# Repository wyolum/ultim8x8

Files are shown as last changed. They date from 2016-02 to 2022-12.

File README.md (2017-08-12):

# ultim8x8

ultim8x8 is an APA102 RGB LED based panel consisting of 8x8 matrix. Panels can be chained to produce larger matrices. Besides +5V and GND, each board requires a CLocK and DATa signal. Each board has CLocK and DATa IN and OUT terminals. When cascading boards, the OUT from one board goes to the IN of the next board.

Each LED can require up to 60mA current at 5V for White light at full brightness. This means driving ALL the 64 LEDs at full brightness White color will require 3.8A Amps. You can get away with lower Amps if you drive LEDs at lower brightness or don't light them all up at the same time.

Boards can be cascaded using several methods. Simplest, which requires no soldering, is to screw in the supplied metal posts to the terminals marked +5V, GND, DI__A, CI__A, DO__H and CO__H. The Boards can then be interconnected using the ultim_BUS busbar, or copper tape stuck over a piece of acrylic.

When running at low Amps or driving a single board, the 4 pin 0.1" pitch header can be used.

## kicad

* [ultim8x8_v0](/kicad/ultim_8x8_v0) - first version, Main hardware design files. Schematic, Layout etc. (deprecated)
* [ultim8x8_v1](/kicad/ultim_8x8_v1) - second version, Main hardware design files. Schematic, Layout etc. (deprecated)
* [ultim8x8_v2](/kicad/ultim_8x8_v2) - third version, Main hardware design files. Schematic, Layout etc. (current)

* [ultim_bus_v1](/kicad/ultim_bus_v1) - first version, Hardware design files for a bus bar to inter-connect ultim8x8's (deprecated)
* [ultim_bus_v2](/kicad/ultim_bus_v2) - second version, Hardware design files for a bus bar to inter-connect ultim8x8's (deprecated)
* [ultim_bus_v3](/kicad/ultim_bus_v3) - third version, Hardware design files for a bus bar to inter-connect ultim8x8's (deprecated)
* [ultim_bus_v4](/kicad/ultim_bus_v4) - fourth version, Hardware design files for a bus bar to inter-connect ultim8x8's (deprecated)
* [ultim_bus_v5](/kicad/ultim_bus_v5) - fifth version, Hardware design files for a bus bar to inter-connect ultim8x8's (current)

* [ultim_bus_conn](/kicad/ultim_bus_conn) - connector strips to join multiple ultim__bus_bars

* [featherboard](/kicad/featherboard) - first version, Interface board to connect Adafruit Feather Huzzah board to ultim8x8
* [feather_v2](/kicad/feather_v2) - second version, Interface board to connect Adafruit Feather Huzzah board to ultim8x8
* [feather_v3](/kicad/feather_v3) - third version, Interface board to connect Adafruit Feather Huzzah board to ultim8x8

* [ultim8x8_data](/kicad/ultim8x8_data) - Data sheets, logos etc

## fabricate

* [buckle](/fabricate/buckle) - 3D CAD files for a Belt Buckle.
* [featherboard_case](/fabricate/featherboard_case) - 3D CAD files for a "wireless" ultim8x8 brick

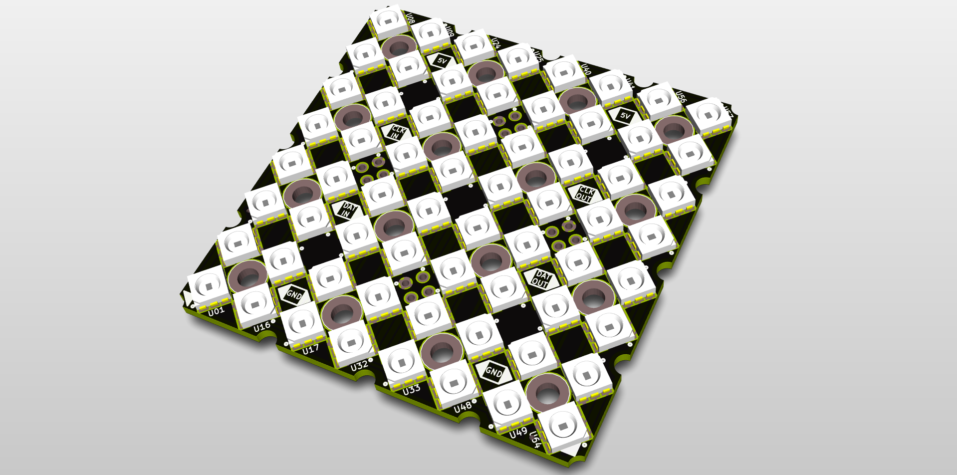
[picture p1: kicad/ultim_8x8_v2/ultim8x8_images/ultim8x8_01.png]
ultim8 top


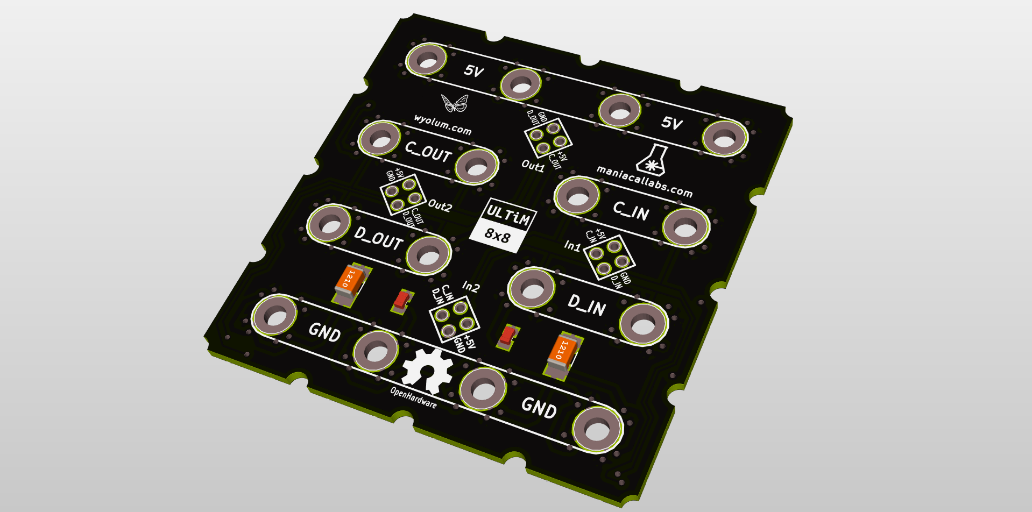
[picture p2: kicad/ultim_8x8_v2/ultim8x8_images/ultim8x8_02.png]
ultim8 bottom


License
-------
[CERN Open Hardware Licence v1.2 ]

[CERN Open Hardware Licence v1.2 ]:http://www.ohwr.org/attachments/2388/cern_ohl_v_1_2.txt

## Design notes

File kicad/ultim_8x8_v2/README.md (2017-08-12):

# ultim_8x8

ultim8x8 is an APA102 RGB LED based panel consisting of 8x8 matrix. Panels can be chained to produce larger matrices. Besides +5V and GND, each board requires a CLocK and DATa signal. Each board has CLocK and DATa IN and OUT terminals. When cascading boards, the OUT from one board goes to the IN of the next board.

Each LED can require up to 60mA current at 5V for White light at full brightness. This means driving ALL the 64 LEDs at full brightness White color will require 3.8A Amps. You can get away with lower Amps if you drive LEDs at lower brightness or don't light them all up at the same time.

Boards can be cascaded using several methods. Simplest, which requires no soldering, is to screw in the supplied metal posts to the terminals marked +5V, GND, D_IN, C_IN, D_OUT and C_OUT. The Boards can then be interconnected using the ultim_BUS busbar, or copper tape stuck over a piece of acrylic.

When running at low Amps or driving a single board, the 4 pin 0.1" pitch headers can be used. There are two pairs of headers marked In1/Out1 and In2/Out2.

ultim_8x8 top

ultim_8x8 top

License
-------
[CERN Open Hardware Licence v1.2 ]

[CERN Open Hardware Licence v1.2 ]:http://www.ohwr.org/attachments/2388/cern_ohl_v_1_2.txt

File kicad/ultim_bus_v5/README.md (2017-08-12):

# ultim_bus

A PCB "bus bar" to allow three ultim8x8 modules to be connected easily. Mouse bites allow it to be snapped off easily. With some imagination, can be used to expand to larger matrices.

The first panel can be populated with a Huzzah. There are six SMD switches connected to 14, 12, 13, 15, 0, 16, 2 on the Huzzah, with pull up resistors (SMD 0805). Switch functions can be arbitrarily assigned in code.

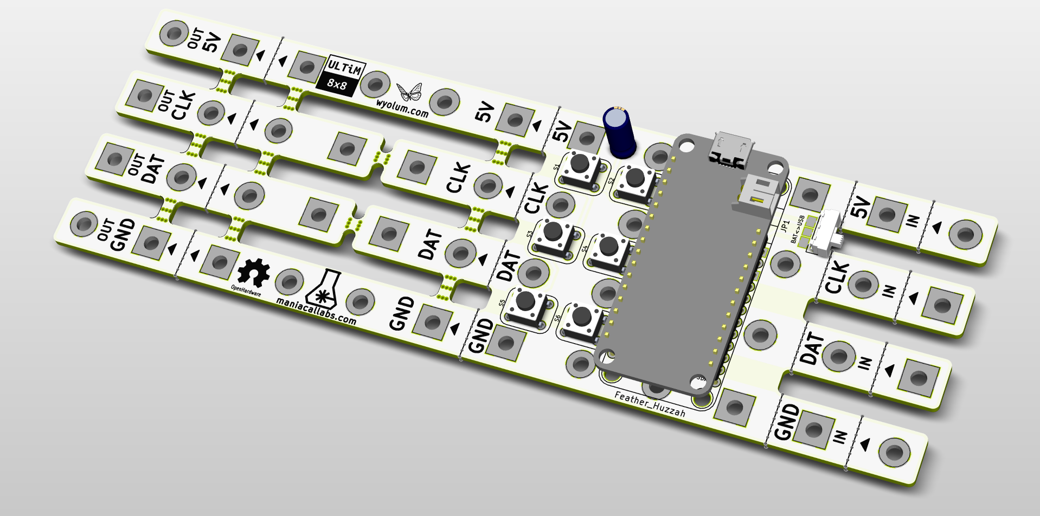
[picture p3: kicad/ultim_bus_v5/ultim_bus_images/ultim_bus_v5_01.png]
ultim_bus top


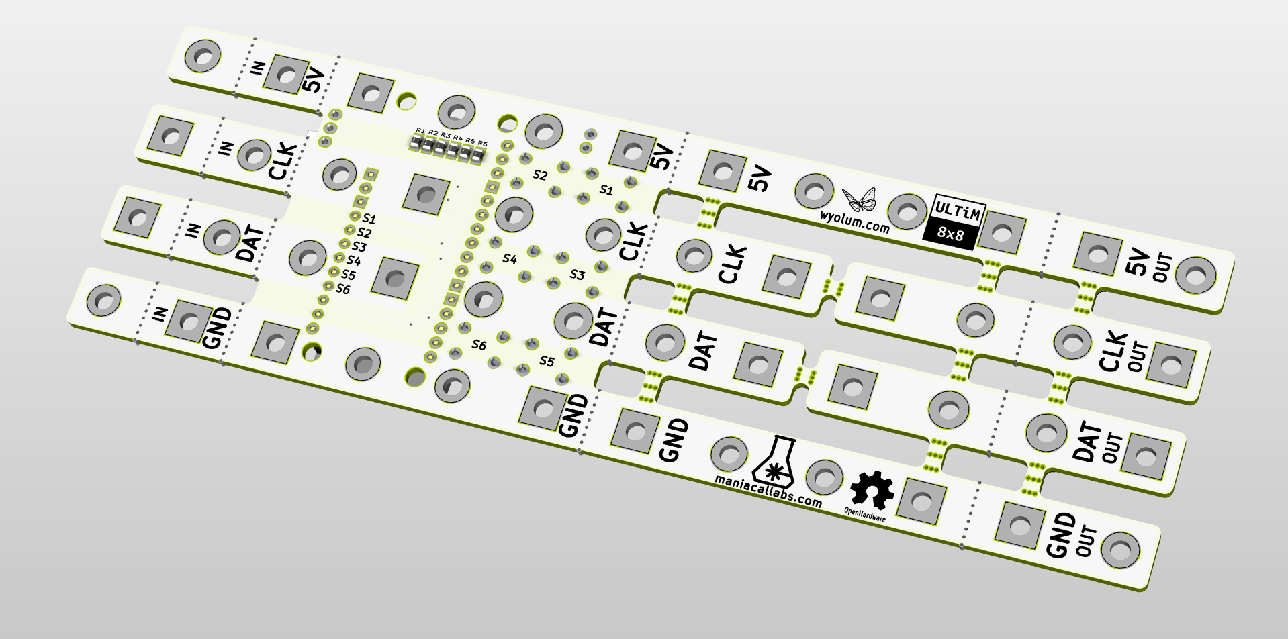
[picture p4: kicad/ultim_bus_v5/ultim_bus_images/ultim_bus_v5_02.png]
ultim_bus top


License
-------
[CERN Open Hardware Licence v1.2 ]

[CERN Open Hardware Licence v1.2 ]:http://www.ohwr.org/attachments/2388/cern_ohl_v_1_2.txt

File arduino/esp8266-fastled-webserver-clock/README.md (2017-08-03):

Ultim8x8 RGB LED Panel + FastLED + ESP8266 Web Server
=========

Control an [ULTiM8x8 RGB LED Panel] with an ESP8266 via a web browser.

[Demo Video](https://www.youtube.com/watch?v=xigy7J_K7Aw):

Demo Video (http://www.youtube.com/watch?v=xigy7J_K7Aw)

Hardware
--------

[Adafruit Feather HUZZAH with ESP8266 WiFi]

Adafruit Feather HUZZAH with ESP8266 WiFi (https://www.adafruit.com/products/2821)

[ULTiM8x8 RGB LED Panel]

ULTiM8x8 RGB LED Panel (https://www.crowdsupply.com/maniacal-labs-wyolum/ultim8x8)

Features
--------
* Turn the LEDs on and off
* Adjust the brightness
* Change the display pattern
* Adjust the color

Web App
--------

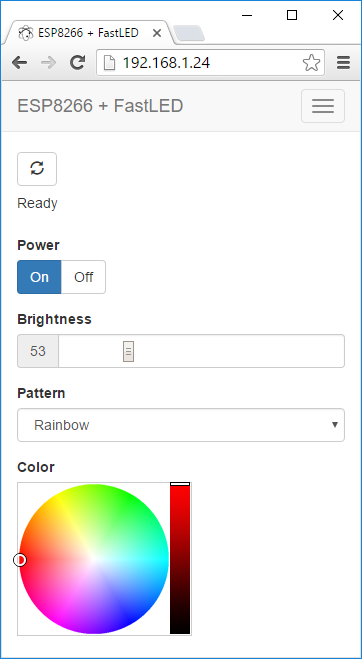
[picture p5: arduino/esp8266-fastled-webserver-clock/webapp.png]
Web App


Patterns are requested by the app from the ESP8266, so as new patterns are added, they're automatically listed in the app.

The web app is stored in SPIFFS (on-board flash memory).

The web app is a single page app with separate files for js and css, using [jQuery](https://jquery.com) and [Bootstrap](http://getbootstrap.com).  It has buttons for On/Off, a slider for brightness, a pattern selector, and a color picker (using [jQuery MiniColors](http://labs.abeautifulsite.net/jquery-minicolors)).  Event handlers for the controls are wired up, so you don't have to click a 'Send' button after making changes.  The brightness slider and the color picker use a delayed event handler, to prevent from flooding the ESP8266 web server with too many requests too quickly.

Installing
-----------

The web app needs to be uploaded to the ESP8266's SPIFFS.  You can do this within the Arduino IDE after installing the [Arduino ESP8266FS tool](https://github.com/esp8266/Arduino/blob/master/doc/filesystem.md#uploading-files-to-file-system).

With ESP8266FS installed run the sketch and then upload the web app using `ESP8266 Sketch Data Upload` command in the Arduino Tools menu.

Compression
-----------

The web app files can be gzip compressed before uploading to SPIFFS by running the following command:

`gzip -r data/`

The ESP8266WebServer will automatically serve any .gz file.  The file index.htm.gz will get served as index.htm, with the content-encoding header set to gzip, so the browser knows to decompress it.  The ESP8266WebServer doesn't seem to like the Glyphicon fonts gzipped, though, so I decompress them with this command:

`gunzip -r data/fonts/`

REST Web services
-----------------

The firmware implements basic [RESTful web services](https://en.wikipedia.org/wiki/Representational_state_transfer) using the ESP8266WebServer library.  Current values are requested with HTTP GETs, and values are set with POSTs using query string parameters.  It can run in connected or standalone access point modes.

[ULTiM8x8 RGB LED Panel]:https://www.crowdsupply.com/maniacal-labs-wyolum/ultim8x8
[Adafruit Feather HUZZAH with ESP8266 WiFi]:https://www.adafruit.com/products/2821

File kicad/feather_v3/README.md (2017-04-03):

# feather_v3

An add-on board to the Ultim8x8 LED Matrix for mounting an Adafruit Feather M0.

Use 4 pin male headers on ultim8x8 at either of two possible locations -- Input1/Output1 or Input2/Output2

Use a 2.54mm pitch slide switch/header+jumper mounted either at JP1 or JP2, to select between USB supply or BAT (external LiPo).

Instead of using a Switch, use shorting pads near the switch pads to permanently select one of the two supply options - USB or BAT.

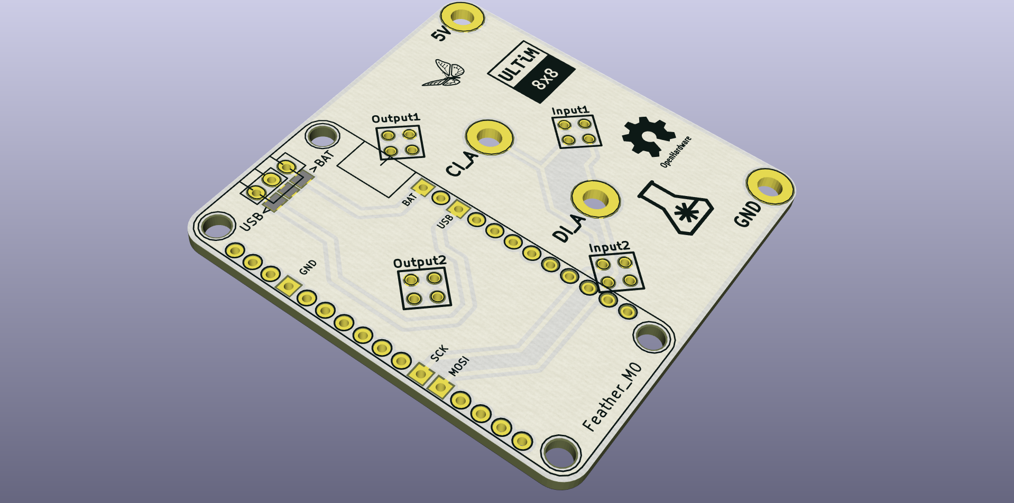
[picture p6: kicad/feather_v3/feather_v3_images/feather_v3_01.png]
Feather board top


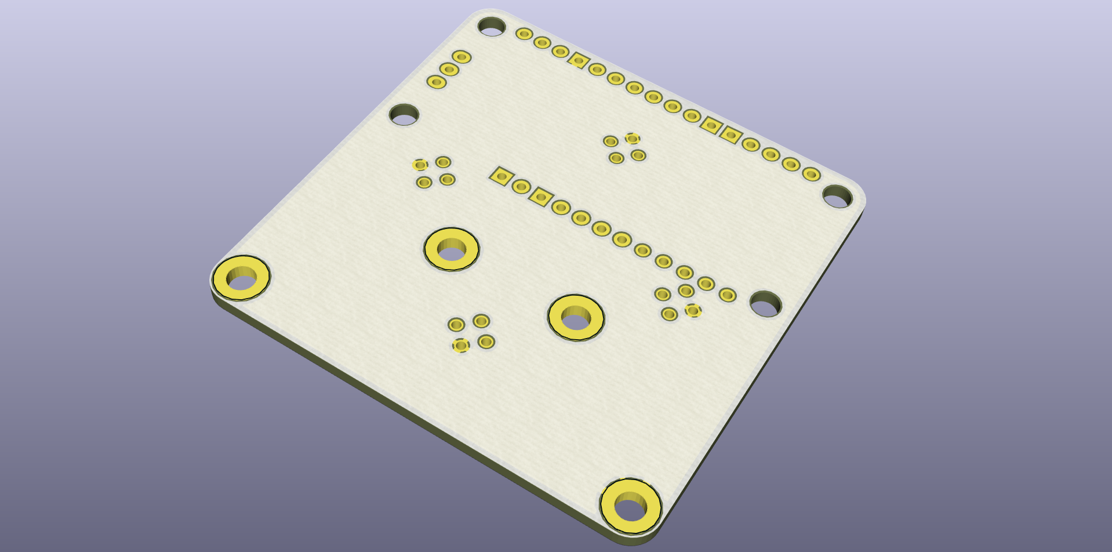
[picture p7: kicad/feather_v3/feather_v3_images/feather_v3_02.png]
Feather board bot


License
-------
[CERN Open Hardware Licence v1.2 ]

[CERN Open Hardware Licence v1.2 ]:http://www.ohwr.org/attachments/2388/cern_ohl_v_1_2.txt

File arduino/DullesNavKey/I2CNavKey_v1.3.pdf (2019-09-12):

www.duppa.net

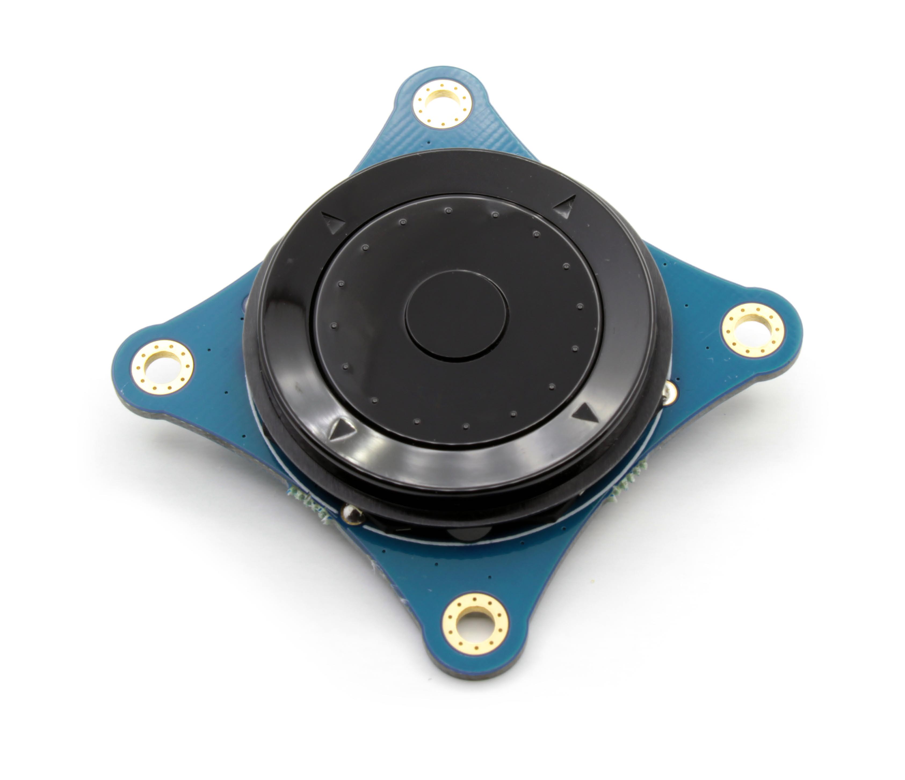
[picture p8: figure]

# I2CNavKey

## HW V1.1

August 1, 2019

Document written in LATEX

www.duppa.net | I2CNavKey

# Revision History

Revision | Date | Author(s) | Description
1.3 | 01.08.19 | Simone | Small changes on this document layout
1.2 | 09.07.19 | Simone | Fixed the numbering of the gamma type
1.1 | 26.05.19 | Simone | Added the pull-up resistors jumpers and new photos
1.0 | 08.04.19 | Simone | First version

# Contents

1 Device Overview | 3
2 Registers | 13
3 Reference | 28
4 Issues | 29
5 Schematic | 30

# 1. Device Overview

The I2CNavKey is a small board that includes a 7 functions joypad.
The joypad has 4 directional keys plus a central button and a rotary ring. It is controllable with the I²C bus, and it’s possible to configure 16 different I²C addresses.

The I2CNavKey has also 3 configurable GPIOs with the same footprint of RGB LED. This 3 GPIOs can be configured independently in 4 different way: input, output, PWM and analog input.

Since the I2CNavKey is a I²C slave, it has a series of 8 bit registers where it’s possible to configure different parameters, it’s also possible to detect when the buttons are pressed or when the ring is rotated.
It also has an open-drain output pin used as interrupt output. This pin is used to notify to the master when some event happens in the I2CNavKey, the source of interrupt can be customized.

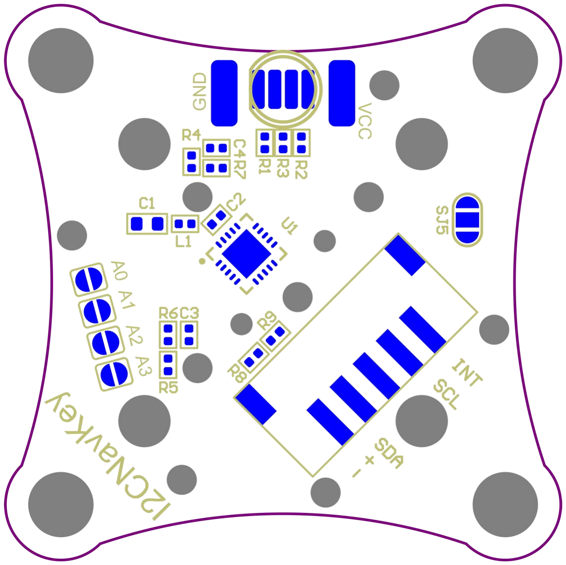
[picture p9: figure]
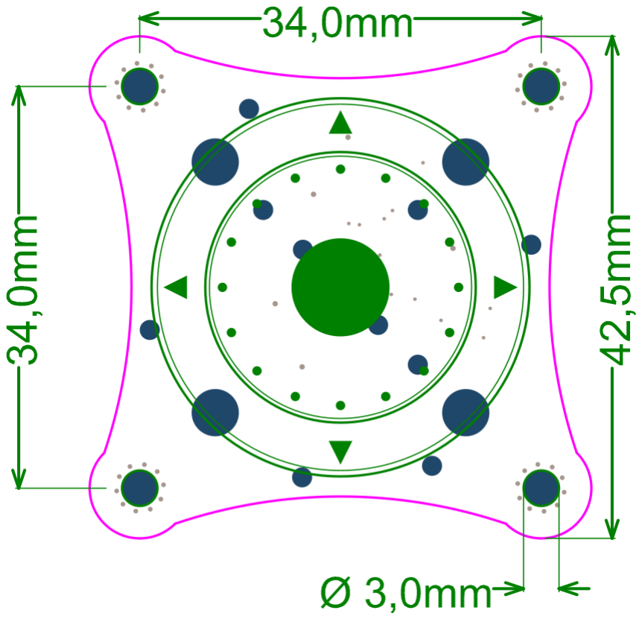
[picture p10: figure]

Figure 1.1: Dimension | Figure 1.2: Bottom view of the board

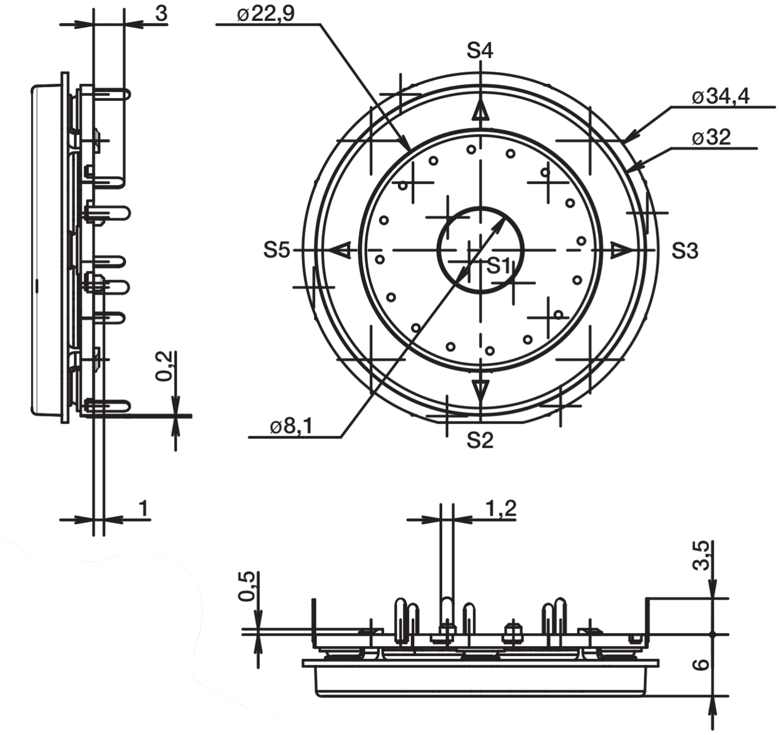
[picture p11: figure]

Figure 1.3: Dimension of the joypad: TSWB-3N-CB222 LFS from C&K

## 1.1 Electrical characteristics

Parameter | Symbol | Min | Max
Supply voltage | VDD | 3V | 5V
2C input-low level I | VIL | 0 | 0.3 * VDD
2C input-high level I | VIH | 0.8 * VDD | VDD
2C clock input frequency I | fSCL | | 400kHz
Supply current (LEDs off) | IDD | | 1.8mA
Interrupt pull-up resistor | RINT | 15kΩ | 120kΩ

## 1.2 Connection

Figure 1.4 shows the pin-out of the I2CNavKey.

Pin | I/O Type | Function
GND | Power | Ground reference for logic
Vcc | Power | Positive supply for logic
SDA | I/O | 2C data I
SCL | I | 2C clock I
INT | OD | Open-drain interrupt output

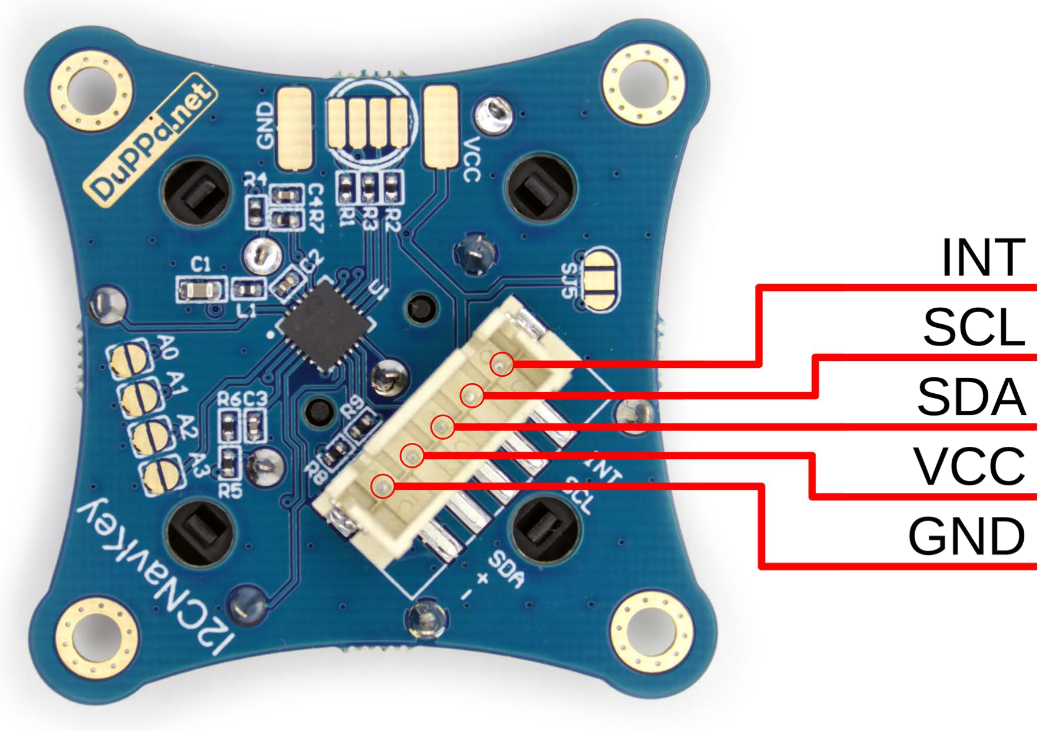
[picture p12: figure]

Figure 1.4: Pinout of the board

There are a 5 pins JST XH connector where it is possible to connect the I2CNavKey to the master. In order to avoid I

2C address conflict with other devices on the bus, the address of each device must be different. In the section 1.3, it is described how to set the address.

## 1.3 I

## 2C interface

The I2CNavKey is a I²C slave, it’s possible to the set 16 different addresses. All of the 7-bit address can be customized by soldering the jumpers A0 - A3 on the bottom of the board. When the jumper is open, it means a logic 0. if jumper is shorted it means a logic 1.

I

2C address

7 | 6 | 5 | 4 | 3 | 2 | 1 | 0
0 | 0 | 1 | A3 | A2 | A1 | A0 | R/W

For example in the figure 1.6 the jumper A0 and A2 are shorted and the 7-bit I²C address is 21 in decimal or 0x15 in hexadecimal or 0b00010101 in binary.

The I2CNavKey has I²C pull-up resistors, by default they are not enabled. In order to enable the resistor the jumper SJ5 must be soldered.
This must be done in case that the master doesn’t have these resistors and must be enabled only one I2CNavKey in a chain. A typical value of this resistors are 4.7kΩ.
In the figure 1.6 is showed how to short the jumper SJ5.

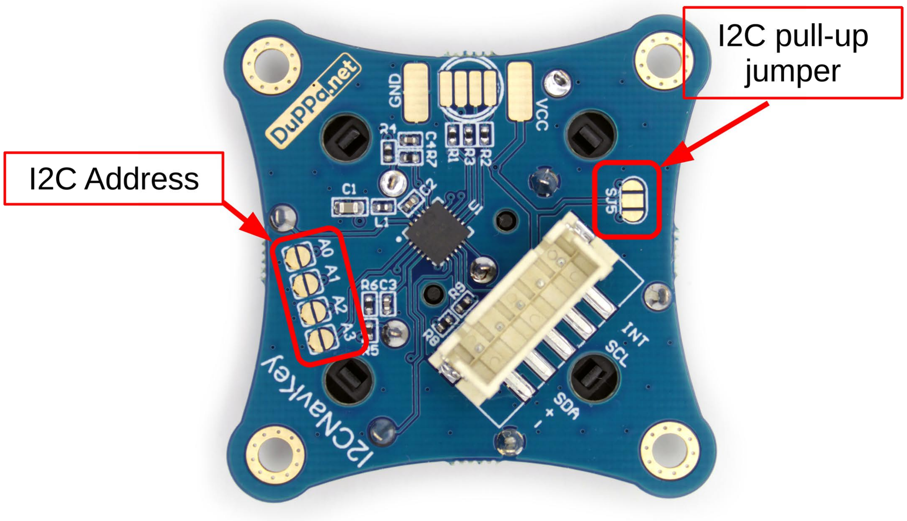
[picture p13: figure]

Figure 1.5: Jumper location of the pull-up resistor and of the address

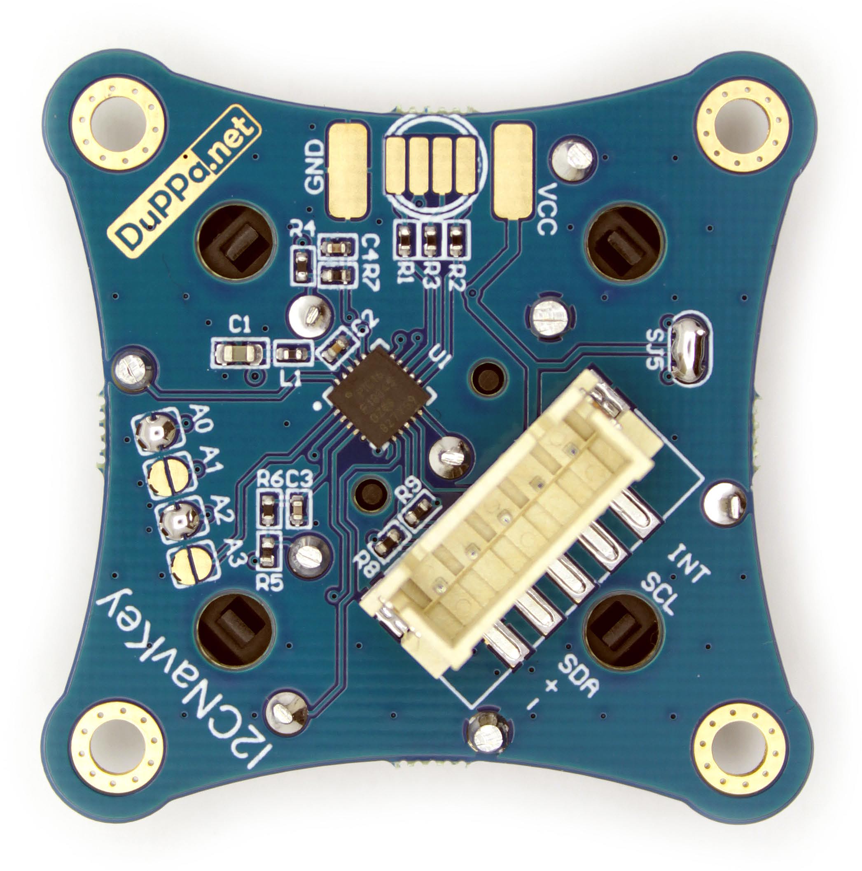
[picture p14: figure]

Figure 1.6: Example of jumper soldered: A0 and A2 shorted and also the SJ5 is shorted enabling the pull-up resistors

## 1.4 Joypad

On the I2CNavKey, there is a joypad with 7 functions:

- 4 directional buttons: up, down, left and right
- 1 central button
- Central wheel that can be rotated left and right, and it has 12 pulses per rotation.

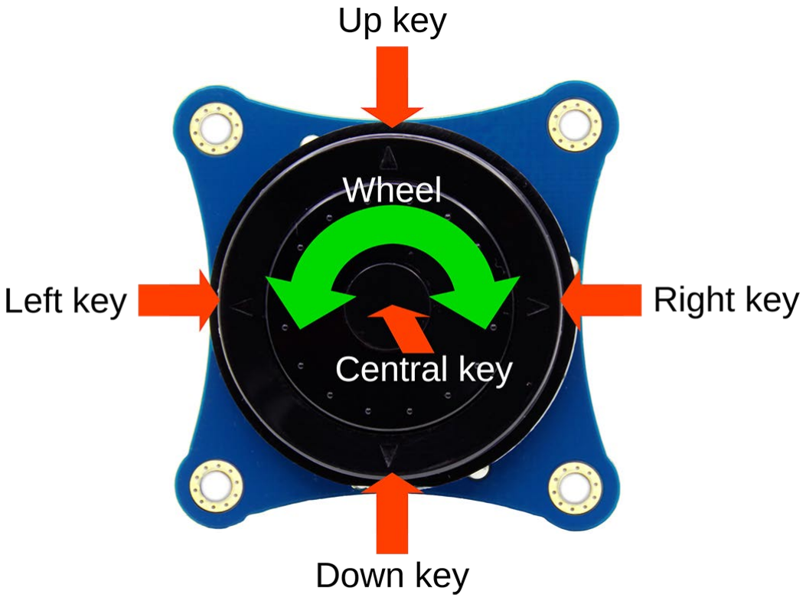
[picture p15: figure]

Figure 1.7: 7 function of the joypad

### 1.4.1 Buttons

When a button is pressed, the specific bit is set in the register ISTATUS. Every button has 2 specific bits because it’s possible to detect when the button is pressed and when is released.
The central button has also the possibility to read a fast double push by setting a window time in the register DPPERIOD. When a double push is made inside of the DPPERIOD window, the bit SCTRDP is set and it is possible to read in the ISTATUS register.
If the DPPERIOD is 0, the double push function is disabled.

### 1.4.2 Encoder

For reading the rotary encoder movement, there are 4 of 32bit registers: CVAL, CMAX, CMIN and ISTEP. All of these 4 registers can be configured to work as 32bit int or as IEEE 754 floating number, this format can be set in the GCONF register.
The counter limits are the following:
- 32bit INT: from −2147483648 to +2147483647
- IEEE 754 float: from −126.0 to +127.0

In case of 32bit int, it is not necessary to read all the 4 bytes, you can read only the first 8 bit or the first 16 bit. For example, if you want to count between 0 and 10, you can read only the first byte of the CVAL register. In this way, you can save I2C transactions.
Every time the encoder moves one step, the value of the CVAL register is increased or decreased of the value of ISTEP. The direction of the rotation decides if ISTEP is added or subtracted from CVAL.
CMAX and CMIN are used for setting a minimum and maximum thresholds of CVAL. In the GCONF register, there is WRAPE bit. This bit is used to enable or disable a wrap functionality of CVAL when it exceeds from the thresholds.
For example, if i configure the I2CNavKey as following:
- CVAL= 0
- CMAX = 5
- CMIN = -5
- ISTEP= 1

I will have CVAL is incremented of 1 at each rotation step of the encoder. The maximum value that CVAL can reach will be 5 while the minimum is -5. In the figure 1.8 shows the value of CVAL.

As showed in the figure 1.9, when WRAPE is set to 1 when CVAL reaches the value of 5, at the next increment CVAL it will be wrapped to -5.
Every time when the encoder is rotated one step and when CVAL reaches the thresholds, an interrupt is generated and it is possible to read in the register ISTATUS.

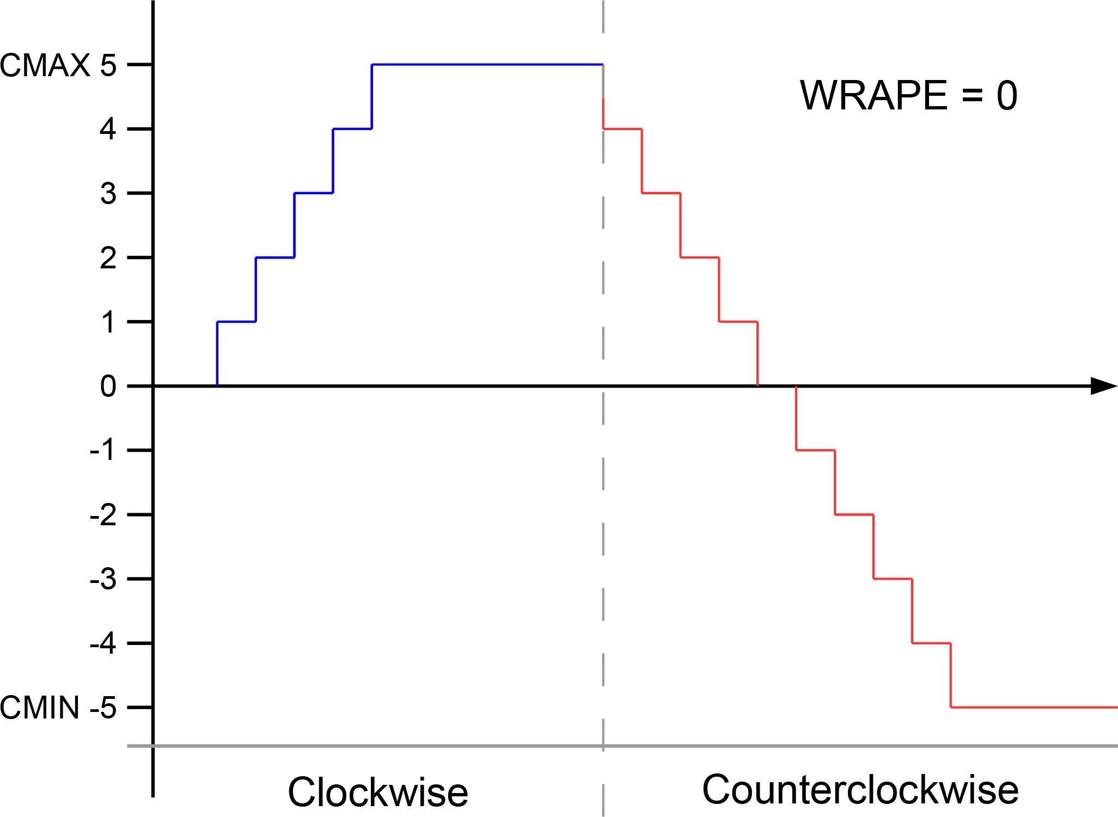
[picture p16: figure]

Figure 1.8: Blue and red lines are the CVAL values when the encoder is rotated and the WRAPE is disabled

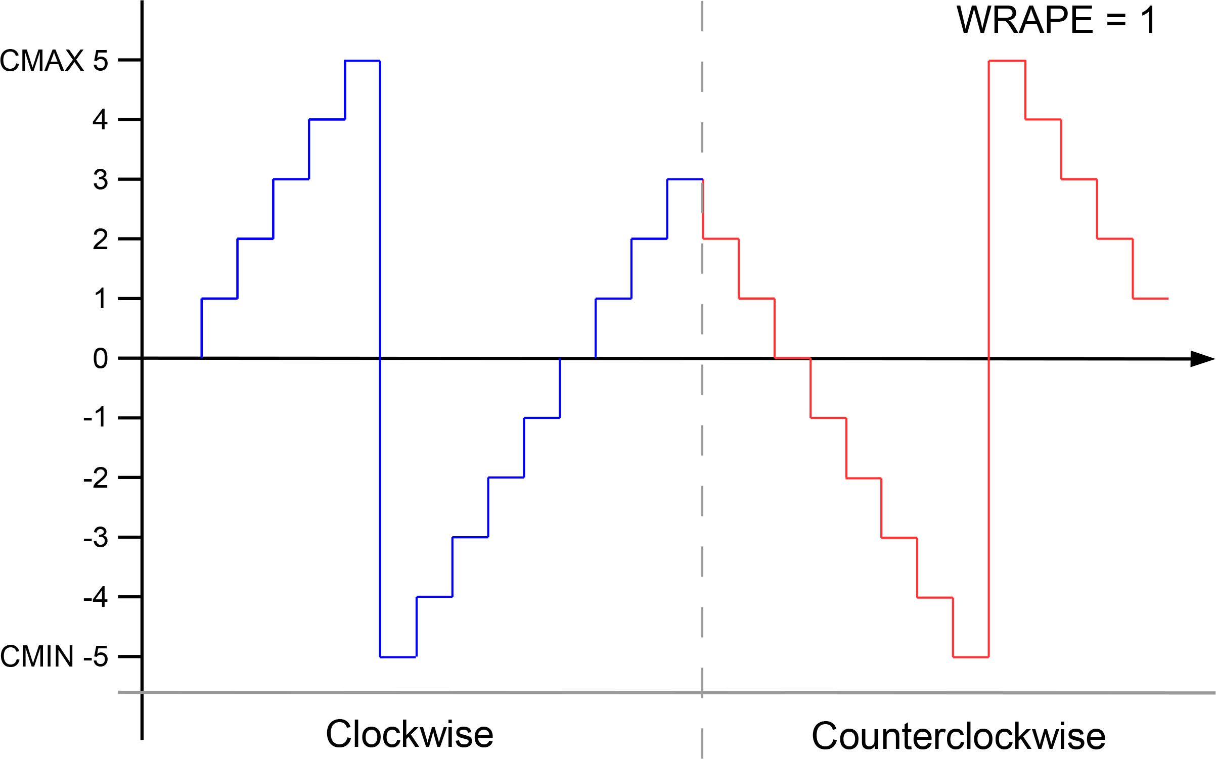
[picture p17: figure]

Figure 1.9: Blue and red line are the CVAL values when the encoder is rotate and the WRAPE is enabled

## 1.5 GP pins

There are 3 configurable GP pins, they are called GP1, GP2 and GP3. They have the same footprint of an 5mm RGB led. In figure 1.10, it is shown the position. Each pin can be configured to be:

- PWM: The pins is configured to be a PWM output.
- Analog input: The pins is configured to be an input of the internal ADC.
- GPIO output: The pins is configured to be a digital output.
- GPIO Input: The pin is configured to be a digital input.

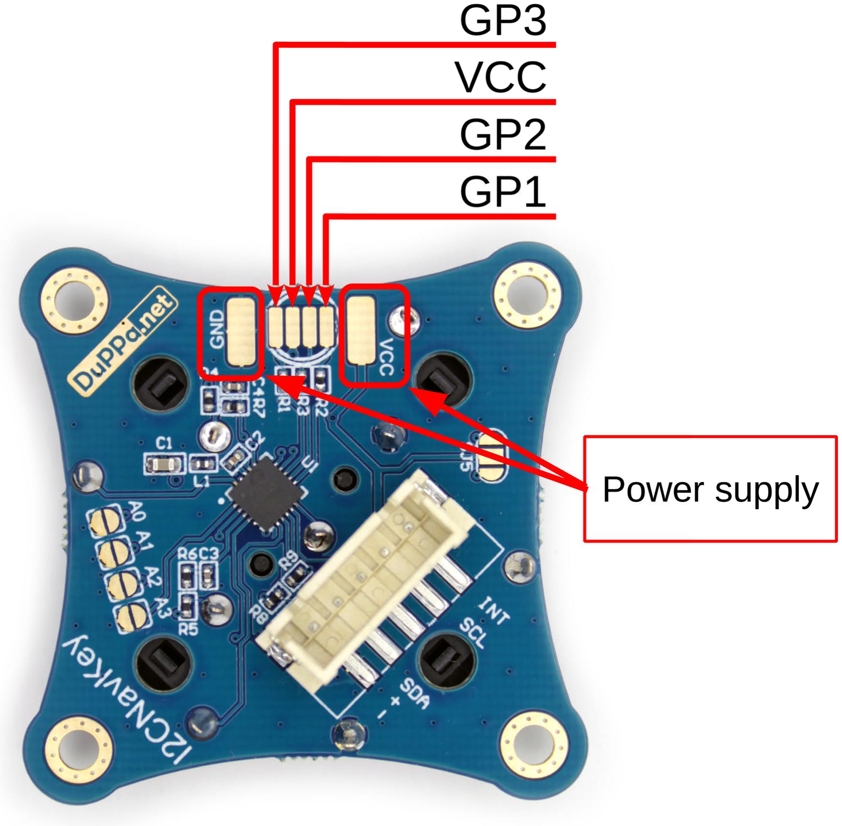
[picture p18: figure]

Figure 1.10: GP pins pinout

### 1.5.1 PWM mode

A GP pins can be configured in PWM mode by configuring the GPxMODE 1
to 0x00. The default configuration of the GP pins at the start up is PWM. Once the GP pin is configure in PWM mode, it is possible to set the PWM value by writing the corresponding GPxREG.
The PWM is resolution 10bit with a frequency of 31.25kHz, but the user can not access to the full resolution. It is possible to set a PWM value between 0% to 100% by writing 0 to 100 to the GPxREG.
The PWM is inverted, this means that when the PWM is 0% the GP pin voltage is VCC while when it is 100% the GP pin is GND.
In this way it is possible to connect a common anode RGB LED and have the LED off when the PWM is 0 and full on when the PWM is 100.
To each PWM outputs it is possible to configure a specific gamma correction by writing the register GAMMAGPx. There are 7 type of gamma correction:

✥ Gamma 1 (linear)

✥ Gamma 1.8

✥ Gamma 2.0

✥ Gamma 2.2

✥ Gamma 2.4

✥ Gamma 2.6

✥ Gamma 2.8

In the figure 1.11 is showed the relationship between the PWM at the full resolution and the PWM settable from the user.

1
In a register name the x correspond to 1, 2 or 3

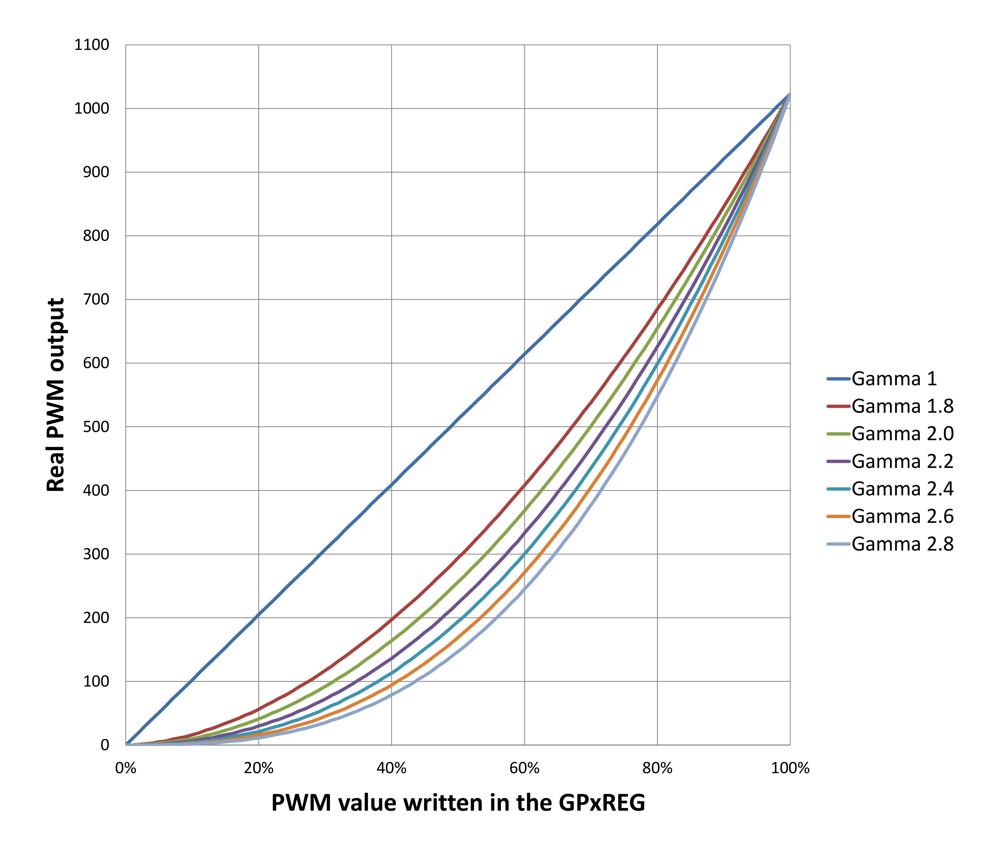
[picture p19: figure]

Figure 1.11: Possible gamma option

Fade function

The I2CNavKey has an auto fading features.
There is the register FADEGP, the value you write inside these registers is the step speed of the fading ramp, and it’s in ms. The fading will follow the selected gamma correction. If the value is 0, the fade feature is disabled. It means that when the new value of PWM is written, it is immediately updated to the output.
The fading process starts when a PWM value is written. Fading process is complete according to the PWM value you have set. When the internal fade PWM value is the same of the PWM value (it means that when fading is complete), an interrupt will be generated. Let’s make an example:

At the startup, i write as:

- GP1REG = 0
- GP2REG = 0
- GP3REG = 0
- FADEGP = 1

In above case, the LEDs of the encoder are off and the fade has 1ms step size.
Now i write as: GP1REG=100.
This moment, the ramp of the GP1REG starts and reaches the value 0x100 in 100ms. (the other LEDs remain OFF) When the ramp reaches 100, i get an interrupt from the INT pin.
After this, i write as: GP1REG=0x00. At this point, the fade ramp starts again and it will turn off the LED in 100ms, and an interrupt will be generated at the end.
The figure 1.12 is showing an example of the fade output when a PWM value is written in different moments, as well as when the interrupt of the fade is generated.

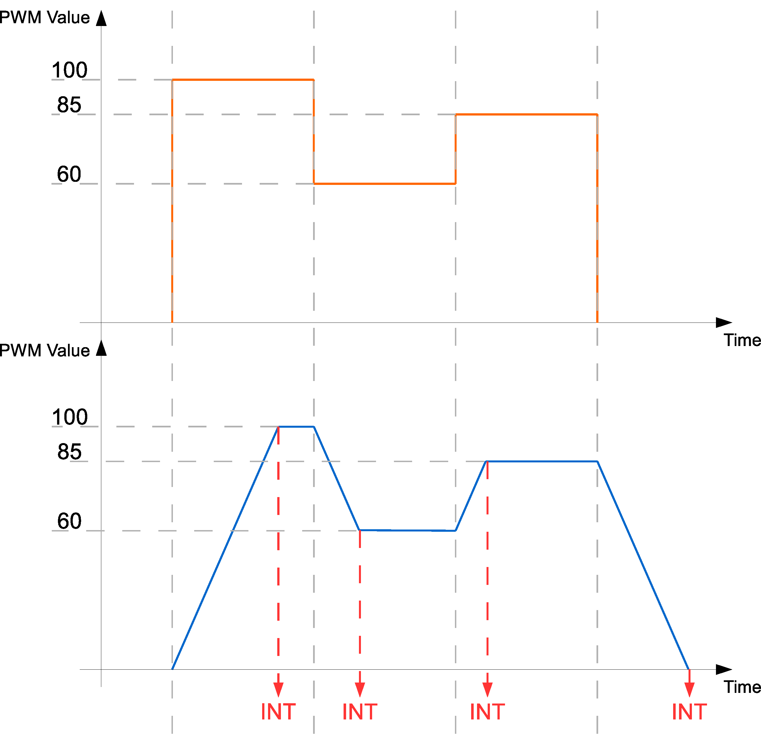
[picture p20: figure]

Figure 1.12: Time diagram of the fade output when writing on the PWM register

### 1.5.2 OUT mode

A GP pin can be configured as output mode by configuring the GPxMODE to 0x01. When the pin is configured as output writing 1 to GPxREG it make the GP pin high, while writing 0 make the pin low.

### 1.5.3 ADC mode

A GP pin can be configured as ADC mode by configuring the GPxMODE to 0x02. It is possible to read the ADC value by reading the register GPxREG. The content of the register updates every 10ms. When the GP pin is tied to 0 the ADC value is 0, while when the GP pin is tied to VCC the ADC value is 255. In this case it is also possible to enable the internal pull-up by writing 1 in the GPxPUL field.

### 1.5.4 IN mode

A GP pin can be configured as input mode by configuring the GPxMODE to 0x03. In this case, it is also possible to enable the internal pull-up by writing 1 in the GPxPUL field. It is also possible to configure the GP pin to generate an interrupt when the signal change. In the field GPxINT it possible to enable the interrupt when there is a positive edge, negative edge or both. The interrupt can be read in the register I2STATUS.It can be also reported to the INT pin by enabling the SINT2L bit.

## 1.6 EEPROM

The I2CNavKey has 256 bytes of EEPROM.
This memory is divided in two banks of 128 bytes. With the bit MBANK in the GCONF register, it is possible to choose either the bank 1 or the bank 2.
The memory area is between 0x80 and 0xFF address. To use the EEPROM, user only needs to perform reading or a writing in these address areas.
The writing time takes 4 - 5ms to be executed. Wait this time before sending other commands.

## 1.7 Interrupt

The I2CNavKey has multiple interrupt source previously described. When an interrupt is generated, the INT pin is tied low. By reading the register ISTATUS, the interrupts are cleared and the INT pin returns high.

The INT pin is open-drain output. Hence it requires an external pull-up resistor, or internal pull-up resistor can be enabled by setting the bit IPUD to 1.
In a chain of I2CNavKey all the INT pins can be connected together, like the pin of the I²C. When an interrupt occurs, user has to scan the boards in the chain to find who generates the interrupt.
With the register INTCONF, it is possible to enable or disable interrupt. When an interrupt is disabled, the corresponding bit is set, but the INT pin is not affected.

# 2. Registers

In this section, the internal registers of I2CNavKey is described.
The I2CNavKey has the auto increment feature. This means that after writing or reading a register, the internal address pointer is automatically incremented by one.
Address range | Name | Description | Dimension | Default value
0x00 | GCONF | General Configuration | 1 Byte | 0
0x01 | GP1CONF | GP 1 Configuration | 1 Byte | 0
0x02 | GP2CONF | GP 2 Configuration | 1 Byte | 0
0x03 | GP3CONF | GP 3 Configuration | 1 Byte | 0
0x04 0x05 | INTCONF | INT pin Configuration | 2 Byte | 0
0x06 - 0x07 | ISTATUS | Interrupt Status | 2 Byte | 0
0x08 | I2STATUS | Secondary interrupt status | 1 Byte | 0
0x09 | FSTATUS | Fade process status | 1 Byte | 0
0x0A - 0x0D | CVAL | Counter Value | 4 Byte | 0
0x0E - 0x11 | CMAX | Counter Max value | 4 Byte | 0
0x12 - 0x15 | CMIN | Counter Min value | 4 Byte | 0
0x16 - 0x19 | ISTEP | Increment step value | 4 Byte | 1
0x1A | GP1REG | I/O GP1 register | 1 Byte | 0
0x1B | GP2REG | I/O GP2 register | 1 Byte | 0
0x1C | GP3REG | I/O GP3 register | 1 Byte | 0
0x1D | DPPERIOD | Double push period | 1 Byte | 0
0x1E | FADEGP | Fade timer step of GPs ports | 1 Byte | 0
0x1F | GAMMAGP1 | Gamma correction on PWM of GP1 | 1 Byte | 0
0x20 | GAMMAGP2 | Gamma correction on PWM of GP2 | 1 Byte | 0
0x21 | GAMMAGP3 | Gamma correction on PWM of GP3 | 1 Byte | 0
0x70 | IDCODE | I2CNavKey unique code | 1 Byte | 0x5B
0x71 | VERSION | I2CNavKey version | 1 Byte | 0x11
0x80 - 0xFF | EEPROM | EEPROM memory | 128 Byte | 0

## 2.1 Configuration

### 2.1.1 General Configuration

GCONF Address: 0x00
7 | 6 | 5 | 4 | 3 | 2 | 1 | 0
R/W-0 | R/W-0 | R/W-0 | R/W-0 | R/W-0 | R/W-0 | R/W-0 | R/W-0
RESET | | MBANK | CKSRC | IPUD | DIRE | WRAPE | DTYPE

❖ DTYPE Data type of the register: CVAL, CMAX, CMIN and ISTEP.

1: The registers are considered float numbers IEEE 754

0: The registers are considered int 32bit

❖ WRAPE Enable counter wrap.

1: Wrap enable. When the counter value reaches the CMAX+1, restart to the CMIN and vice versa

0: Wrap disable. When the counter value reaches the CMAX or CMIN, the counter stops to increasing or decreasing

❖ DIRE Direction of the encoder when increment.

1: Rotate left side to increase the counter value

0: Rotate right side to increase the counter value

❖ IPUD Interrupt Pull-UP disable.

1: Disable

0: Enable

❖ CKSRC Enable or disable I²C clock stretch

1: Enabled

0: Disabled

❖ MBANK Select the EEPROM memory bank. Each bank are 128 byte wide

1: Second memory bank

0: First memory bank

❖ RST Reset of the I2CNavKey

1: Reset of the I2CNavKey. The RESET command takes 400us to be executed.

0: No reset

### 2.1.2 GP1 Configuration

GP1CONF Address: 0x01
7 | 6 | 5 | 4 | 3 | 2 | 1 | 0
R/W-0 | R/W-0 | R/W-0 | R/W-0 | R/W-0 | R/W-0 | R/W-0 | R/W-0
- | - | - | GP1INT | | GP1PUL | GP1MODE

❖ GP1MODE Configuration of the pin GP1

00: PWM output
01: GPIO output Push-Pull

10: Analog input
11: GPIO Input

❖ GP1PUL Enable or disable the internal pull-up.

0: Pull-UP disable

1: Pull-UP enabled

❖ GP1INT Configuration of the interrupt, available only when the pin is configured as input

00: Interrupt disabled

01: Interrupt on positive edge

10: Interrupt on negative edge

11: Interrupt on both edges

### 2.1.3 GP2 Configuration

GP2CONF Address: 0x02
7 | 6 | 5 | 4 | 3 | 2 | 1 | 0
R/W-0 | R/W-0 | R/W-0 | R/W-0 | R/W-0 | R/W-0 | R/W-0 | R/W-0
- | - | - | GP2INT | | GP2PUL | GP2MODE

❖ GP2MODE Configuration of the pin GP2

00: PWM output
01: GPIO output Push-Pull

10: Analog input
11: GPIO Input

❖ GP2PUL Enable or disable the internal pull-up.

0: Pull-UP disable

1: Pull-UP enabled

❖ GP2INT Configuration of the interrupt, available only when the pin is configured as input

00: Interrupt disabled

01: Interrupt on positive edge

10: Interrupt on negative edge

11: Interrupt on both edges

### 2.1.4 GP3 Configuration

GP3CONF Address: 0x03
7 | 6 | 5 | 4 | 3 | 2 | 1 | 0
R/W-0 | R/W-0 | R/W-0 | R/W-0 | R/W-0 | R/W-0 | R/W-0 | R/W-0
- | - | - | GP3INT | | GP3PUL | GP3MODE

❖ GP3MODE Configuration of the pin GP3

00: PWM output
01: GPIO output Push-Pull

10: Analog input
11: GPIO Input

❖ GP3PUL Enable or disable the internal pull-up.

0: Pull-UP disable

1: Pull-UP enabled

❖ GP3INT Configuration of the interrupt, available only when the pin is configured as input

00: Interrupt disabled

01: Interrupt on positive edge

10: Interrupt on negative edge

11: Interrupt on both edges

## 2.2 Interrupt output Configuration

This register is used to enable or disable the interrupt source selectively. When an interrupt event occurs, the INT pin goes low and the event is stored in the status register.

INTCONF Address: 0x04
15 | 14 | 13 | 12 | 11 | 10 | 9 | 8
R/W-0 | R/W-0 | R/W-0 | R/W-0 | R/W-0 | R/W-0 | R/W-0 | R/W-0
INT2 | IRMIN | IRMAX | IRDEC | IRINC | ICTRDP | ICTRP | ICTRR
Address: 0x05
7 | 6 | 5 | 4 | 3 | 2 | 1 | 0
R/W-0 | R/W-0 | R/W-0 | R/W-0 | R/W-0 | R/W-0 | R/W-0 | R/W-0
ILTP | ILTR | IRTP | IRTR | IDNP | IDNR | IUPP | IUPR

❖ IUPR Button UP release bit

1: Interrupt enabled when the UP button is released.

0: Interrupt disabled

❖ IUPP Button UP press bit

1: Interrupt enabled when the UP button is pressed.

0: Interrupt disabled

❖ IDNR Button DOWN release bit

1: Interrupt enabled when the DOWN button is released.

0: Interrupt disabled

❖ IDNP Button DOWN press bit

1: Interrupt enabled when the DOWN button is pressed.

0: Interrupt disabled

❖ IRTR Button RIGHT release bit

1: Interrupt enabled when the RIGHT button is released.

0: Interrupt disabled

❖ IRTP Button RIGHT press bit

1: Interrupt enabled when the RIGHT button is pressed.

0: Interrupt disabled

❖ ILTR Button LEFT release bit

1: Interrupt enabled when the LEFT button is released.

0: Interrupt disabled

❖ ILTP Button LEFT press bit

1: Interrupt enabled when the LEFT button is pressed.

0: Interrupt disabled

❖ ICTRR CENTRAL button release bit

1: Interrupt enabled when the CENTRAL button is released.

0: Interrupt disabled

❖ ICTRP Push button press bit

1: Interrupt enabled when the CENTRAL button is pressed.

0: Interrupt disabled

❖ ICTRDP CENTRAL button double press

1: Interrupt enabled when the CENTRAL button is double pressed.

0: Interrupt disabled

❖ IRINC Rotary encoder direction of increase

1: Interrupt enabled when the encoder is rotated in the direction of increase

0: Interrupt disabled

❖ IRDEC Rotary encoder direction of decrease

1: Interrupt enabled when the encoder is rotated in the direction of decrease

0: Interrupt disabled

❖ IRMAX CVAL reaches CMAX bit

1: Interrupt enabled when CVAL reaches CMAX

0: Interrupt disabled

❖ IRMIN CVAL reaches CMIN bit

1: Interrupt enabled when CVAL reaches CMIN

0: Interrupt disabled

❖ INT2 Enable the secondary interrupts

1: Secondary interrupt enabled

0: Secondary interrupt disabled

## 2.3 Status

### 2.3.1 I2CNavKey Status

This register is only readable, when is read is automatically cleared.

ISTATUS Address: 0x06
15 | 14 | 13 | 12 | 11 | 10 | 9 | 8
R/W-0 | R/W-0 | R/W-0 | R/W-0 | R/W-0 | R/W-0 | R/W-0 | R/W-0
SINT2 | SRMIN | SRMAX | SRDEC | SRINC | SCTRDP | SCTRP | SCTRR
Address: 0x07
7 | 6 | 5 | 4 | 3 | 2 | 1 | 0
R/W-0 | R/W-0 | R/W-0 | R/W-0 | R/W-0 | R/W-0 | R/W-0 | R/W-0
SLTP | SLTR | SRTP | SRTR | SDNP | SDNR | SUPP | SUPR

❑ SUPR Button UP release bit

1: UP button is released

0: UP button is not released

❑ SUPP Button UP press bit

1: UP button is pressed

0: UP button is not pressed

❑ SDNR Button DOWN release bit

1: DOWN button is released

0: DOWN button is not released

❑ SDNP Button DOWN press bit

1: DOWN button is pressed

0: DOWN button is not pressed

❑ SRTR Button RIGHT release bit

1: RIGHT button is released

0: RIGHT button is not released

❑ SRTP Button RIGHT press bit

1: RIGHT button is pressed

0: RIGHT button is not pressed

❑ SLTR Button LEFT release bit

1: LEFT button is released

0: LEFT button is not released

❑ SLTP Button LEFT press bit

1: LEFT button is pressed

0: LEFT button is not released

❑ SCTRR CENTRAL button release bit

1: CENTRAL button is released

0: CENTRAL button is not released

❑ SCTRP CENTRAL button press bit

1: CENTRAL button is pressed

0: CENTRAL button is not pressed

❑ SCTRDP CENTRAL button double press

1: CENTRAL button is double pressed

0: CENTRAL button is not double pressed

❑ RINC Rotary encoder is rotated in the increase direction

1: Encoder is rotated

0: Encoder is not rotated

❑ RDEC Rotary encoder is rotated in the decrease direction

1: Encoder is rotated

0: Encoder is not rotated

❑ RMAX Status of the counter value

1: CVAL reaches the CMAX value

0: CVAL is below the CMAX value

❑ RMIN Status of the counter value

1: CVAL reaches the CMIN value

0: CVAL is above the CMIN value

❑ SINT2 Secondary interrupt status

1: Secondary interrupt event occurs

0: No secondary event occurs

### 2.3.2 Secondary interrupt status

In this register is possible to check the event of the fade process as well as the GP pins when is configured as input. This register if only readable, when is read is automatically cleared.

I2STATUS Address: 0x08
7 | 6 | 5 | 4 | 3 | 2 | 1 | 0
R-0 | R-0 | R-0 | R-0 | R-0 | R-0 | R-0 | R-0
- | FADE | EGP3 | | EGP2 | | EGP1

❑ GP1 Interrupt on the GP1 port.

00: No event occurs

01: Positive edge event

10: Negative edge event

❑ GP2 Interrupt on the GP2 port.

00: No event occurs

01: Positive edge event

10: Negative edge event

❑ GP3 Interrupt on the GP3 port.

00: No event occurs

01: Positive edge event

10: Negative edge event

❑ FADE Fade process interrupt.

1: Fade process event

0: No event in the fade process

### 2.3.3 Fade process status

With this register is possible to check the status of the PWM channel during the fade process. This register is only readable and the bits are set or cleared automatically during the fade process.

FSTATUS Address: 0x09
7 | 6 | 5 | 4 | 3 | 2 | 1 | 0
R-0 | R-0 | R-0 | R-0 | R-0 | R-0 | R-0 | R-0
- | - | - | - | - | FGP3 | FGP2 | FGP1

❑ FGP1 Fade status process of the GP1

1: Fade process is running

0: Fade process terminated

❑ FGP2 Fade status process of the GP2

1: Fade process is running

0: Fade process terminated

❑ FGP3 Fade status process of the GP3

1: Fade process is running

0: Fade process terminated

## 2.4 Encoder registers

These 4 registers are in 32bit format. It is possible to read/write a single byte independently, no need to read/write all the 4 bytes at time.
They can be also used in float mode IEEE 754, but the DTYPE bit must be set.

### 2.4.1 Counter Value

CVAL Address: 0x0A
31 | 30 | 29 | 28 | 27 | 26 | 25 | 24
R/W-0 | R/W-0 | R/W-0 | R/W-0 | R/W-0 | R/W-0 | R/W-0 | R/W-0
CVAL BYTE 4 <31 - 24>
Address: 0x0B
23 | 22 | 21 | 20 | 19 | 18 | 17 | 16
R/W-0 | R/W-0 | R/W-0 | R/W-0 | R/W-0 | R/W-0 | R/W-0 | R/W-0
CVAL BYTE 3 <23 - 16>
Address: 0x0C
15 | 14 | 13 | 12 | 11 | 10 | 9 | 8
R/W-0 | R/W-0 | R/W-0 | R/W-0 | R/W-0 | R/W-0 | R/W-0 | R/W-0
CVAL BYTE 2 <15 - 8>
Address: 0x0D
7 | 6 | 5 | 4 | 3 | 2 | 1 | 0
R/W-0 | R/W-0 | R/W-0 | R/W-0 | R/W-0 | R/W-0 | R/W-0 | R/W-0
CVAL BYTE 1 <7 - 0>

### 2.4.2 Counter Max

CMAX Address: 0x0E
31 | 30 | 29 | 28 | 27 | 26 | 25 | 24
R/W-0 | R/W-0 | R/W-0 | R/W-0 | R/W-0 | R/W-0 | R/W-0 | R/W-0
CMAX BYTE 4 <31 - 24>
Address: 0x0F
23 | 22 | 21 | 20 | 19 | 18 | 17 | 16
R/W-0 | R/W-0 | R/W-0 | R/W-0 | R/W-0 | R/W-0 | R/W-0 | R/W-0
CMAX BYTE 3 <23 - 16>
Address: 0x10
15 | 14 | 13 | 12 | 11 | 10 | 9 | 8
R/W-0 | R/W-0 | R/W-0 | R/W-0 | R/W-0 | R/W-0 | R/W-0 | R/W-0
CMAX BYTE 2 <15 - 8>
Address: 0x11
7 | 6 | 5 | 4 | 3 | 2 | 1 | 0
R/W-0 | R/W-0 | R/W-0 | R/W-0 | R/W-0 | R/W-0 | R/W-0 | R/W-0
CMAX BYTE 1 <7 - 0>

### 2.4.3 Counter Min

CMIN Address: 0x12
31 | 30 | 29 | 28 | 27 | 26 | 25 | 24
R/W-0 | R/W-0 | R/W-0 | R/W-0 | R/W-0 | R/W-0 | R/W-0 | R/W-0
CMIN BYTE 4 <15 - 8>
Address: 0x13
23 | 22 | 21 | 20 | 19 | 18 | 17 | 16
R/W-0 | R/W-0 | R/W-0 | R/W-0 | R/W-0 | R/W-0 | R/W-0 | R/W-0
CMIN BYTE 3 <7 - 0>
Address: 0x14
15 | 14 | 13 | 12 | 11 | 10 | 9 | 8
R/W-0 | R/W-0 | R/W-0 | R/W-0 | R/W-0 | R/W-0 | R/W-0 | R/W-0
CMIN BYTE 2 <15 - 8>
Address: 0x15
7 | 6 | 5 | 4 | 3 | 2 | 1 | 0
R/W-0 | R/W-0 | R/W-0 | R/W-0 | R/W-0 | R/W-0 | R/W-0 | R/W-0
CMIN BYTE 1 <7 - 0>

### 2.4.4 Increment step

ISTEP Address: 0x16
31 | 30 | 29 | 28 | 27 | 26 | 25 | 24
R/W-0 | R/W-0 | R/W-0 | R/W-0 | R/W-0 | R/W-0 | R/W-0 | R/W-0
ISTEP BYTE 4 <15 - 8>
Address: 0x17
23 | 22 | 21 | 20 | 19 | 18 | 17 | 16
R/W-0 | R/W-0 | R/W-0 | R/W-0 | R/W-0 | R/W-0 | R/W-0 | R/W-0
ISTEP BYTE 3 <7 - 0>
Address: 0x18
15 | 14 | 13 | 12 | 11 | 10 | 9 | 8
R/W-0 | R/W-0 | R/W-0 | R/W-0 | R/W-0 | R/W-0 | R/W-0 | R/W-0
ISTEP BYTE 2 <15 - 8>
Address: 0x19
7 | 6 | 5 | 4 | 3 | 2 | 1 | 0
R/W-0 | R/W-0 | R/W-0 | R/W-0 | R/W-0 | R/W-0 | R/W-0 | R/W-0
ISTEP BYTE 1 <7 - 0>

## 2.5 GPs registers

The usage of these register depends of the configuration of the GP pins:

- PWM Is possible to write the PWM value: 0 to 100.
- GPIO output: Is possible to write 1 or 0 for setting the output logic level.
- Analog input: Is possible to read the ADC value: 8 bit format.
- GPIO Input: Is possible to read the logic level of the output.

### 2.5.1 GP1 register

GP1REG Address: 0x1A
7 | 6 | 5 | 4 | 3 | 2 | 1 | 0
R/W-0 | R/W-0 | R/W-0 | R/W-0 | R/W-0 | R/W-0 | R/W-0 | R/W-0
GP1 Value <7 - 0>

### 2.5.2 GP2 register

GP2REG Address: 0x1B
7 | 6 | 5 | 4 | 3 | 2 | 1 | 0
R/W-0 | R/W-0 | R/W-0 | R/W-0 | R/W-0 | R/W-0 | R/W-0 | R/W-0
GP2 Value <7 - 0>

### 2.5.3 GP3 register

GP3REG Address: 0x1C
7 | 6 | 5 | 4 | 3 | 2 | 1 | 0
R/W-0 | R/W-0 | R/W-0 | R/W-0 | R/W-0 | R/W-0 | R/W-0 | R/W-0
GP3 Value <7 - 0>

## 2.6 Timing registers

This register are used for changing some timing parameter

### 2.6.1 Double push time

This register is used for setting the interval for the detection of the double push of the central button. The value is in ms × 10. When this register is 0 this function is disabled.

DPPERIOD Address: 0x1D
7 | 6 | 5 | 4 | 3 | 2 | 1 | 0
R/W-0 | R/W-0 | R/W-0 | R/W-0 | R/W-0 | R/W-0 | R/W-0 | R/W-0
PDPUSH <7 - 0>

### 2.6.2 Fade GP ports

This register is used for setting the fade speed of the GP ports. The value is in ms and indicate the time of one step. This register is working only if the GP port are configured in PWM

FADEGP Address: 0x1E
7 | 6 | 5 | 4 | 3 | 2 | 1 | 0
R/W-0 | R/W-0 | R/W-0 | R/W-0 | R/W-0 | R/W-0 | R/W-0 | R/W-0
FADEGP <7 - 0>

## 2.7 Gamma correction

This register is used for applying a gamma correction in case the GP port is used as PWM. It can be very useful when a LED is connected.

GAMMAGP1 Address: 0x1F
7 | 6 | 5 | 4 | 3 | 2 | 1 | 0
- | - | - | - | - | R/W-0 | R/W-0 | R/W-0
| | | | | GAMMAGP1 <2 - 0>

GAMMAGP2 Address: 0x20
7 | 6 | 5 | 4 | 3 | 2 | 1 | 0
- | - | - | - | - | R/W-0 | R/W-0 | R/W-0
| | | | | GAMMAGP2 <2 - 0>

GAMMAGP3 Address: 0x21
7 | 6 | 5 | 4 | 3 | 2 | 1 | 0
- | - | - | - | - | R/W-0 | R/W-0 | R/W-0
| | | | | GAMMAGP3 <2 - 0>

❑ GAMMAGPx Gamma curve selector for the GPx pins

000: Gamma 1

001: Gamma 1.8

010: Gamma 2.0

011: Gamma 2.2

100: Gamma 2.4

101: Gamma 2.6

110: Gamma 2.8

## 2.8 I2CNavKey unique code

This register contains an unique code that it’s used to identify the I2CNavKeyThis register is only readable and not ˙ writable.

IDCODE Address: 0x70
7 | 6 | 5 | 4 | 3 | 2 | 1 | 0
R-0 | R-1 | R-0 | R-1 | R-1 | R-0 | R-1 | R-1
IDCODE = 0x5B

## 2.9 I2CNavKey version

This register contains the version of the I2CNavKeyThis value will change in case of a new hardware or firmware ˙ release. This register is only readable and not writable.

VERSION Address: 0x71
7 | 6 | 5 | 4 | 3 | 2 | 1 | 0
R-0 | R-0 | R-0 | R-1 | R-0 | R-0 | R-0 | R-1
Version = 0x11

# 3. Reference

This project is open source, the HW and the FW as well as some examples can be found on GitHub: https://github.com/Fattoresaimon/I2CNavKey

# 4. Issues

# 5. Schematic

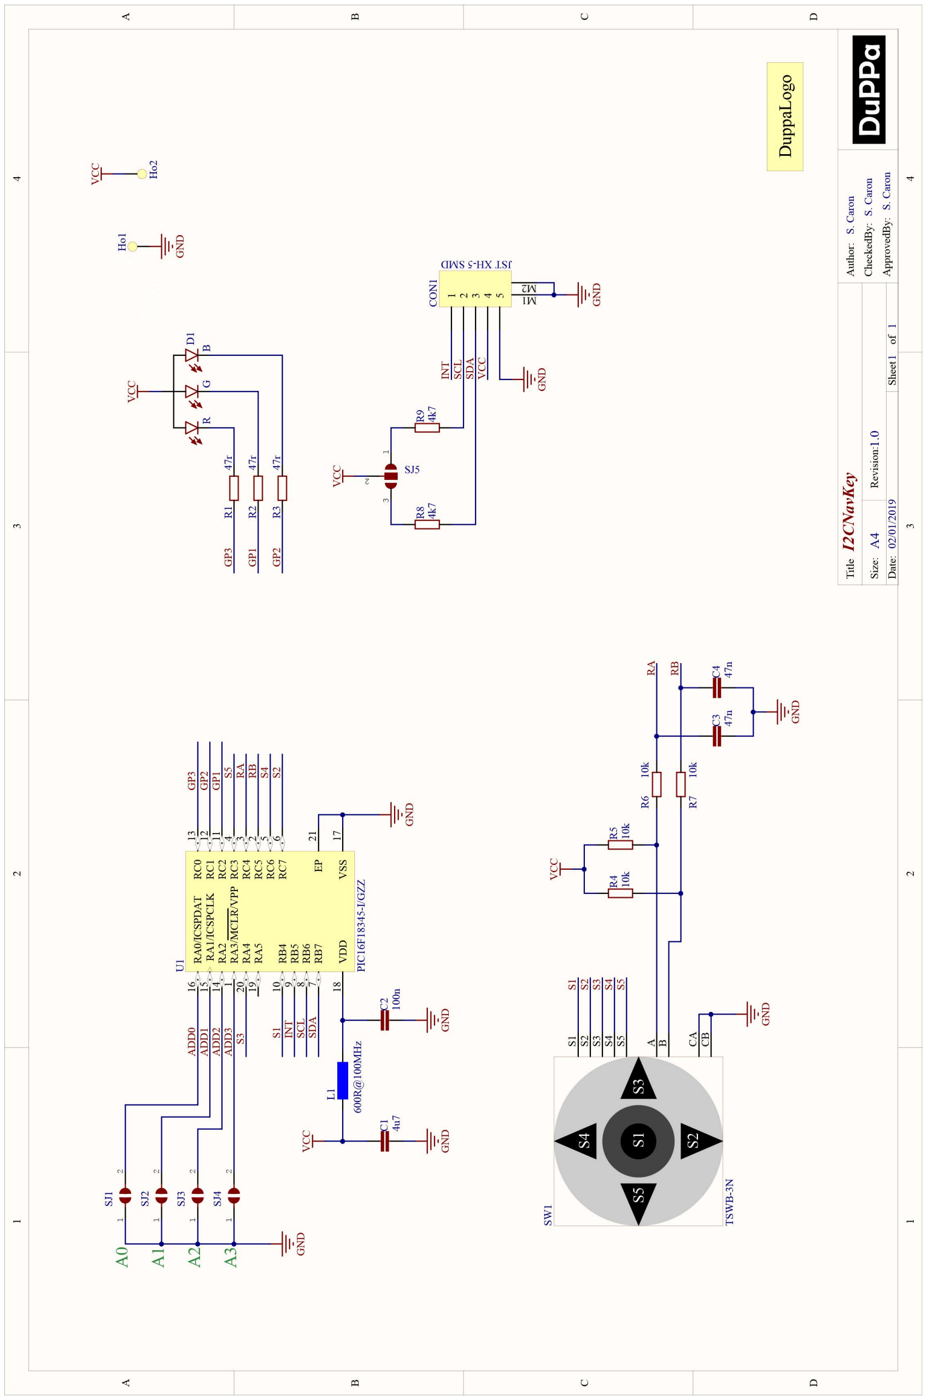
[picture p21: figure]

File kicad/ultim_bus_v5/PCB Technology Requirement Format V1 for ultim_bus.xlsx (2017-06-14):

深圳矽递科技有限公司 Seeed Technology Limited
PCB Technology Requirement Format
PCB Name & Version | ULTiM_bus
PCB Material PCB板材： | (Rigid)FR－4
PCB Size PCB大小： | inch | ( 7.00 ) × (2.20 )
PCB Layer PCB层数： | 2
Thickness PCB厚度：
 | 1.6mm
Copper Weight 铜厚： | 1oz
PCB Colour 阻焊颜色： |  | White白色
Silkscreen 字符颜色： |  | Black 黑色 | other:( )
Pads Finished 焊盘喷镀： | (Hasl-lead free) 无铅喷锡
Via solder mask 阻焊覆盖： |  | solder mask opening 过孔开窗
Minimum trace/space (mm) 最小线宽 | 0.254mm/0.254mm | Minimum hole size (mm) 最小孔径 | 0.635mm
Special requirements 特殊工艺： | No | (Put requirements here)
Comment:

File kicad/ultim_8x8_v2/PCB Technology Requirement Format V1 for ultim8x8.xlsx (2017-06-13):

深圳矽递科技有限公司 Seeed Technology Limited
PCB Technology Requirement Format
PCB Name & Version | ULTiM8x8
PCB Material PCB板材： | (Rigid)FR－4
PCB Size PCB大小： | inch | ( 2.40 ) × (2.40 )
PCB Layer PCB层数： | 2
Thickness PCB厚度：
 | 1.6mm
Copper Weight 铜厚： | 1oz
PCB Colour 阻焊颜色： | Black 黑色
Silkscreen 字符颜色： | White 白色 |  | other:( )
Pads Finished 焊盘喷镀： | (Hasl-lead free) 无铅喷锡
Via solder mask 阻焊覆盖： |  | solder mask opening 过孔开窗
Minimum trace/space (mm) 最小线宽 | 0.254mm/0.254mm | Minimum hole size (mm) 最小孔径 | 0.635mm
Special requirements 特殊工艺： | No | (Put requirements here)
Comment:

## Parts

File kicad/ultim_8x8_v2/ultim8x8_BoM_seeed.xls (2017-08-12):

Electronic Engineering BOM List
Product Name：ULTiM8x8
Version：V2.0
Issue Date：14/Jun/2017
Item No. (序号) | Reference Des (上件位置) | Qty (用量) | Catalog (分类） | Part_Description (规格描述) | Part_Value （元件值） | Part_Package （元件封装） | Manufacturers Name (使用厂牌名称) | Manufacturers Part No. (使用厂牌型号) | Distributors Name （供应商名称） | Distributors Part No. (供貨商型号) | Unit Price （单价） | Price Break To Use （价格分段的购买量） | Notes/Remark （备注）
Example（填写范例）
1 | U01 ~ U64 | 64 | OTHER | 5050 SMD RGB LED with built-in controller | APA102 | 5050 | Shiji Lighting | APA102C | Aliexpress | APA102C
2 | C1 , C3 | 2 | Capacitor | CAP CER 0.1UF 25V 10% X7R 0805 | 100nF, 25V | Surface Mount, MLCC (c0805) | Kemet | C0805C104K3RACTU | Digikey | 399-1168-1-ND |  |  | http://www.digikey.com/product-detail/en/C0805C104K3RACTU/399-1168-1-ND/411443
3 | C2, C4 | 2 | Capacitor | CAP TANT 47UF 10V 10% 1210 | 47uF, 10V | Surface Mount 1210 (3528 Metric) | AVX Corporation | TAJB476K010RNJ | Digikey | 478-1693-1-ND |  |  | http://www.digikey.com/product-detail/en/avx-corporation/TAJB476K010RNJ/478-1693-1-ND/564725
DO NOT POPULATE (KIT OF PARTS)
4 | P1, P2, P5, P6 | 2 | Connector | CONN HEADER 2x2 POS 0.100” Straight Through Hole | Input1, Input2, Output1,Output2 | Male Pin, Header, Unshrouded, Breakaway, 2x2 pin | Amphenol FCI | 67997-404HLF | Digikey | 609-3242-ND |  |  | http://www.digikey.com/product-detail/en/amphenol-fci/67997-404HLF/609-3242-ND/1878458
5 | -- | 2 | Connector | CONN HEADER FMALE 4PS .1" DL TIN | -- | CONN HEADER FMALE 4PS .1" DL TIN | Sullins Connector Solutions | PPTC022LFBN-RC | Digikey | S7070-ND |  |  | http://www.digikey.com/product-detail/en/sullins-connector-solutions/PPTC022LFBN-RC/S7070-ND/810209
6 | P3, P4, P7 ~ P12 | 8 | OTHER | Metal Stand Off, M3 x 10mm, FULLY threaded | 5V, GND, CI_A, DI_A, CO_H, DO_H | Metal Stand Off, M3 x 10mm, FULLY threaded | -- | -- | -- | --
7 | -- | 16 | OTHER | Screw, M3 x 6mm long, Allen Head | -- | Screw, M3 x 6mm long, Allen Head | -- | -- | -- | --
1. Recommended Distributor: Digi-Key, Mouser, Avnet Express, Farnell.
2. Catalog: Capacitor,Resister,Diode,Connector,Transistor,IC,PROTECTOR CATEGORY,OTHER
3. Required Fields: Item No, Reference Des, Qty, Catalog, Part_Value, Part Package
Optional Fields: Part_Description, Manufacturers Name, Manufacturers Part No, Distributors Name, Distributors Part No, Unit Cost, Price break to use, Notes/Remark

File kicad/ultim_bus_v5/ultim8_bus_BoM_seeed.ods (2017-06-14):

Electronic Engineering BOM List
Product Name：ULTiM8_bus
Version：V4.0
Issue Date：14/Jun/2017
Item No. (序号) | Reference Des (上件位置) | Qty (用量) | Catalog (分类） | Part_Description (规格描述) | Part_Value （元件值） | Part_Package （元件封装） | Manufacturers Name (使用厂牌名称) | Manufacturers Part No. (使用厂牌型号) | Distributors Name （供应商名称） | Distributors Part No. (供貨商型号) | Unit Price （单价） | Price Break To Use （价格分段的购买量） | Notes/Remark （备注）
Example（填写范例）
DO NOT POPULATE (KIT OF PARTS)
1 | H1 | 1 | Connector | Header socket (female) for Adafruit Feather M0, 16 position | Feather_M0 | CONN HEADER FEMALE 16PS .1" DL TIN | Sullins Connector Solutions | PPTC161LFBN-RC | Digikey | S7014-ND |  |  | https://www.digikey.com/product-detail/en/sullins-connector-solutions/PPTC161LFBN-RC/S7014-ND/810154
2 | H1 | 1 | Connector | Header socket (female) for Adafruit Feather M0, 12 position | Feather_M0 | CONN HEADER FEM 12POS.1" SGL TIN | Sullins Connector Solutions | PPTC121LFBN-RC | Digikey | S6100-ND |  |  | https://www.digikey.com/product-detail/en/sullins-connector-solutions/PPTC121LFBN-RC/S6100-ND/807231
3 | JP1 | 1 | OTHER | Switch, SPDT, Slide, 0.1” pitch (Switch can be SMD or through hole, vertical or horizontal, depending on requirement) | PWR_SEL | 0.1” pitch | APEM Inc. | MHSS1105 | Digikey | 679-1849-ND |  |  | https://www.digikey.com/product-detail/en/apem-inc/MHSS1105/679-1849-ND/1949465
4 | S1 ~ S6 | 6 | OTHER | SWITCH TACTILE SPST-NO 0.05A 24V Top Actuated Through Hole | SW-PB | 6.20mm x 6.20mm | TE Connectivity ALCOSWITCH Switches | 1825910-6 | Digikey | 450-1650-ND |  |  | https://www.digikey.com/product-detail/en/te-connectivity-alcoswitch-switches/1825910-6/450-1650-ND/1632536
5 | R1 ~ R6 | 6 | Resister | RES SMD 10K OHM 1% 1/8W 0805 (Not required if internal pull up’s are available) | 10k | R 0805 | Stackpole Electronics Inc. | RMCF0805FT10K0 | Digikey | RMCF0805FT10K0CT-ND |  |  | https://www.digikey.com/product-detail/en/stackpole-electronics-inc/RMCF0805FT10K0/RMCF0805FT10K0CT-ND/1942435
6 | C1 | 1 | Capacitor | CAP ALUM 470UF 20% 25V RADIAL | 470uF 25V | Radial, Through Hole, 2.5mm pitch | EPCOS (TDK) | B41851F5477M | Digikey | 495-5979-ND |  |  | https://www.digikey.com/product-detail/en/epcos-tdk/B41851F5477M/495-5979-ND/3543572
1. Recommended Distributor: Digi-Key, Mouser, Avnet Express, Farnell.
2. Catalog: Capacitor,Resister,Diode,Connector,Transistor,IC,PROTECTOR CATEGORY,OTHER
3. Required Fields: Item No, Reference Des, Qty, Catalog, Part_Value, Part Package
Optional Fields: Part_Description, Manufacturers Name, Manufacturers Part No, Distributors Name, Distributors Part No, Unit Cost, Price break to use, Notes/Remark

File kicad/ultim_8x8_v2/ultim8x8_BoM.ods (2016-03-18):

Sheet: BoM_TinyTiM
Id | Reference | Quantity | Value | Package
1 | C1,C3 | 2 | 100nF | c_0805
2 | C2,C4 | 2 | 47uF 20V | c_2917
3 | P1, P2, P5, P6 | 1 | Input1, Input2, Output1,Output2 | header_3pos_th_male
4 | P3, P4, P7 ~ P12 | 1 | 5V, GND, CI_A, DI_A, CO_H, DO_H | Screw, Stand off, M3 thread, 10mm tall
5 | U01 ~ U64 | 64 | APA102 | APA102

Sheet: BoM_PCB
Id | Value | Reference | Quantity | Package
1 | 100nF | C3,C1 | 2 | c_0805
2 | 47uF 20V | C2,C4 | 2 | c_2917
3 | Input1, Input2, Output1,Output2 | P1, P2, P5, P6 | 4 | header_3pos_th_male
4 | 5V, GND, CI_A, DI_A, CO_H, DO_H | P3, P4, P7 ~ P12 | 8 | Screw, Stand off, M3 thread, 10mm tall
5 | APA102 | U01 ~ U64 | 64 | APA102

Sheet: BoM_SCH
Reference | Value | Footprint
C1, C3 | 100nF | ultim8x8_libs:c_0805
C2, C4 | 47uF 20V | ultim8x8_libs:c_2917
P1, P2, P5, P6 | Input1, Input2, Output1, Output2 | ultim8x8_libs:header_3pos_th_male
P3, P4, P7 ~ P12 | 5V, GND, CI_A, DI_A, CO_H, DO_H | ultim8x8_libs:Screw
U01 ~ U64 | APA102 | ultim8x8_libs:APA102

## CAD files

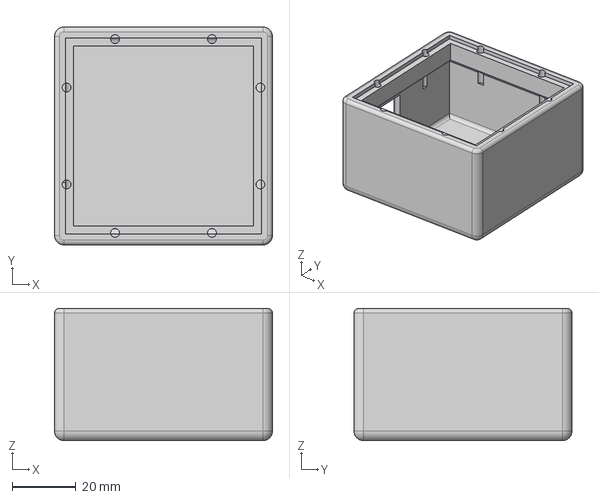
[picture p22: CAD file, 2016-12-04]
fabricate/featherboard_case/MainCase.stp
68.6 x 68.6 x 41.6 mm

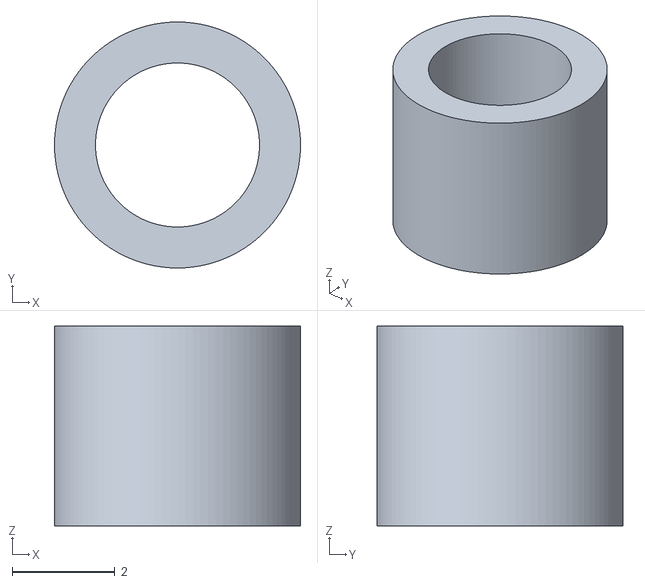
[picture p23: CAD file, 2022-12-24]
arduino/DesKlok/spacer.stl
4.80 x 4.80 x 3.90

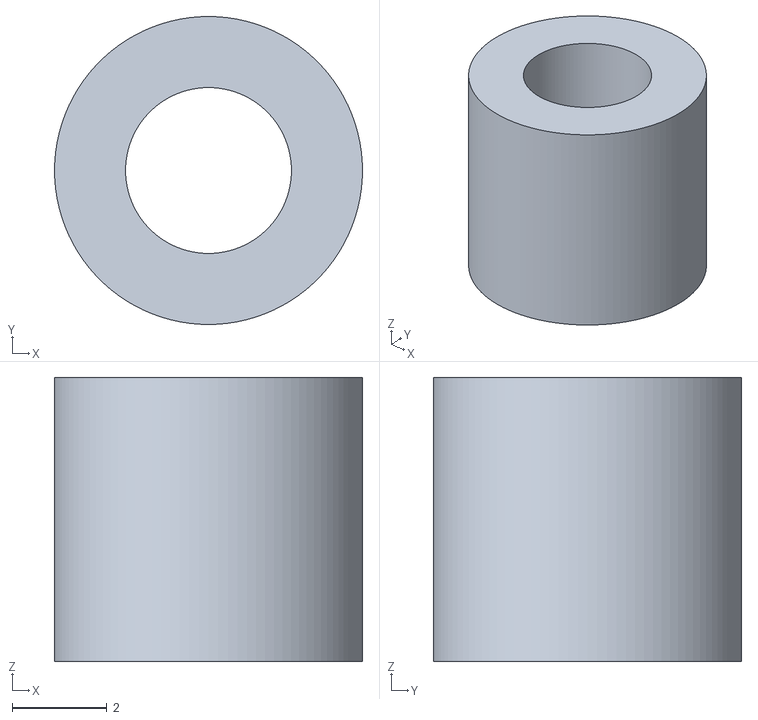
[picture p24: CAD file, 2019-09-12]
arduino/DullesNavKey/enclosure/standoffs.stl
6.50 x 6.50 x 6.00

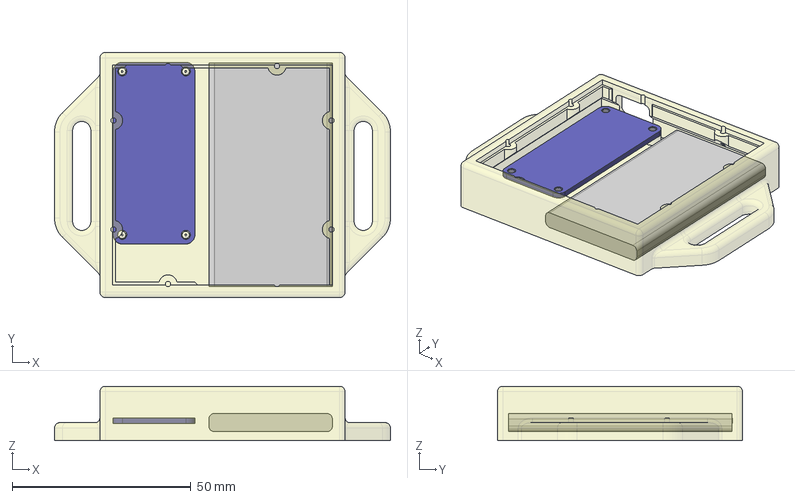
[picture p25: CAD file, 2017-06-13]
fabricate/buckle/ultim8x8_feather_buckle.fcstd
94.0 x 68.6 x 15.2 mm
LiPo_Fillet
feather_Fillet001
belt_Chamfer002

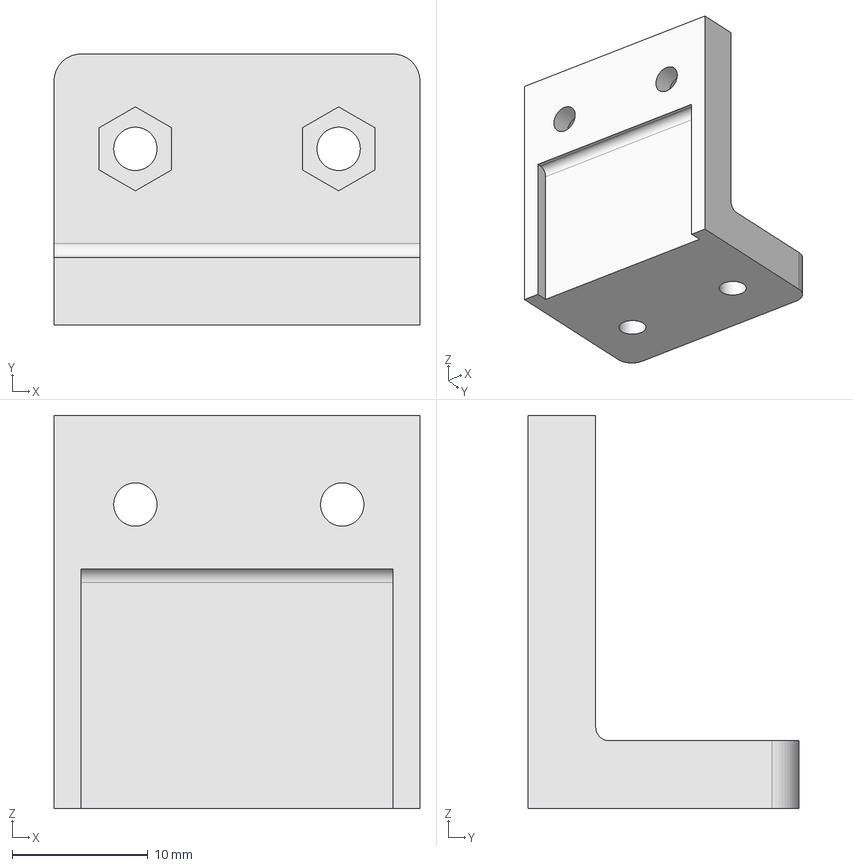
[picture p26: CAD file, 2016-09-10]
fabricate/SinglePanelStand/onepanelstand.fcstd
27.0 x 20.0 x 29.0 mm

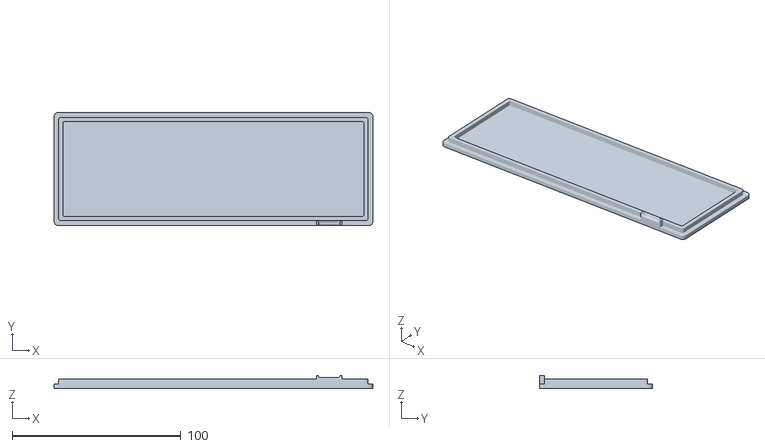
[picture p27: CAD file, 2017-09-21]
fabricate/STFU/STFU_bot.stl
189.0 x 67.1 x 7.49

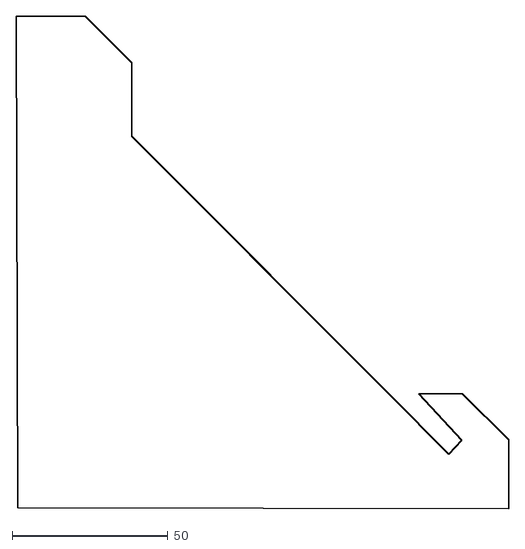
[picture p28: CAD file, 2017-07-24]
fabricate/SunRiseClock/side.dxf
158.0 x 158.0

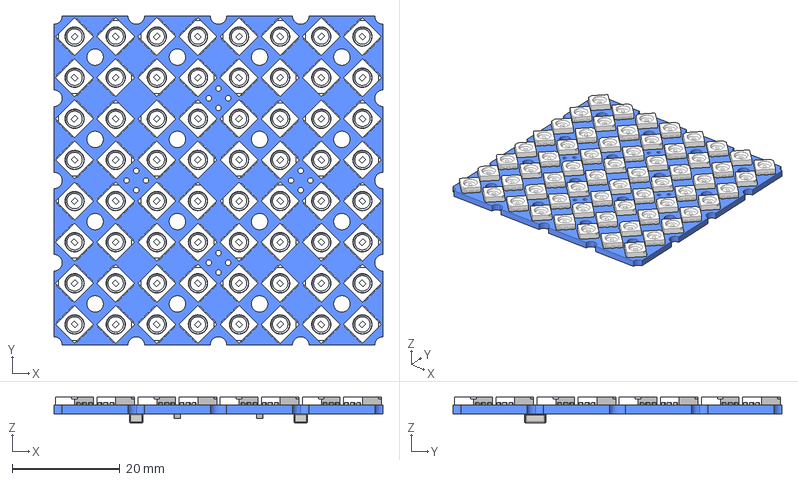
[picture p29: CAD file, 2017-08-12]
fabricate/ultim8x8.FCStd
61.0 x 61.0 x 4.80 mm
Pcb
User_Library-CapCeramic_Kemet_0805_2012_
User_Library-CapCeramic_Kemet_0805_2012_001
cap_1210_3225M_
cap_1210_3225M_001

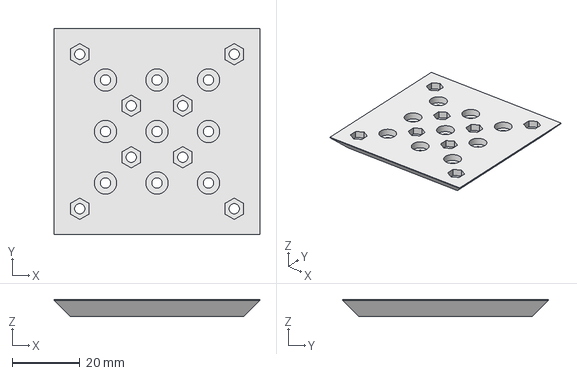
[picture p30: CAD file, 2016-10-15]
fabricate/ultim8x_cube01/ultim8x8_cube_face_02.fcstd
61.0 x 61.0 x 5.08 mm

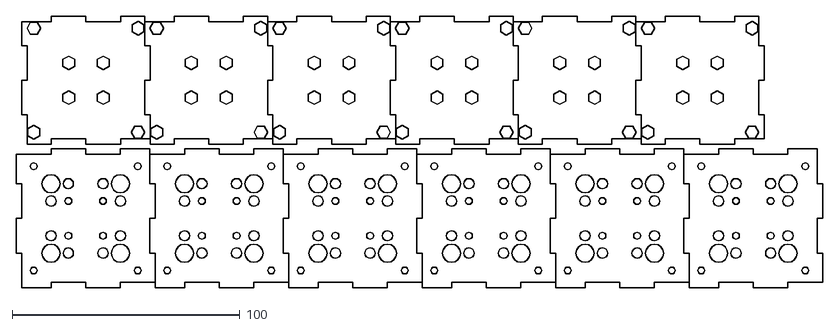
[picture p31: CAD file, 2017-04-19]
fabricate/ultim8x_cube02/cube02_laser_2mm35-2.dxf
354.0 x 119.3

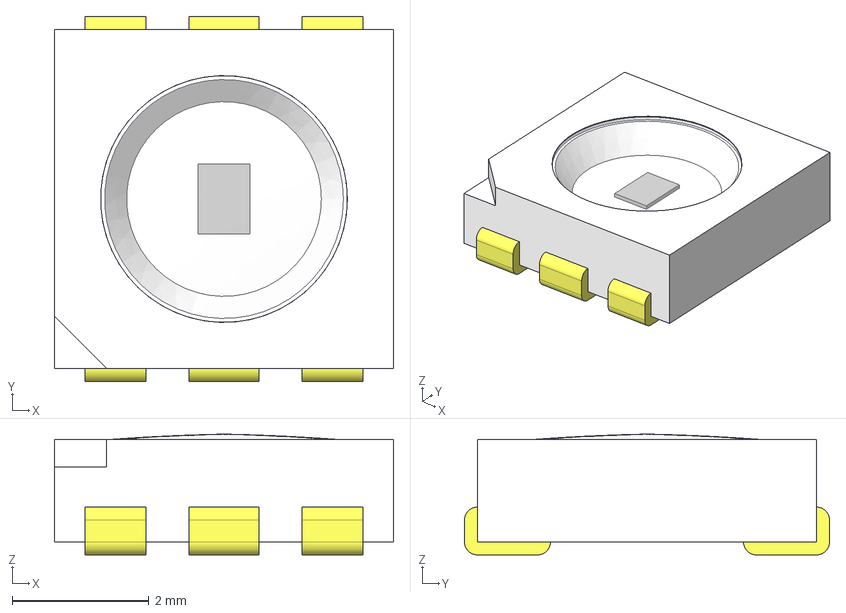
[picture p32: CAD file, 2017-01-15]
kicad/ultim_8x8_v2/ultim8x8_3D_modules/LED_SMS_APA102.fcstd
4.95 x 5.33 x 1.77 mm

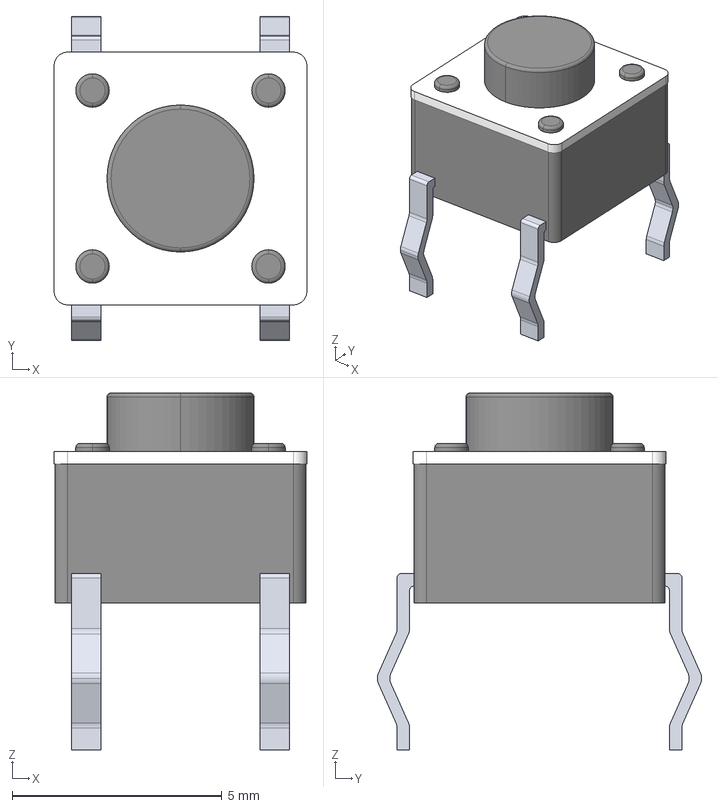
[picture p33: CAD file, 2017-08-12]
kicad/ultim_bus_v5/ultim_bus_3dmodules/TactileSwitch_6x6x5mm.step
6.03 x 7.74 x 8.52 mm

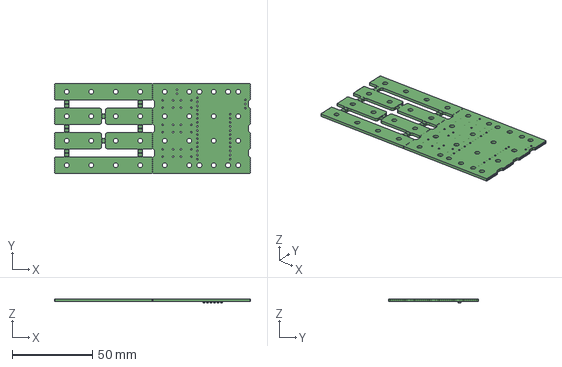
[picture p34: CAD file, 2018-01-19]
kicad/ultim_bus_v5/ultim_bus_snapped.stp
121.9 x 55.9 x 2.43 mm

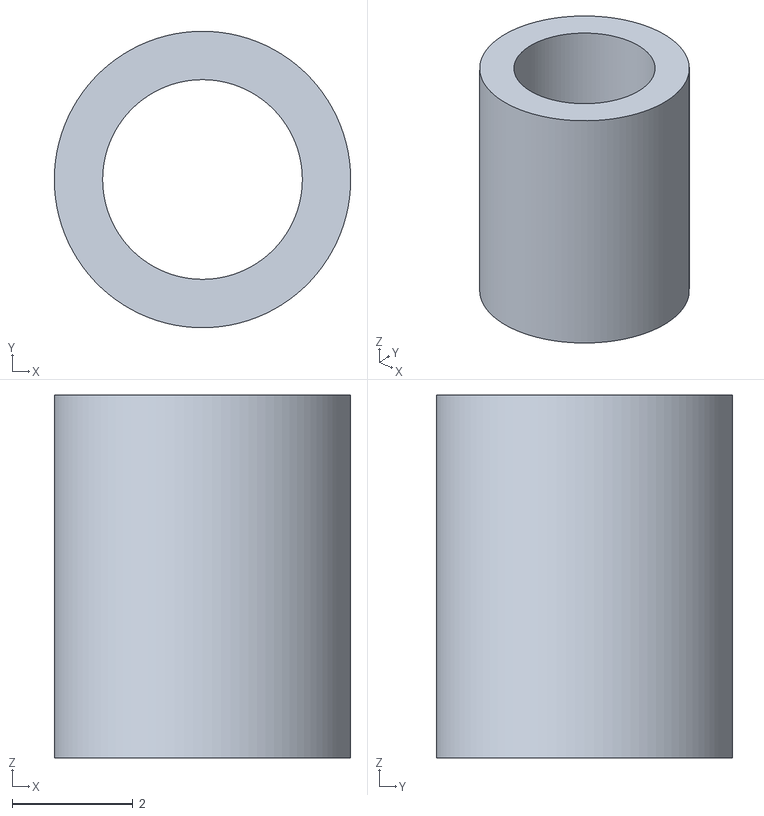
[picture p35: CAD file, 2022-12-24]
arduino/DesKlok/m3_spacer_6.0mm.stl
4.90 x 4.90 x 6.00

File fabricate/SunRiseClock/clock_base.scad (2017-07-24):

H =6;
inch = 25.4;
pixel = 1/3.5433;
L = 2.4*inch;
Screw_r = 1.3;
screw_r = 1.9/2;

module side(){
  difference(){
    //linear_extrude(height=H)scale(.386)import("side.dxf");
    linear_extrude(height=H)scale(.51)import("side.dxf");

    translate([ .2*inch, 15, H/2])rotate(a=90, v=[1, 0, 0])cylinder(r=screw_r, h=20, $fn=15);
    translate([ .8*inch, 15, H/2])rotate(a=90, v=[1, 0, 0])cylinder(r=Screw_r, h=20, $fn=15);
    translate([1.4*inch, 15, H/2])rotate(a=90, v=[1, 0, 0])cylinder(r=Screw_r, h=20, $fn=15);
    translate([2.0*inch, 15, H/2])rotate(a=90, v=[1, 0, 0])cylinder(r=Screw_r, h=20, $fn=15);
    rotate(a=90, v=[0, 0, 1])
      union(){
      translate([ .2*inch, 20-15, H/2])rotate(a=90, v=[1, 0, 0])cylinder(r=screw_r, h=20, $fn=15);
      translate([ .8*inch, 20-15, H/2])rotate(a=90, v=[1, 0, 0])cylinder(r=Screw_r, h=20, $fn=15);
      translate([1.4*inch, 20-15, H/2])rotate(a=90, v=[1, 0, 0])cylinder(r=Screw_r, h=20, $fn=15);
      translate([2.0*inch, 20-15, H/2])rotate(a=90, v=[1, 0, 0])cylinder(r=Screw_r, h=20, $fn=15);
    }
  }
  //translate([-L, 0, 0])cube([L, L, H]);
}
side();

//translate([0, -80, 0])cube([80, 80, H/2]);

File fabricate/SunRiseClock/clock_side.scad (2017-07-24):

W = 85;

T = 5;
screw_r = 1.9/2;

difference(){
  cube([W, W, T]);
  rotate(a=45, v=[0, 0, 1])translate([-W, 0, -T])cube([3*W, 3*W, 3*T]);
  translate([W - 10, 80, T/2])rotate(a=90, v=[1, 0, 0])cylinder(r=screw_r, h=100, $fn=20);
  translate([W - 55, 80, T/2])rotate(a=90, v=[1, 0, 0])cylinder(r=screw_r, h=100, $fn=20);
  translate([0, 10, T/2])rotate(a=90, v=[0, 1, 0])cylinder(r=screw_r, h=100, $fn=20);
  translate([0, 55, T/2])rotate(a=90, v=[0, 1, 0])cylinder(r=screw_r, h=100, $fn=20);
}

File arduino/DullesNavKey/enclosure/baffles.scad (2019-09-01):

inch=25.4;
//cube/led width
cw = 7;
led_h = 1.4;
//diagonal separation
//ds = sqrt(2*(cw*cw));
ds = .3*inch;
// ds = 7.7;
nx = 24;
ny = 24;

L = nx * ds;
W = ny * ds;

//baffle height
bh = 3;
bt = .82;

w = .18 * inch;
h = led_h;

module interlock(){
  translate([(1.5) * ds + bt, (3.5) * ds - bt/2, 0])rotate(a=45, v=[0, 0, 1])translate([-w/2, -w/2, 0]) cube([w, w, h]);
  translate([(5.5) * ds + bt, (3.5) * ds - bt/2, 0])rotate(a=45, v=[0, 0, 1])translate([-w/2, -w/2, 0]) cube([w, w, h]);
  translate([(3.5) * ds + bt, (1.5) * ds - bt/2, 0])rotate(a=45, v=[0, 0, 1])translate([-w/2, -w/2, 0]) cube([w, w, h]);
  translate([(3.5) * ds + bt, (5.5) * ds - bt/2, 0])rotate(a=45, v=[0, 0, 1])translate([-w/2, -w/2, 0]) cube([w, w, h]);
}
module grid(nx, ny){
  for(j = [1:1:ny-1]){
    yl = j * ds;
    translate([-cw/2, -ds/2 + yl-bt, led_h])cube([nx * ds, bt, bh]);
  } 
  for(i = [0:1:nx]){
    xl = i * ds;
    translate([-cw/2 + xl, -ds/2 - bt, led_h])cube([bt, ny*ds + bt, bh]);
  }

  for(i = [0:8:ny-1]){
    for(j = [0:8:nx-1]){
      translate([j * ds, i * ds, 0])interlock();
    }
  }
}

//rotate(a=180, v=[0, 1, 0])grid(nx, ny);
rotate(a=180, v=[0, 1, 0])
intersection(){
  grid(nx, 8);
  color("red")translate([-ds, -ds/2+bt/2, 0])cube([(nx  + 2)* ds, 8 * ds - 2 * bt, 10]);
}

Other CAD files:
arduino/DullesNavKey/enclosure/mouting_guide.stl
fabricate/buckle/ultim8x8_feather_buckle_v3.stl
fabricate/SinglePanelStand/singlepanelstand.stl
arduino/DullesNavKey/enclosure/standoffs.scad
arduino/DesKlok/ClockIOT.stl
arduino/DullesNavKey/enclosure/hanger.FCStd
arduino/DullesNavKey/enclosure/hanger.dxf
arduino/DullesNavKey/enclosure/hanger.stl
arduino/DullesNavKey/enclosure/hanger_guide.FCStd
fabricate/STFU/STFU_acrylic.dxf
fabricate/STFU/STFU_acrylic.stl
fabricate/STFU/STFU_top.stl
fabricate/STFU/u_bus.fcstd
fabricate/buckle/ultim8x8_feather_buckle_v1.stl
fabricate/buckle/ultim8x8_feather_buckle_v2.stl
fabricate/featherboard_case/MainCase.f3d
fabricate/featherboard_case/MainCase.stl
fabricate/old_archive/power_stud.fcstd
fabricate/old_archive/power_stud.step
fabricate/old_archive/ultim8x8.FCStd
fabricate/ultim8x_cube01/ultim8x8_cube_face_01.fcstd
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

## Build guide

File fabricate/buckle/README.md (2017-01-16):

# buckle

ultim8x8 LED panel belt Buckle "Wearable Tech". Requires this 3D printed case, one ultim8x8 Module, 
Adafruit Feather M0, 1200mAh LiPo Battery, Miniature slide switch.

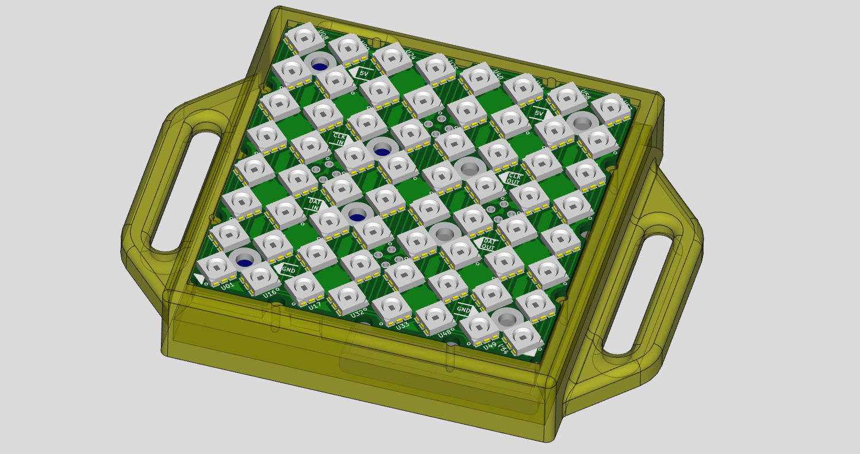
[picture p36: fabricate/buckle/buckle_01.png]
buckle01


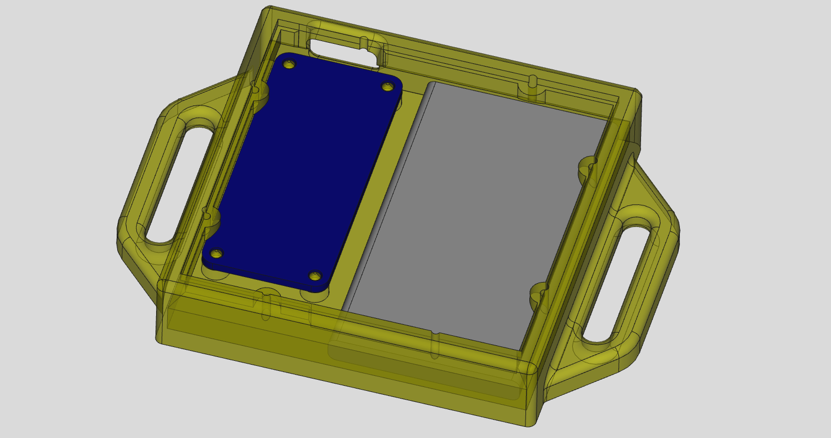
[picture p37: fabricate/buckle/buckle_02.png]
buckle02


License
-------
[CERN Open Hardware Licence v1.2 ]

[CERN Open Hardware Licence v1.2 ]:http://www.ohwr.org/attachments/2388/cern_ohl_v_1_2.txt

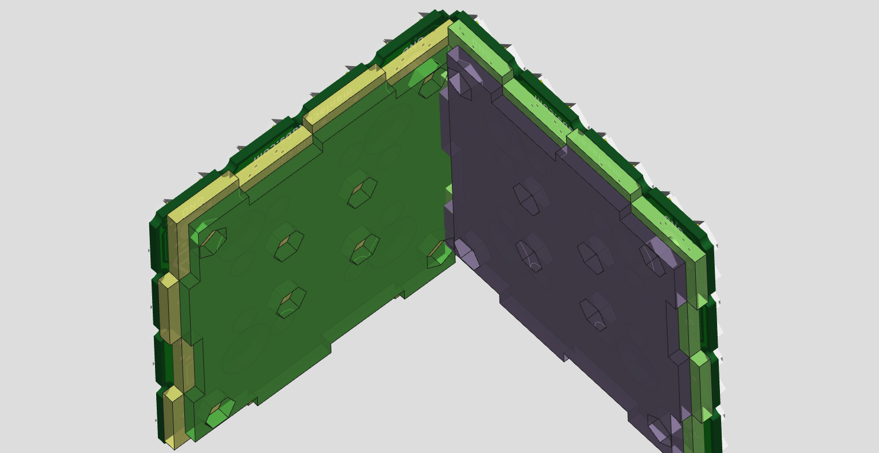
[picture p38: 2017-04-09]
fabricate/ultim8x_cube02/images/cube02_02.png

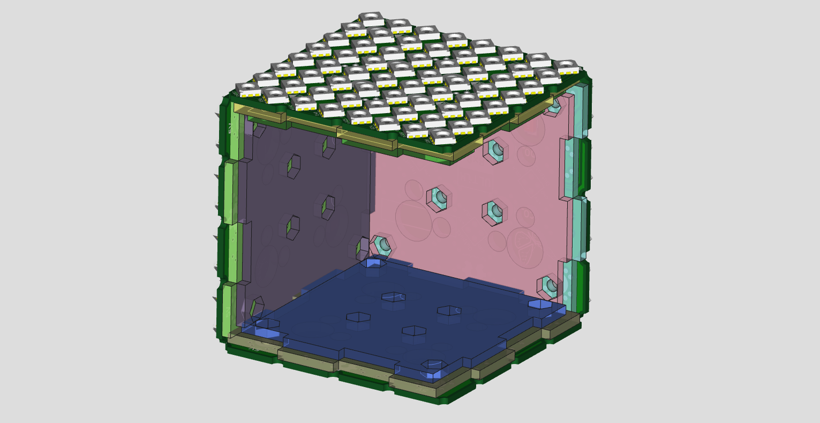
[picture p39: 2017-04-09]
fabricate/ultim8x_cube02/images/cube02_04.png

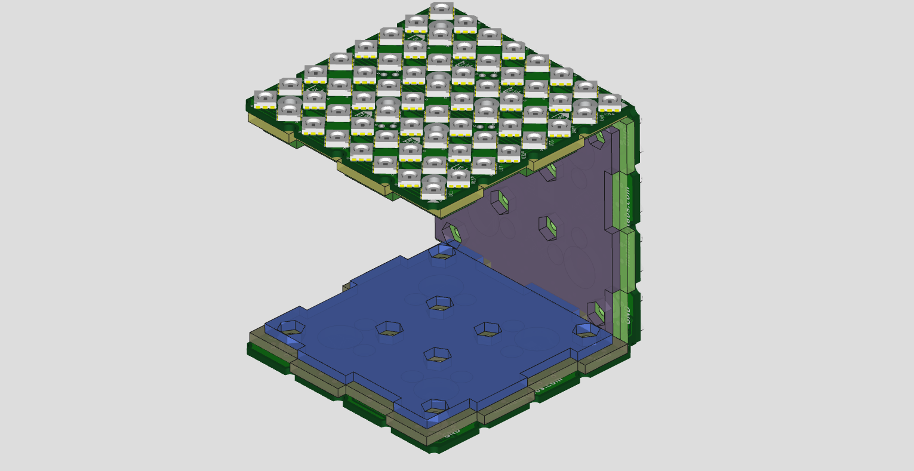
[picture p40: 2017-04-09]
fabricate/ultim8x_cube02/images/cube02_03.png

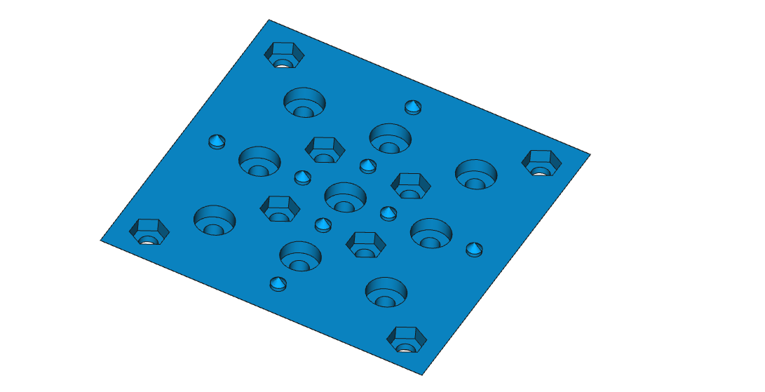
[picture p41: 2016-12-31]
fabricate/ultim8x_cube01/images/cube02.png

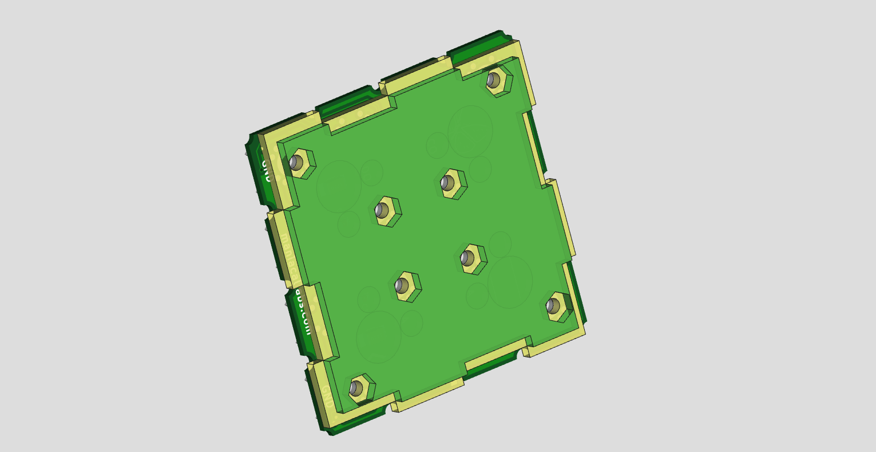
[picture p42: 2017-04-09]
fabricate/ultim8x_cube02/images/cube02_01.png

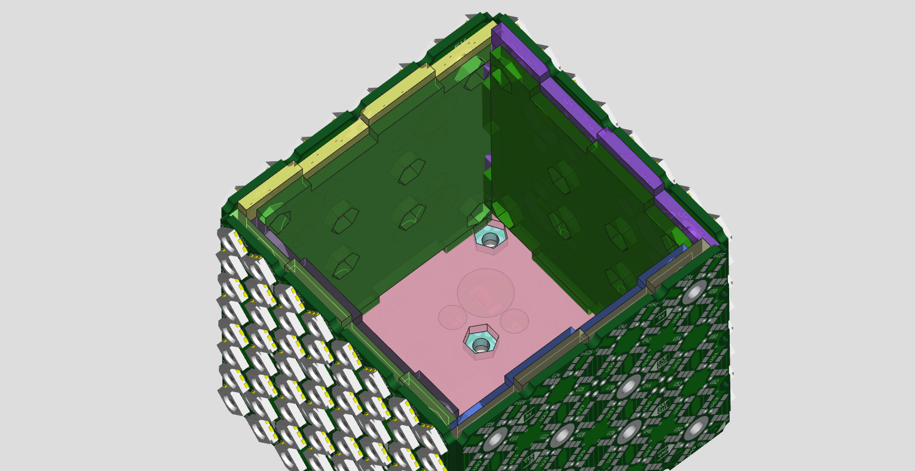
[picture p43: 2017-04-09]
fabricate/ultim8x_cube02/images/cube02_06.png

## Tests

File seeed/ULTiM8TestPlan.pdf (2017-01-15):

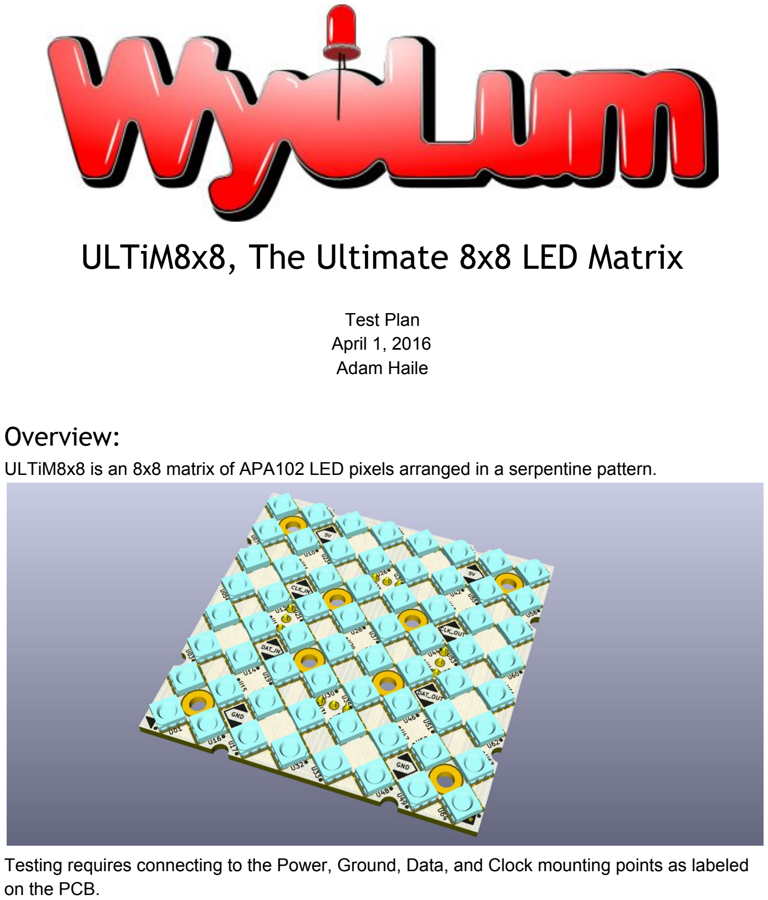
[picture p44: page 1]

# ULTiM8x8, The Ultimate 8x8 LED Matrix

Test Plan
April 1, 2016
Adam Haile

## Overview:

ULTiM8x8 is an 8x8 matrix of APA102 LED pixels arranged in a serpentine pattern.

Testing requires connecting to the Power, Ground, Data, and Clock mounting points as labeled on the PCB.

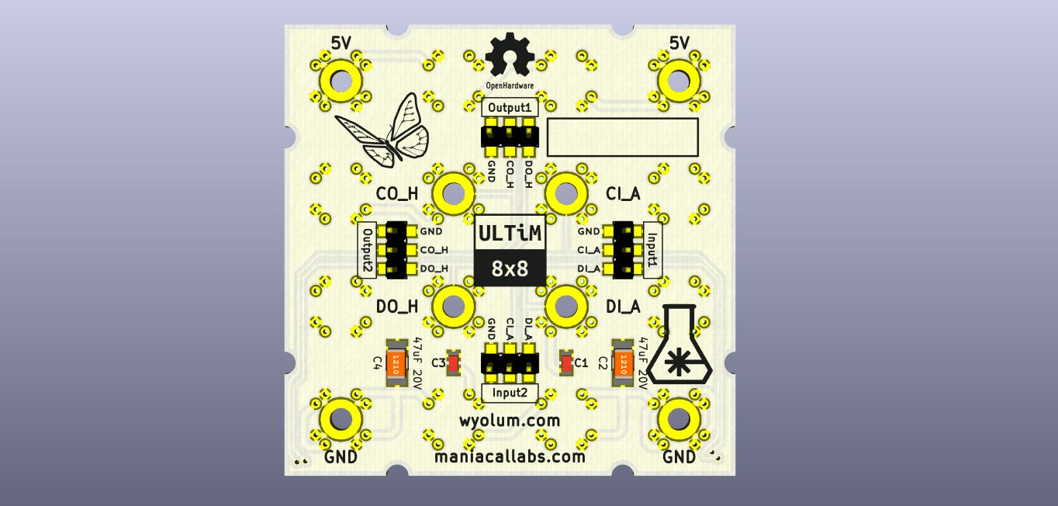
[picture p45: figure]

Power Input connections are via 3mm mounting holes labelled [5V]and [GND].
- CI_A= Clock Input (from controller or previous ULTiM8x8)
- DI_A= Data Input (from controller or previous ULTiM8x8)
- CO_H= Clock Output (to next ULTiM8x8)
- DO_H= Data Output (to next ULTiM8x8)
Clock and Data Inputs can be applied either to [INPUT1] or [INPUT2], or to the 3mm mounting holes marked as CI_Aand DI_A.

In order to avoid the LED lost issue, please consider to add reflow into the production procedure and improve the packaging.

## Functionality to be tested

Each LED should be capable of displaying RED/GREEN/BLUE and WHITE.

## Test Hardware Required

1. Arduino UNO or similar
2. Power hookup wires (18AWG+). Alligator clips may be used to connect to the terminals.
3. 3 malefemale jumpers (data, clock, ground from arduino)
4. 5V@5A power supply

## Test Setup

1. Ensure proper ESD precautions are observed: antistatic mat, antistatic wrist strap, etc.
2. Program the Arduino compatible with test code. (http://maniacallabs.com/misc/ULTiM8.zip) (http://maniacallabs.com/misc/ULTiM8.zip) No extra libraries are required, everything is included in the 3 source files within the Zip.
3. Connect the Arduino compatible to ULTiM8x8 under test.
a. Arduino D4 ULTiM8x8 Data In
b. Arduino D5 ULTiM8x8 Clock In
c. Arduino GND ULTiM8x8 GND
4. Connect power supply, but do not apply power yet
a. Power +5V > ULTiM8x8 +5V
b. Power GND > ULTiM8x8 GND

## Test Sequence

1. Visual inspection for any defects, prior to hookup: verify all LEDS are aligned correctly. Verify all other discrete components are aligned correctly on their pads and that there is no evidence of any solder defects.
2. Hookup as specified above
3. Vibration testing: lightly strike the board, edge on, against the table. Make sure no LEDs fall off.
4. Run hand over the LED array to see if any LEDs come loose.
5. Power the unit
6. See that ALL LEDs display ALL colors. Red > Green > Blue > White > Off > Repeat

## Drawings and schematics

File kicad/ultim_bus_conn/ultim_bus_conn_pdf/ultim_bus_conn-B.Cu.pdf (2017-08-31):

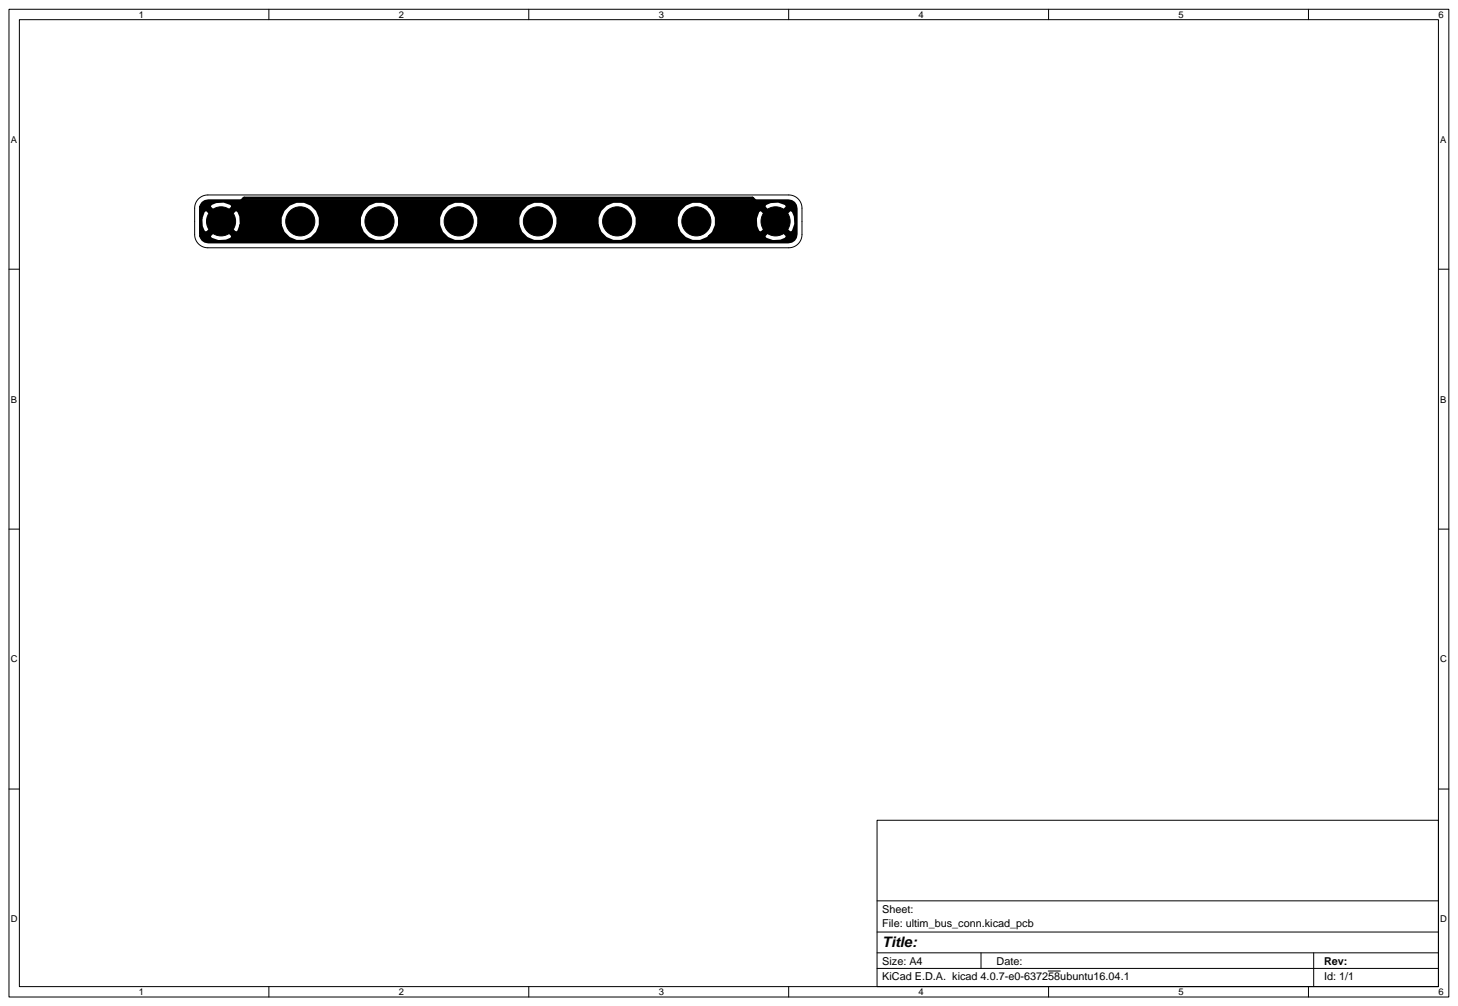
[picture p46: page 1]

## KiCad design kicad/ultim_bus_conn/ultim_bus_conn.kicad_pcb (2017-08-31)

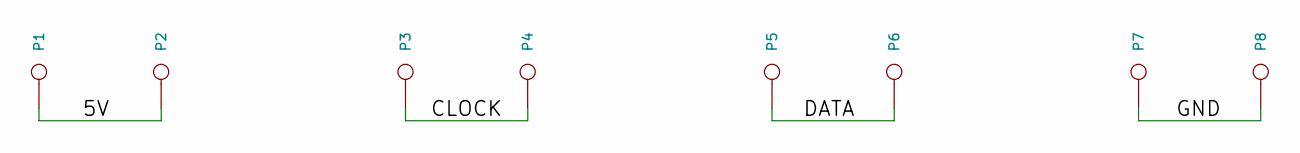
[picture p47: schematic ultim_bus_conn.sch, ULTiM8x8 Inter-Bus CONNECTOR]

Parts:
P1, P2, P3, P4, P5, P6, P7, P8: CONN_1; Screw

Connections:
/5V: P1.1, P2.1
/CLOCK: P3.1, P4.1
/DATA: P5.1, P6.1
/GND: P7.1, P8.1

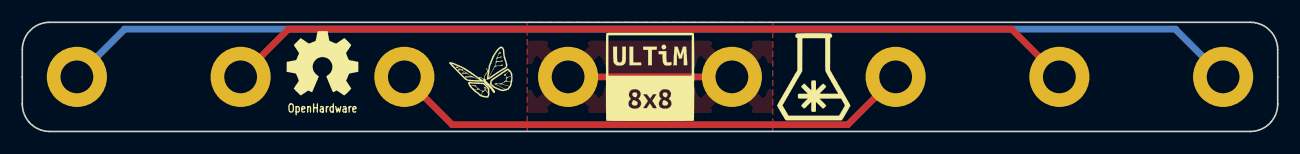
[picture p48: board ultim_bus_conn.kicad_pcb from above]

Board: 2 copper layers, 116.8 x 10.2 mm, 10 parts (1 on the bottom side), 4 nets.

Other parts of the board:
L101, L101#2: OSHW; OSHW_6mm

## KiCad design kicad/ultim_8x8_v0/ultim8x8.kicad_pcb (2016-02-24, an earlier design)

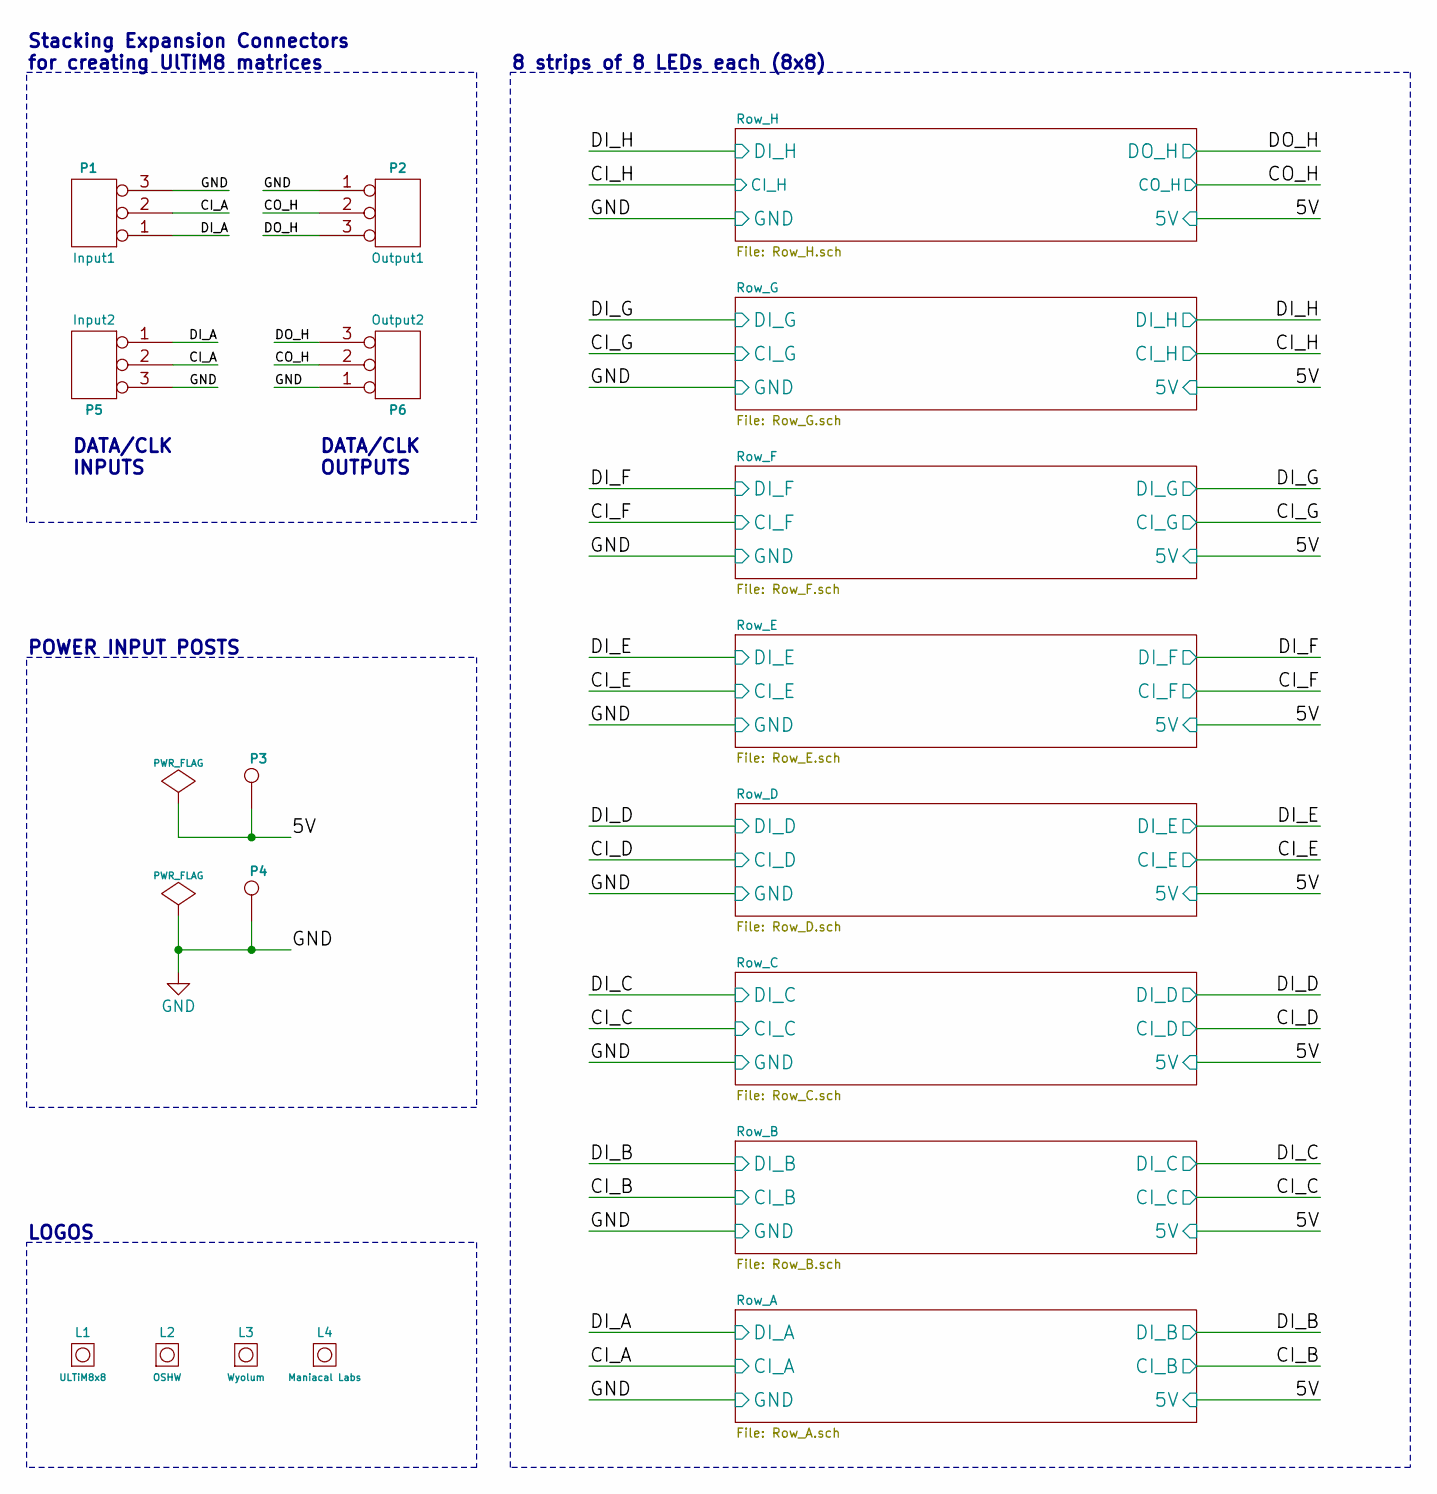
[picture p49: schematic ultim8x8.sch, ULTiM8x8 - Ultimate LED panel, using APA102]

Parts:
L1: ULTiM8x8; logo_ultim8x8
L2: OSHW; OSHW_6mm
L3: Wyolum; logo_wyo_butterfly
L4: Maniacal Labs; logo_MLlabs
P1: Input1; header_3pos_smd_male
P2: Output1; header_3pos_smd_male
P3: 5V; PowerIn_stud
P4: GND; PowerIn_stud
P5: Input2; header_3pos_smd_male
P6: Output2; header_3pos_smd_male

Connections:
/Row_A/5V: P3.1; also elsewhere on the board
/Row_A/CI_A: P1.2, P5.2; also elsewhere on the board
/Row_A/DI_A: P1.1, P5.1; also elsewhere on the board
/Row_H/CO_H: P2.2, P6.2; also elsewhere on the board
/Row_H/DO_H: P2.3, P6.3; also elsewhere on the board
GND: P1.3, P2.1, P4.1, P5.3, P6.1; also elsewhere on the board

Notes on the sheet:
Stacking Expansion Connectors for creating UlTiM8 matrices
LOGOS
POWER INPUT POSTS
DATA/CLK OUTPUTS
DATA/CLK INPUTS
8 strips of 8 LEDs each (8x8)

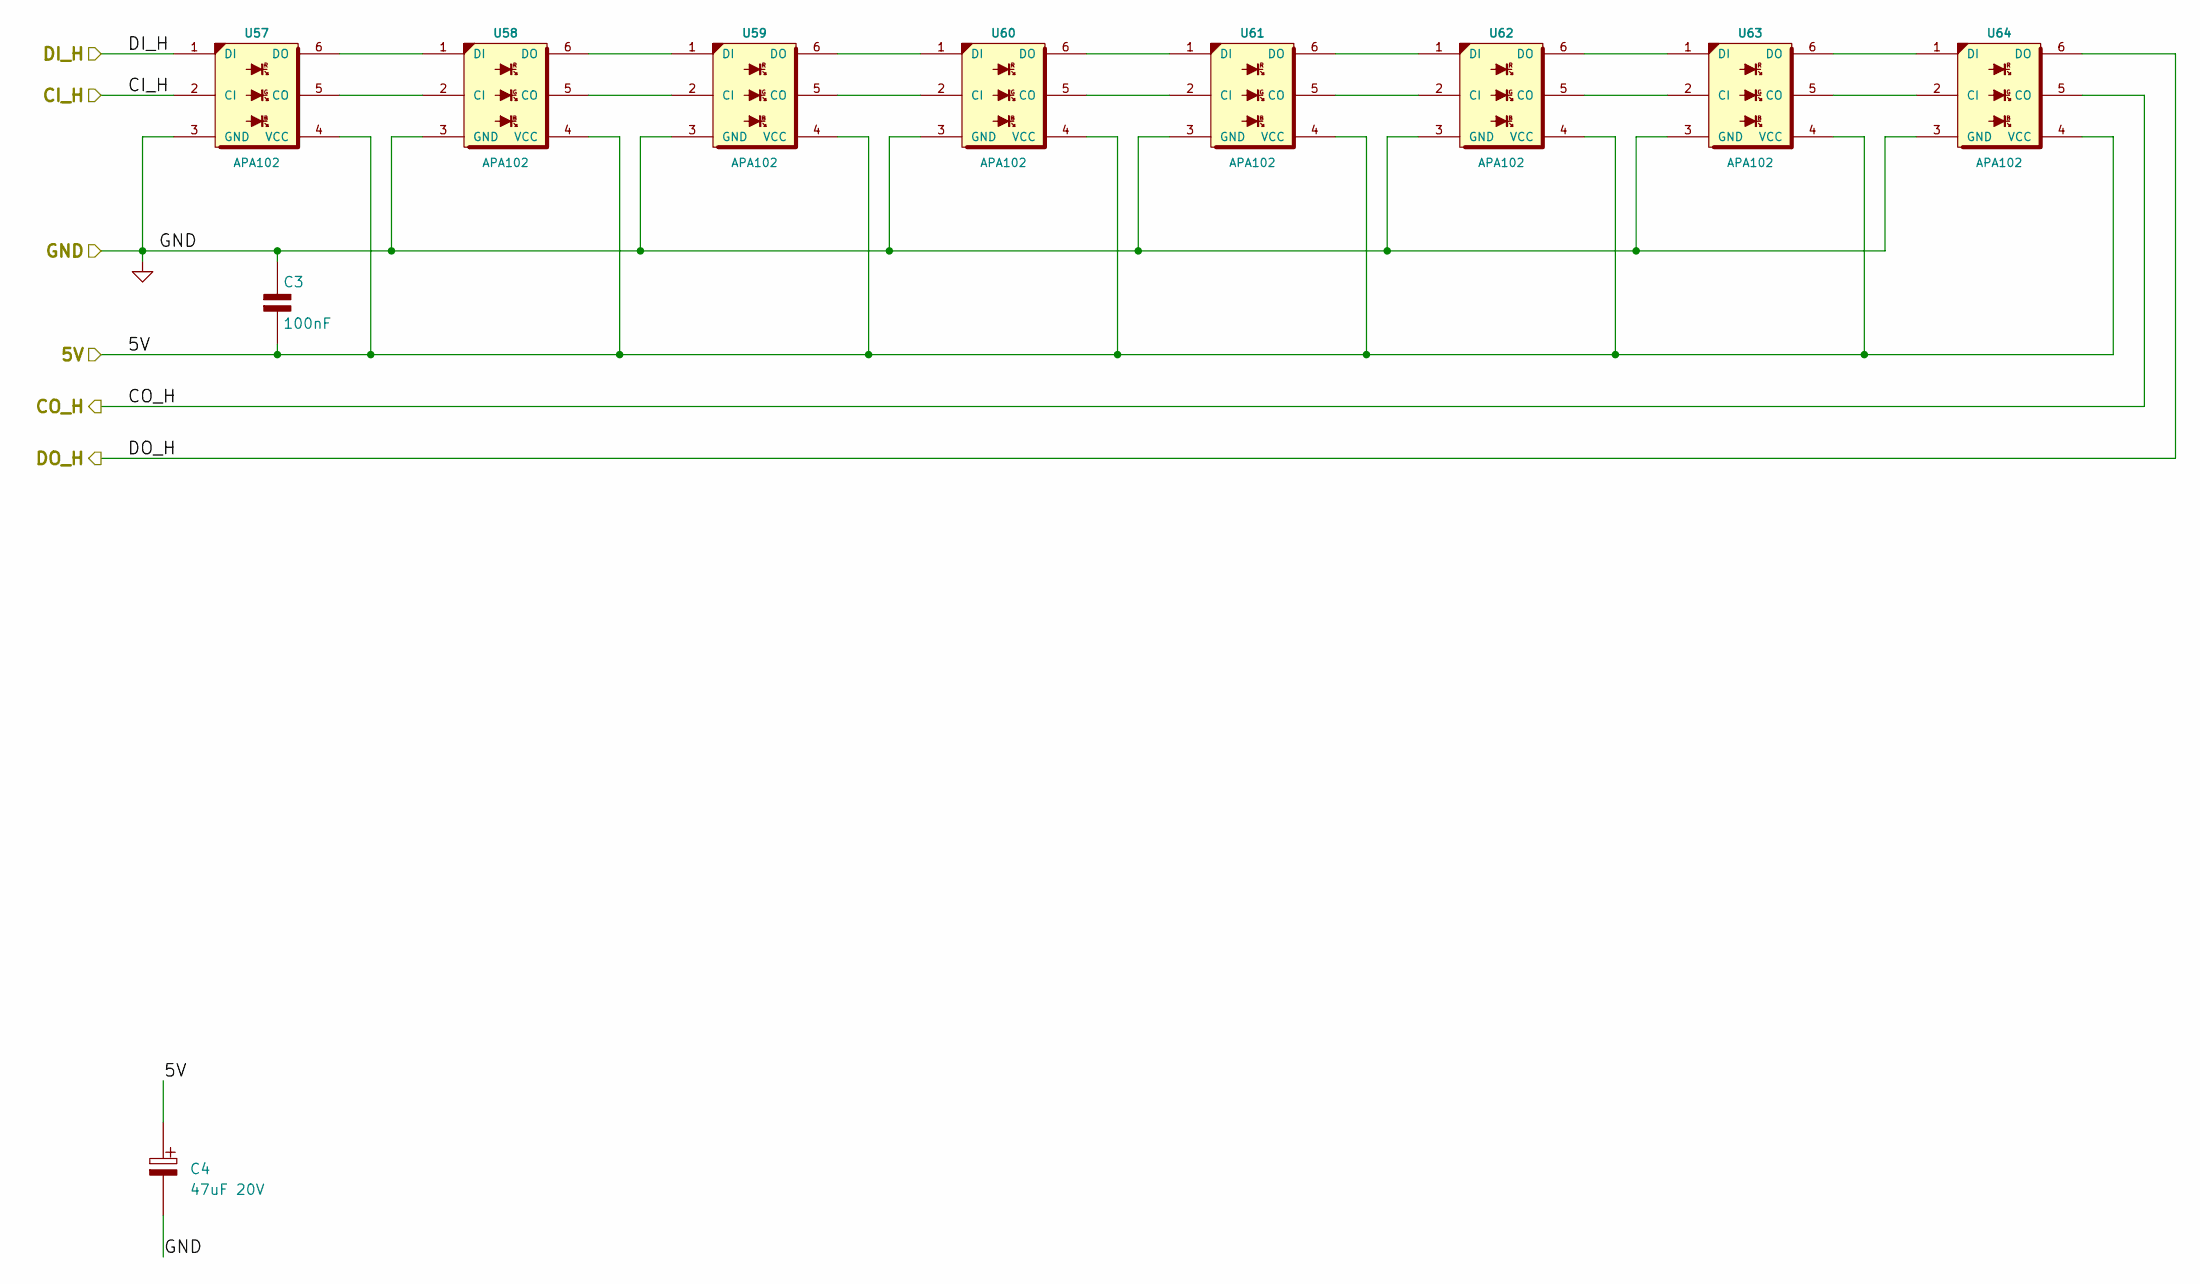
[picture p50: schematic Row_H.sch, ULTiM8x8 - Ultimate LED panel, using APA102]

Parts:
C3: 100nF; c_0805
C4: 47uF 20V; c_2917
U57, U58, U61, U62, U63, U64: APA102
U59: APA102; APA102_U59
U60: APA102; APA102_U60

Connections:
/Row_A/5V: C3.2, C4.1 (+), U57.4 (VCC), U58.4 (VCC), U59.4 (VCC), U60.4 (VCC), U61.4 (VCC), U62.4 (VCC), U63.4 (VCC), U64.4 (VCC); also elsewhere on the board
/Row_G/CI_H: U57.2 (CI); also elsewhere on the board
/Row_G/DI_H: U57.1 (DI); also elsewhere on the board
/Row_H/CO_H: U64.5 (CO); also elsewhere on the board
/Row_H/DO_H: U64.6 (DO); also elsewhere on the board
GND: C3.1, C4.2 (-), U57.3 (GND), U58.3 (GND), U59.3 (GND), U60.3 (GND), U61.3 (GND), U62.3 (GND), U63.3 (GND), U64.3 (GND); also elsewhere on the board
unnamed: U57.5 (CO), U58.2 (CI)
unnamed: U57.6 (DO), U58.1 (DI)
unnamed: U58.5 (CO), U59.2 (CI)
unnamed: U58.6 (DO), U59.1 (DI)
unnamed: U59.5 (CO), U60.2 (CI)
unnamed: U59.6 (DO), U60.1 (DI)
unnamed: U60.5 (CO), U61.2 (CI)
unnamed: U60.6 (DO), U61.1 (DI)
unnamed: U61.5 (CO), U62.2 (CI)
unnamed: U61.6 (DO), U62.1 (DI)
unnamed: U62.5 (CO), U63.2 (CI)
unnamed: U62.6 (DO), U63.1 (DI)
unnamed: U63.5 (CO), U64.2 (CI)
unnamed: U63.6 (DO), U64.1 (DI)

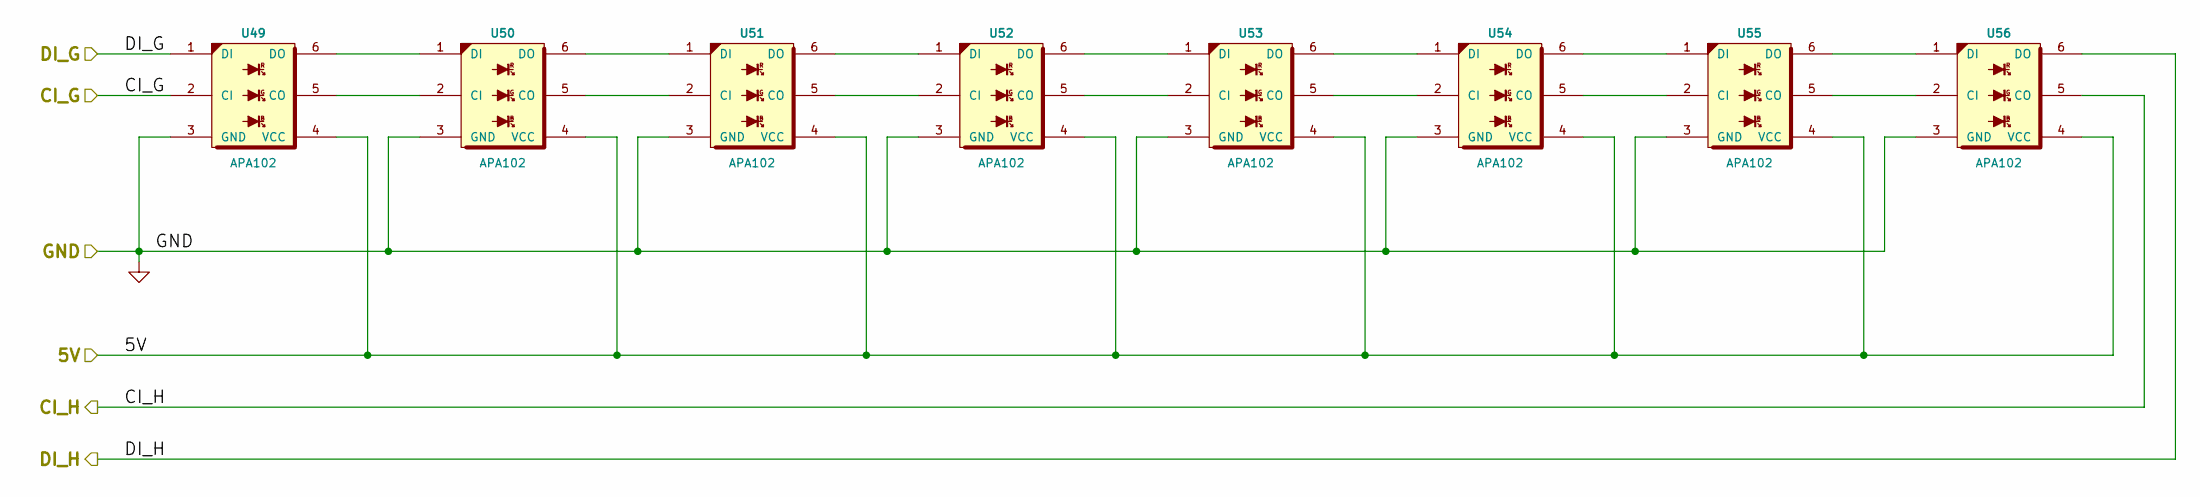
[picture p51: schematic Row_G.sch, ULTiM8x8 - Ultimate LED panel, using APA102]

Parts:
U49, U50, U51, U52, U55, U56: APA102
U53: APA102; APA102_U53
U54: APA102; APA102_U54

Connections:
/Row_A/5V: U49.4 (VCC), U50.4 (VCC), U51.4 (VCC), U52.4 (VCC), U53.4 (VCC), U54.4 (VCC), U55.4 (VCC), U56.4 (VCC); also elsewhere on the board
/Row_F/CI_G: U49.2 (CI); also elsewhere on the board
/Row_F/DI_G: U49.1 (DI); also elsewhere on the board
/Row_G/CI_H: U56.5 (CO); also elsewhere on the board
/Row_G/DI_H: U56.6 (DO); also elsewhere on the board
GND: U49.3 (GND), U50.3 (GND), U51.3 (GND), U52.3 (GND), U53.3 (GND), U54.3 (GND), U55.3 (GND), U56.3 (GND); also elsewhere on the board
unnamed: U49.5 (CO), U50.2 (CI)
unnamed: U49.6 (DO), U50.1 (DI)
unnamed: U50.5 (CO), U51.2 (CI)
unnamed: U50.6 (DO), U51.1 (DI)
unnamed: U51.5 (CO), U52.2 (CI)
unnamed: U51.6 (DO), U52.1 (DI)
unnamed: U52.5 (CO), U53.2 (CI)
unnamed: U52.6 (DO), U53.1 (DI)
unnamed: U53.5 (CO), U54.2 (CI)
unnamed: U53.6 (DO), U54.1 (DI)
unnamed: U54.5 (CO), U55.2 (CI)
unnamed: U54.6 (DO), U55.1 (DI)
unnamed: U55.5 (CO), U56.2 (CI)
unnamed: U55.6 (DO), U56.1 (DI)

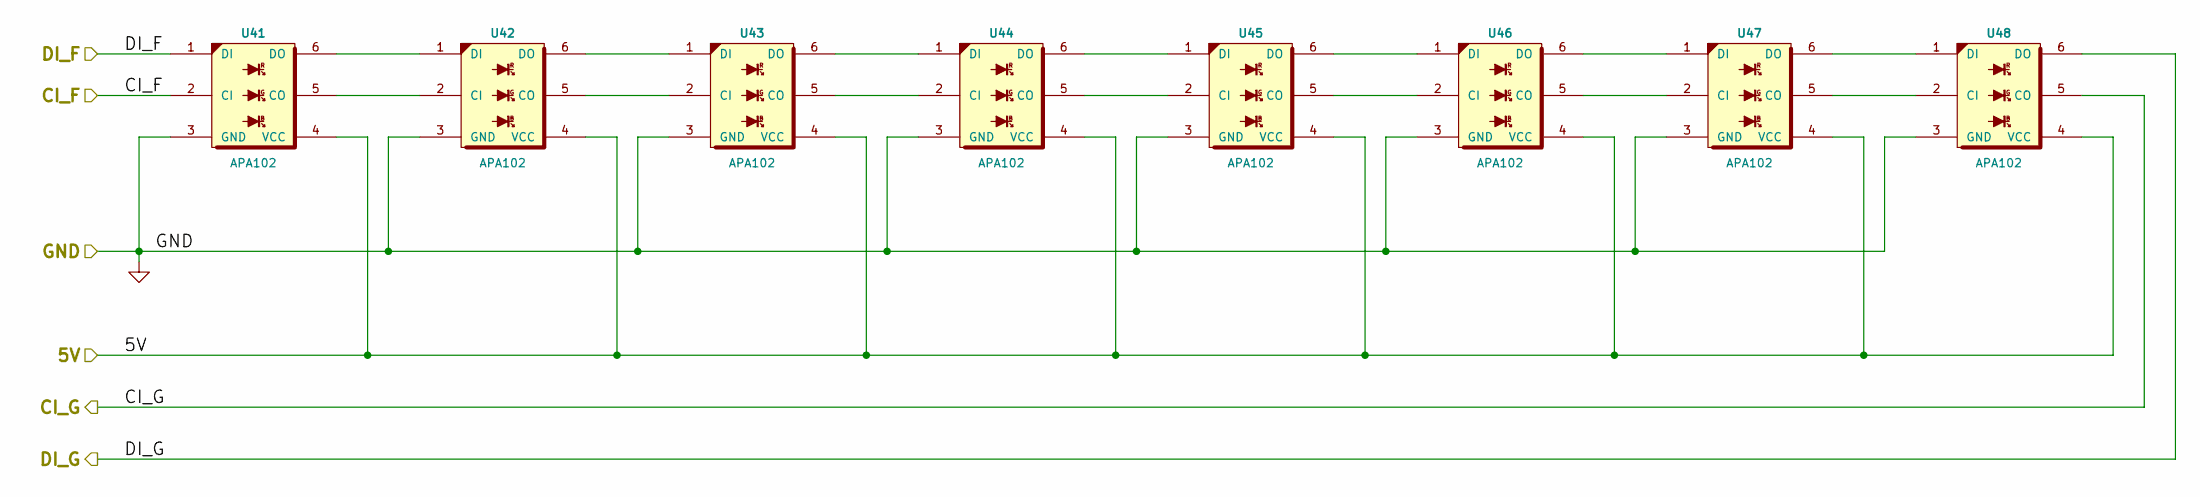
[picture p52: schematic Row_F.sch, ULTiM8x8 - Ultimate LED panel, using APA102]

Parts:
U41, U42, U44, U45, U46, U47, U48: APA102
U43: APA102; APA102_U43

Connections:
/Row_A/5V: U41.4 (VCC), U42.4 (VCC), U43.4 (VCC), U44.4 (VCC), U45.4 (VCC), U46.4 (VCC), U47.4 (VCC), U48.4 (VCC); also elsewhere on the board
/Row_E/CI_F: U41.2 (CI); also elsewhere on the board
/Row_E/DI_F: U41.1 (DI); also elsewhere on the board
/Row_F/CI_G: U48.5 (CO); also elsewhere on the board
/Row_F/DI_G: U48.6 (DO); also elsewhere on the board
GND: U41.3 (GND), U42.3 (GND), U43.3 (GND), U44.3 (GND), U45.3 (GND), U46.3 (GND), U47.3 (GND), U48.3 (GND); also elsewhere on the board
unnamed: U41.5 (CO), U42.2 (CI)
unnamed: U41.6 (DO), U42.1 (DI)
unnamed: U42.5 (CO), U43.2 (CI)
unnamed: U42.6 (DO), U43.1 (DI)
unnamed: U43.5 (CO), U44.2 (CI)
unnamed: U43.6 (DO), U44.1 (DI)
unnamed: U44.5 (CO), U45.2 (CI)
unnamed: U44.6 (DO), U45.1 (DI)
unnamed: U45.5 (CO), U46.2 (CI)
unnamed: U45.6 (DO), U46.1 (DI)
unnamed: U46.5 (CO), U47.2 (CI)
unnamed: U46.6 (DO), U47.1 (DI)
unnamed: U47.5 (CO), U48.2 (CI)
unnamed: U47.6 (DO), U48.1 (DI)

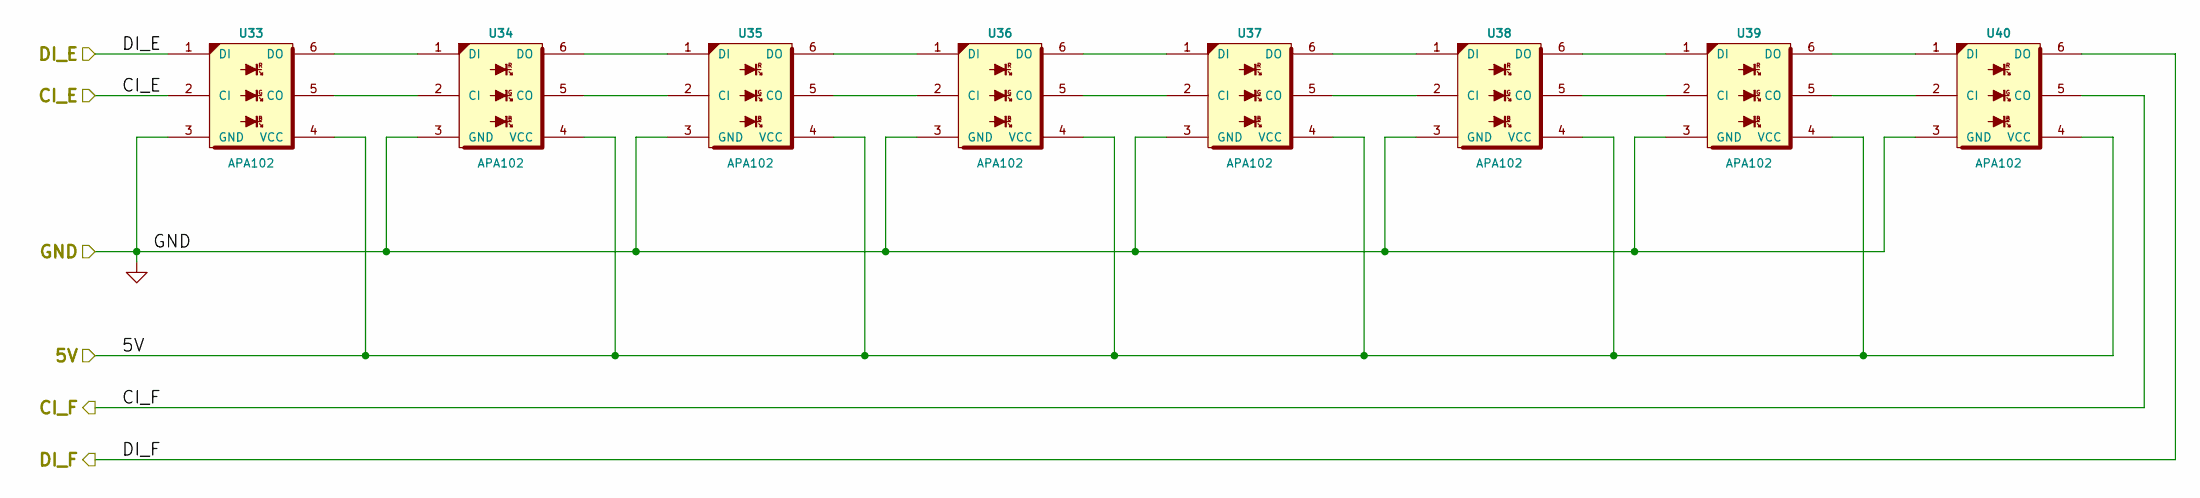
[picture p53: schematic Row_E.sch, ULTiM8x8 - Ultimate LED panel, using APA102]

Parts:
U33, U34, U35, U36, U37, U39, U40: APA102
U38: APA102; APA102_U38

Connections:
/Row_A/5V: U33.4 (VCC), U34.4 (VCC), U35.4 (VCC), U36.4 (VCC), U37.4 (VCC), U38.4 (VCC), U39.4 (VCC), U40.4 (VCC); also elsewhere on the board
/Row_D/CI_E: U33.2 (CI); also elsewhere on the board
/Row_D/DI_E: U33.1 (DI); also elsewhere on the board
/Row_E/CI_F: U40.5 (CO); also elsewhere on the board
/Row_E/DI_F: U40.6 (DO); also elsewhere on the board
GND: U33.3 (GND), U34.3 (GND), U35.3 (GND), U36.3 (GND), U37.3 (GND), U38.3 (GND), U39.3 (GND), U40.3 (GND); also elsewhere on the board
unnamed: U33.5 (CO), U34.2 (CI)
unnamed: U33.6 (DO), U34.1 (DI)
unnamed: U34.5 (CO), U35.2 (CI)
unnamed: U34.6 (DO), U35.1 (DI)
unnamed: U35.5 (CO), U36.2 (CI)
unnamed: U35.6 (DO), U36.1 (DI)
unnamed: U36.5 (CO), U37.2 (CI)
unnamed: U36.6 (DO), U37.1 (DI)
unnamed: U37.5 (CO), U38.2 (CI)
unnamed: U37.6 (DO), U38.1 (DI)
unnamed: U38.5 (CO), U39.2 (CI)
unnamed: U38.6 (DO), U39.1 (DI)
unnamed: U39.5 (CO), U40.2 (CI)
unnamed: U39.6 (DO), U40.1 (DI)

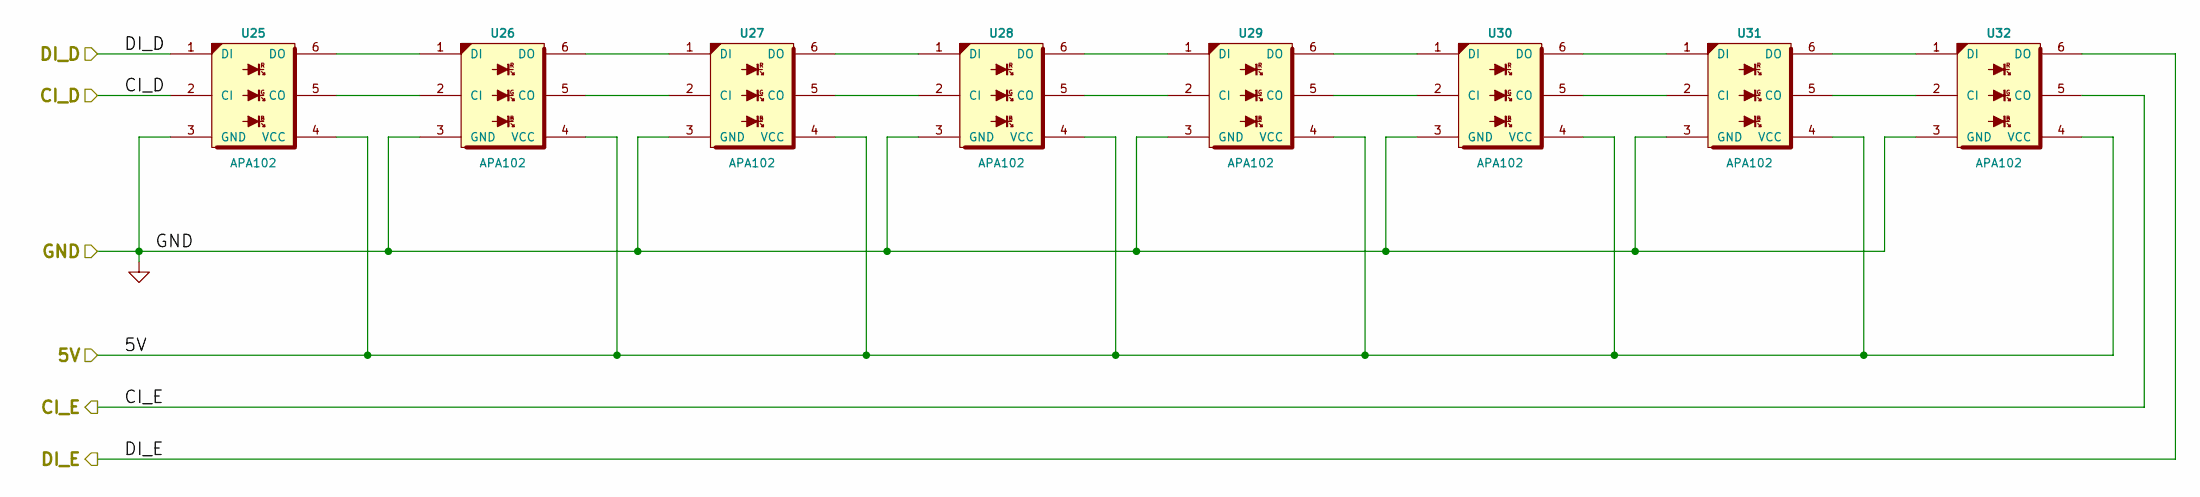
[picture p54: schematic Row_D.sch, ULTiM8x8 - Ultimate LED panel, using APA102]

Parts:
U25, U26, U27, U28, U29, U30, U31, U32: APA102

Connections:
/Row_A/5V: U25.4 (VCC), U26.4 (VCC), U27.4 (VCC), U28.4 (VCC), U29.4 (VCC), U30.4 (VCC), U31.4 (VCC), U32.4 (VCC); also elsewhere on the board
/Row_C/CI_D: U25.2 (CI); also elsewhere on the board
/Row_C/DI_D: U25.1 (DI); also elsewhere on the board
/Row_D/CI_E: U32.5 (CO); also elsewhere on the board
/Row_D/DI_E: U32.6 (DO); also elsewhere on the board
GND: U25.3 (GND), U26.3 (GND), U27.3 (GND), U28.3 (GND), U29.3 (GND), U30.3 (GND), U31.3 (GND), U32.3 (GND); also elsewhere on the board
unnamed: U25.5 (CO), U26.2 (CI)
unnamed: U25.6 (DO), U26.1 (DI)
unnamed: U26.5 (CO), U27.2 (CI)
unnamed: U26.6 (DO), U27.1 (DI)
unnamed: U27.5 (CO), U28.2 (CI)
unnamed: U27.6 (DO), U28.1 (DI)
unnamed: U28.5 (CO), U29.2 (CI)
unnamed: U28.6 (DO), U29.1 (DI)
unnamed: U29.5 (CO), U30.2 (CI)
unnamed: U29.6 (DO), U30.1 (DI)
unnamed: U30.5 (CO), U31.2 (CI)
unnamed: U30.6 (DO), U31.1 (DI)
unnamed: U31.5 (CO), U32.2 (CI)
unnamed: U31.6 (DO), U32.1 (DI)

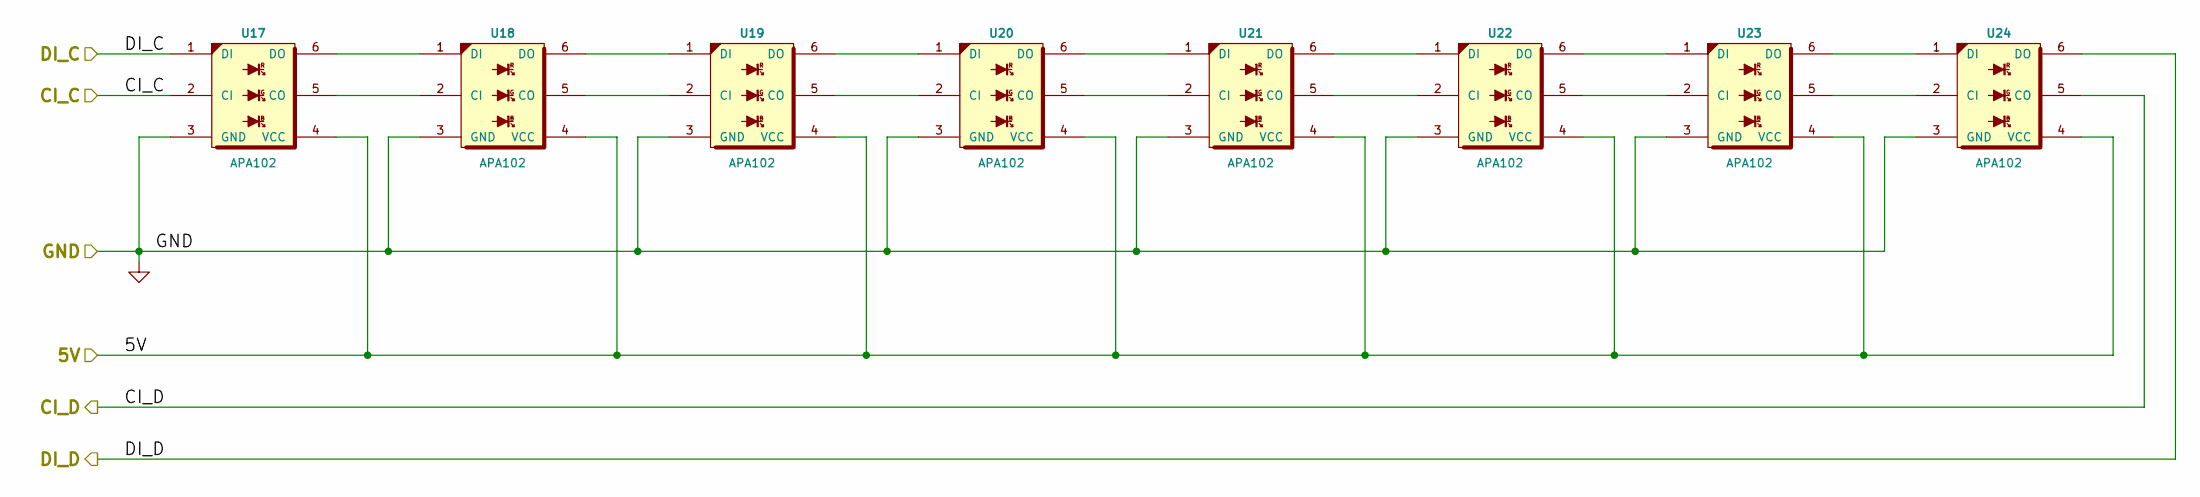
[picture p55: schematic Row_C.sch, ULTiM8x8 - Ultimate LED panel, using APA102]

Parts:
U17, U18, U20, U21, U22, U23, U24: APA102
U19: APA102; APA102_U19

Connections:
/Row_A/5V: U17.4 (VCC), U18.4 (VCC), U19.4 (VCC), U20.4 (VCC), U21.4 (VCC), U22.4 (VCC), U23.4 (VCC), U24.4 (VCC); also elsewhere on the board
/Row_B/CI_C: U17.2 (CI); also elsewhere on the board
/Row_B/DI_C: U17.1 (DI); also elsewhere on the board
/Row_C/CI_D: U24.5 (CO); also elsewhere on the board
/Row_C/DI_D: U24.6 (DO); also elsewhere on the board
GND: U17.3 (GND), U18.3 (GND), U19.3 (GND), U20.3 (GND), U21.3 (GND), U22.3 (GND), U23.3 (GND), U24.3 (GND); also elsewhere on the board
unnamed: U17.5 (CO), U18.2 (CI)
unnamed: U17.6 (DO), U18.1 (DI)
unnamed: U18.5 (CO), U19.2 (CI)
unnamed: U18.6 (DO), U19.1 (DI)
unnamed: U19.5 (CO), U20.2 (CI)
unnamed: U19.6 (DO), U20.1 (DI)
unnamed: U20.5 (CO), U21.2 (CI)
unnamed: U20.6 (DO), U21.1 (DI)
unnamed: U21.5 (CO), U22.2 (CI)
unnamed: U21.6 (DO), U22.1 (DI)
unnamed: U22.5 (CO), U23.2 (CI)
unnamed: U22.6 (DO), U23.1 (DI)
unnamed: U23.5 (CO), U24.2 (CI)
unnamed: U23.6 (DO), U24.1 (DI)

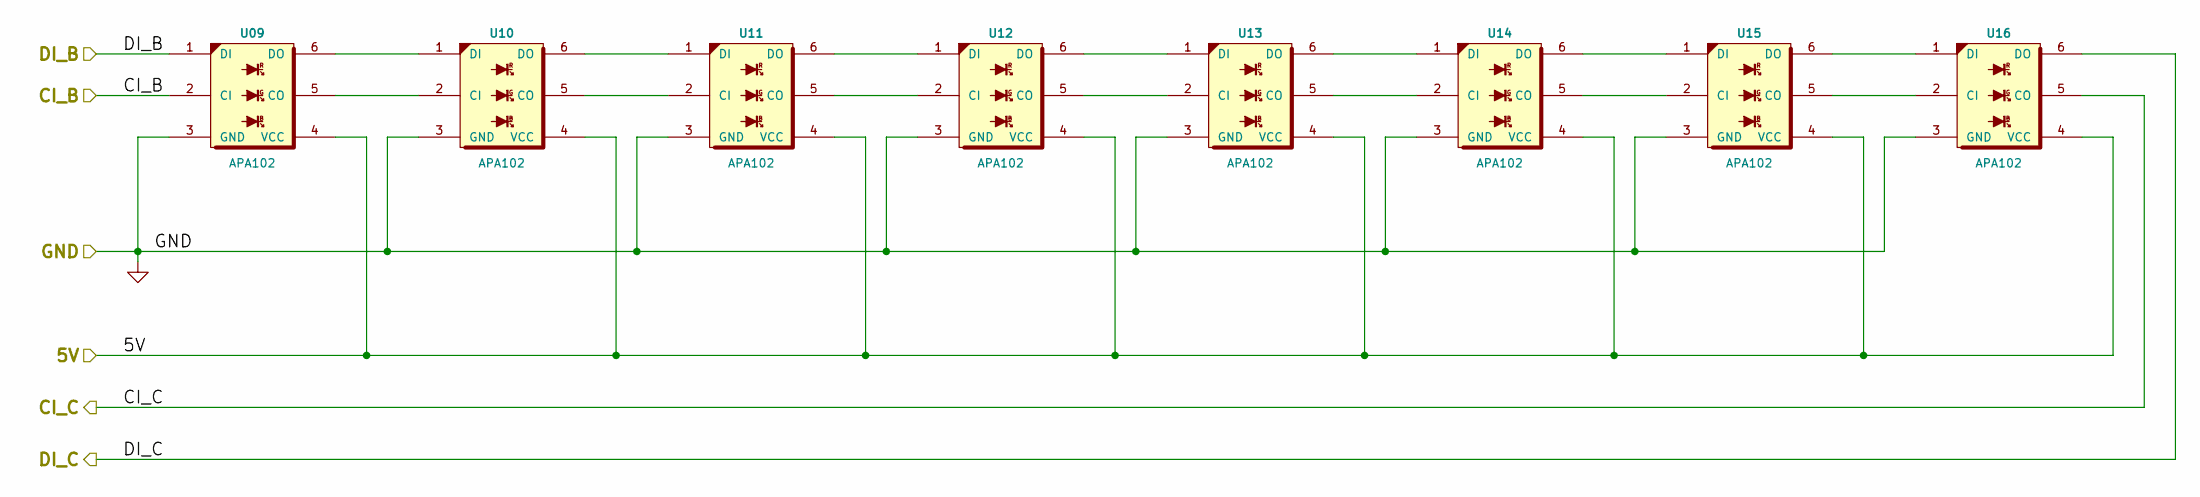
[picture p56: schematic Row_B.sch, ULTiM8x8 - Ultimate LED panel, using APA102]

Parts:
U09, U10, U13, U14, U15, U16: APA102
U11: APA102; APA102_U11
U12: APA102; APA102_U12

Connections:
/Row_A/5V: U09.4 (VCC), U10.4 (VCC), U11.4 (VCC), U12.4 (VCC), U13.4 (VCC), U14.4 (VCC), U15.4 (VCC), U16.4 (VCC); also elsewhere on the board
/Row_A/CI_B: U09.2 (CI); also elsewhere on the board
/Row_A/DI_B: U09.1 (DI); also elsewhere on the board
/Row_B/CI_C: U16.5 (CO); also elsewhere on the board
/Row_B/DI_C: U16.6 (DO); also elsewhere on the board
GND: U09.3 (GND), U10.3 (GND), U11.3 (GND), U12.3 (GND), U13.3 (GND), U14.3 (GND), U15.3 (GND), U16.3 (GND); also elsewhere on the board
unnamed: U09.5 (CO), U10.2 (CI)
unnamed: U09.6 (DO), U10.1 (DI)
unnamed: U10.5 (CO), U11.2 (CI)
unnamed: U10.6 (DO), U11.1 (DI)
unnamed: U11.5 (CO), U12.2 (CI)
unnamed: U11.6 (DO), U12.1 (DI)
unnamed: U12.5 (CO), U13.2 (CI)
unnamed: U12.6 (DO), U13.1 (DI)
unnamed: U13.5 (CO), U14.2 (CI)
unnamed: U13.6 (DO), U14.1 (DI)
unnamed: U14.5 (CO), U15.2 (CI)
unnamed: U14.6 (DO), U15.1 (DI)
unnamed: U15.5 (CO), U16.2 (CI)
unnamed: U15.6 (DO), U16.1 (DI)

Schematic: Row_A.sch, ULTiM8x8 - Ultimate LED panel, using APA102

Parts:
C1: 100nF; c_0805
C2: 47uF 20V; c_2917
U01, U02, U03, U04, U07, U08: APA102
U05: APA102; APA102_U05
U06: APA102; APA102_U06

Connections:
/Row_A/5V: C1.2, C2.1 (+), U01.4 (VCC), U02.4 (VCC), U03.4 (VCC), U04.4 (VCC), U05.4 (VCC), U06.4 (VCC), U07.4 (VCC), U08.4 (VCC); also elsewhere on the board
/Row_A/CI_A: U01.2 (CI); also elsewhere on the board
/Row_A/CI_B: U08.5 (CO); also elsewhere on the board
/Row_A/DI_A: U01.1 (DI); also elsewhere on the board
/Row_A/DI_B: U08.6 (DO); also elsewhere on the board
GND: C1.1, C2.2 (-), U01.3 (GND), U02.3 (GND), U03.3 (GND), U04.3 (GND), U05.3 (GND), U06.3 (GND), U07.3 (GND), U08.3 (GND); also elsewhere on the board
unnamed: U01.5 (CO), U02.2 (CI)
unnamed: U01.6 (DO), U02.1 (DI)
unnamed: U02.5 (CO), U03.2 (CI)
unnamed: U02.6 (DO), U03.1 (DI)
unnamed: U03.5 (CO), U04.2 (CI)
unnamed: U03.6 (DO), U04.1 (DI)
unnamed: U04.5 (CO), U05.2 (CI)
unnamed: U04.6 (DO), U05.1 (DI)
unnamed: U05.5 (CO), U06.2 (CI)
unnamed: U05.6 (DO), U06.1 (DI)
unnamed: U06.5 (CO), U07.2 (CI)
unnamed: U06.6 (DO), U07.1 (DI)
unnamed: U07.5 (CO), U08.2 (CI)
unnamed: U07.6 (DO), U08.1 (DI)

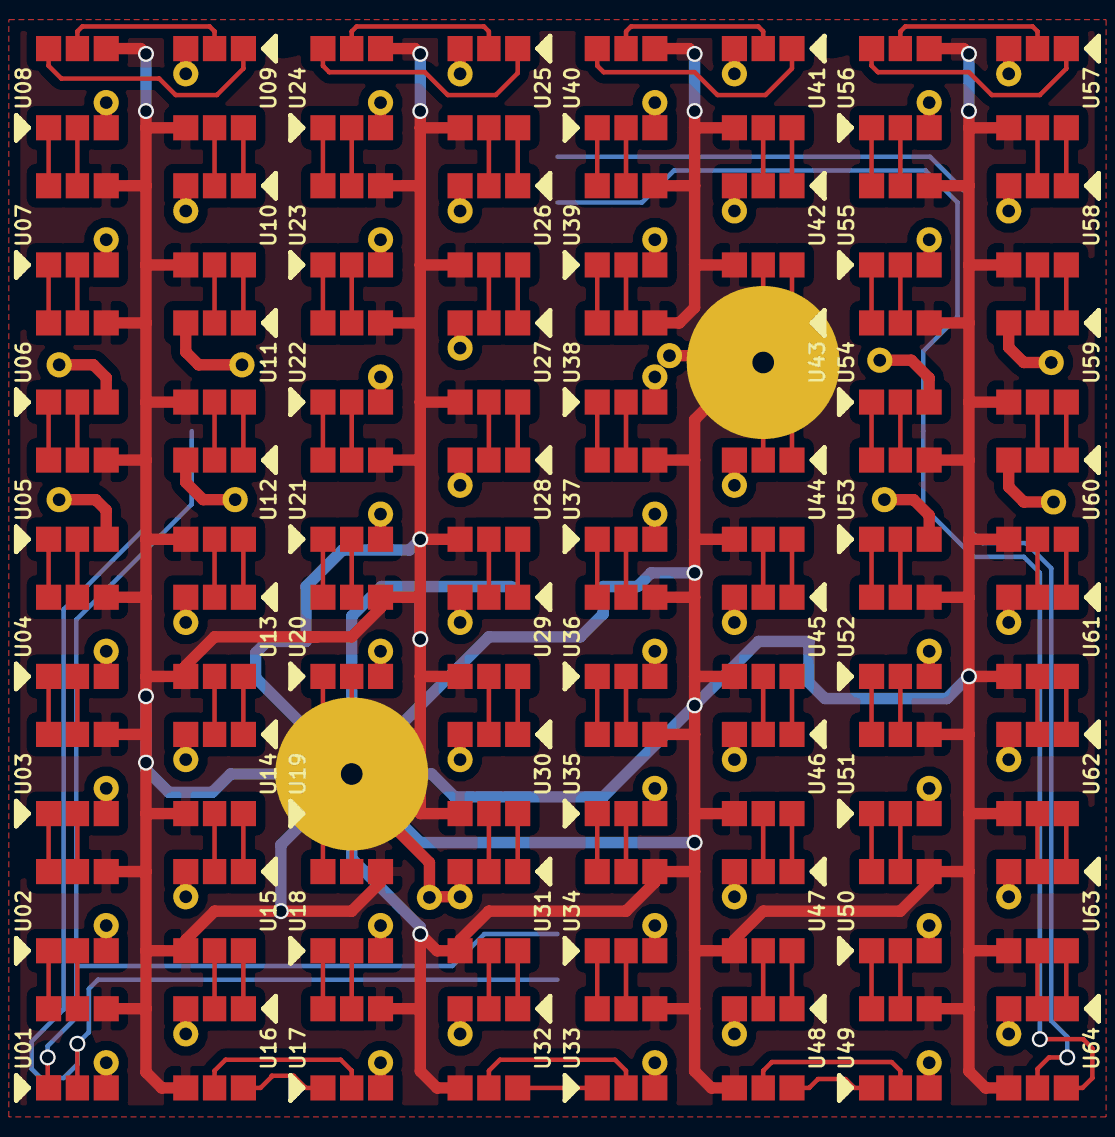
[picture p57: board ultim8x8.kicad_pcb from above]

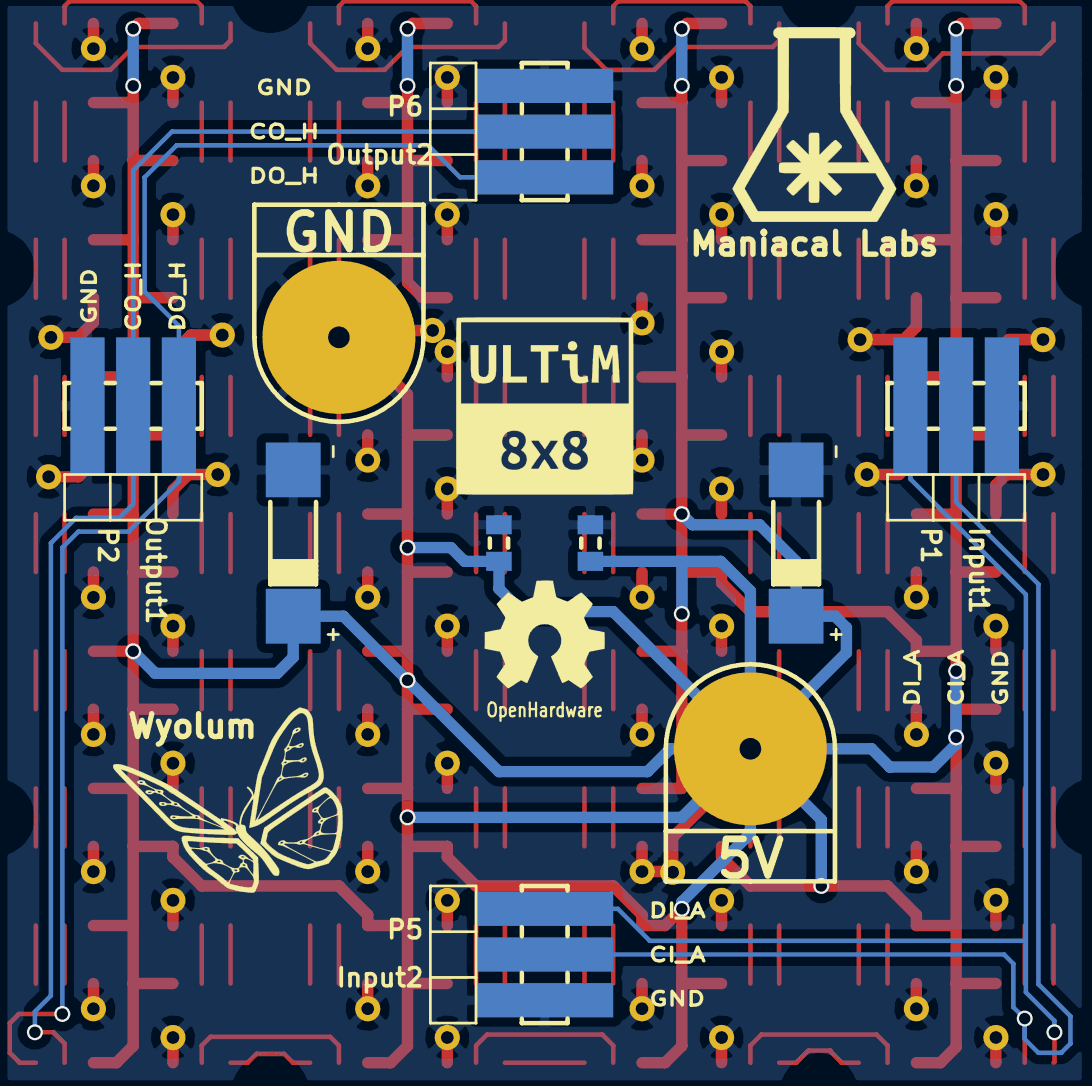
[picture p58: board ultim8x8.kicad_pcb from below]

Board: 2 copper layers, 78 parts (14 on the bottom side), 132 nets.

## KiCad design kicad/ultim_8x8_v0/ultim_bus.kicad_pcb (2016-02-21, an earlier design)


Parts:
L1, L2, L3, L4: OSHW; OSHW_6mm
L5, L6, L7, L8: WyoLum; logo_wyo_butterfly_small
L9, L10, L11, L12: Maniacal; logo_MLlabs_small
L13, L14, L15, L16: ULTiM; logo_ultim8x8_small
M1, M2, M3, M4, M5, M6, M7, M8, M9, M10, M11, M12, M13, M14, M15, M16: MouseBite; mouse-bite-2.54mm-slot
P1, P2, P3, P4, P5, P6, P7, P8, P9, P10, P11, P12, P13, P14, P15, P16, P17, P18, P19, P20, P21, P22, P23, P24, P25, P26, P27, P28, P29, P30, P31, P32, P33, P34, P35, P36, P37, P38, P39, P40, P41, P42, P43, P44, P45, P46, P47, P48, P49, P50, P51, P52, P53, P54, P55, P56, P57, P58, P59, P60, P61, P62, P63, P64, P65, P66, P67, P68, P69, P70, P71: CONN_1; Screw

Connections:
/ROW1: P1.1, P2.1, P3.1, P4.1, P5.1, P6.1, P7.1, P8.1, P9.1, P10.1, P11.1, P12.1, P67.1
/ROW2: P13.1, P14.1, P15.1, P16.1, P17.1, P18.1, P19.1, P20.1, P21.1, P22.1, P23.1, P24.1, P68.1
/ROW3: P31.1, P32.1, P33.1, P34.1, P35.1, P36.1, P37.1, P38.1, P39.1, P40.1, P41.1, P42.1, P69.1
/ROW4: P49.1, P50.1, P51.1, P52.1, P53.1, P54.1, P55.1, P56.1, P57.1, P58.1, P59.1, P60.1, P70.1


Board: 2 copper layers, 198.1 x 63.5 mm, 102 parts (0 on the bottom side), 4 nets.

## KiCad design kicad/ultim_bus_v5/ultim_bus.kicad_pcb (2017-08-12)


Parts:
C1: 470uF 10V; cap_pol_rad3
H1: Feather_Huzzah; FEATHER_Huzzah
JP1: PWR_SEL; switch_spdt
L1, L2: OSHW; OSHW_6mm
L3, L4: LOGO_WL; logo_wyo_butterfly_small
L7, L8: LOGO_ML; logo_MLlabs_small
L11, L12: LOGO_U88; logo_ultim8x8_small
M2, M3, M4, M9, M10, M11, M16, M17, M18: MouseBite; mouse-bite-5.08mm-slot
M6, M13: MouseBite; mouse-bite-2.54mm-slot
P1, P4, P5, P8, P9, P12, P15, P16, P19, P20, P23, P24, P28, P29, P32, P33, P36, P37, P40, P43, P44, P47, P48, P51: CONN_1; Screw_SqPad
P2, P3, P6, P7, P10, P11, P14, P17, P18, P21, P22, P25, P27, P30, P31, P34, P35, P38, P41, P42, P45, P46, P49, P50: CONN_1; Screw
R1, R2, R3, R4, R5, R6: 10k; r_0805
S1, S2, S3, S4, S5, S6: SPST-M-2; SW-PB
v1, v2, v3, v4, v5, v6, v7, v8, v9, v10, v11, v12, v13, v14, v15, v16: via_0.8x9

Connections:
/5V: C1.1 (+), JP1.2, P1.1, P2.1, P3.1, P4.1, P5.1, P6.1, P7.1, P8.1, P9.1, P10.1, P11.1, P12.1, R1.2, R2.2, R3.2, R4.2, R5.2, R6.2, v1.1, v1.2, v1.3, v1.4, v1.5, v1.6, v1.7, v1.8, v1.9, v2.1, v2.2, v2.3, v2.4, v2.5, v2.6, v2.7, v2.8, v2.9, v3.1, v3.2, v3.3, v3.4, v3.5, v3.6, v3.7, v3.8, v3.9, v13.1, v13.2, v13.3, v13.4, v13.5, v13.6, v13.7, v13.8, v13.9
/CLK: H1.23 (SCK), P14.1, P15.1, P24.1, P25.1, v7.1, v7.2, v7.3, v7.4, v7.5, v7.6, v7.7, v7.8, v7.9, v15.1, v15.2, v15.3, v15.4, v15.5, v15.6, v15.7, v15.8, v15.9
/CLK1: P20.1, P21.1, P22.1, P23.1, v8.1, v8.2, v8.3, v8.4, v8.5, v8.6, v8.7, v8.8, v8.9
/CLK2: P16.1, P17.1, P18.1, P19.1, v9.1, v9.2, v9.3, v9.4, v9.5, v9.6, v9.7, v9.8, v9.9
/DAT: H1.24 (MOSI), P27.1, P28.1, P37.1, P38.1, v10.1, v10.2, v10.3, v10.4, v10.5, v10.6, v10.7, v10.8, v10.9, v16.1, v16.2, v16.3, v16.4, v16.5, v16.6, v16.7, v16.8, v16.9
/DAT1: P33.1, P34.1, P35.1, P36.1, v11.1, v11.2, v11.3, v11.4, v11.5, v11.6, v11.7, v11.8, v11.9
/DAT2: P29.1, P30.1, P31.1, P32.1, v12.1, v12.2, v12.3, v12.4, v12.5, v12.6, v12.7, v12.8, v12.9
/GND: C1.2 (-), H1.16 (GND), P40.1, P41.1, P42.1, P43.1, P44.1, P45.1, P46.1, P47.1, P48.1, P49.1, P50.1, P51.1, S1.2, S2.2, S3.2, S4.2, S5.2, S6.2, v4.1, v4.2, v4.3, v4.4, v4.5, v4.6, v4.7, v4.8, v4.9, v5.1, v5.2, v5.3, v5.4, v5.5, v5.6, v5.7, v5.8, v5.9, v6.1, v6.2, v6.3, v6.4, v6.5, v6.6, v6.7, v6.8, v6.9, v14.1, v14.2, v14.3, v14.4, v14.5, v14.6, v14.7, v14.8, v14.9
/S1: H1.9 (14), R1.1, S1.1
/S2: H1.8 (12), R2.1, S2.1
/S3: H1.7 (13), R3.1, S3.1
/S4: H1.6 (15), R4.1, S4.1
/S5: H1.5 (0), R5.1, S5.1
/S6: H1.4 (16), R6.1, S6.1
/VBAT: H1.12 (BAT), JP1.1
/VUSB: H1.10 (USB), JP1.3

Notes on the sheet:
Solder Bridges to power ULTiM8x8 from USB or Battery
Feather Header
Switches, undefined
Vias, for the snap-offs
Capacitors, Electrolytic, for filtering
Switch Huzzah M0
S1 14 13 S2 12 12 S3 13 11 S4 15 10 S5 00 09 S6 16 06
In CODE, use following Arduino pins depending on board used - Huzzah or M0



Board: 2 copper layers, 177.8 x 55.9 mm, 98 parts (10 on the bottom side), 16 nets.

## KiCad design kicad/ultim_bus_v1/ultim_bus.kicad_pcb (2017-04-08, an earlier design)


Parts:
L1, L2: OSHW; OSHW_6mm
L3, L4, L5, L6: WyoLum; logo_wyo_butterfly_small
L7, L8, L9, L10: Maniacal; logo_MLlabs_small
L11, L12: ULTiM; logo_ultim8x8_small
M1, M2, M3, M4, M8, M9, M10, M11, M15, M16, M17, M18: MouseBite; mouse-bite-5.08mm-slot
M5, M6, M7, M12, M13, M14: MouseBite; mouse-bite-2.54mm-slot
P1, P4, P5, P8, P9, P12, P15, P16, P19, P20, P23, P24, P32, P33, P36, P37, P40, P43, P44, P47, P48, P51: CONN_1; Screw_SqPad
P2, P3, P6, P7, P10, P11, P13, P14, P17, P18, P21, P22, P25, P26, P27, P30, P31, P34, P35, P38, P39, P41, P42, P45, P46, P49, P50, P52: CONN_1; Screw
P28, P29: CONN_1; Screw_SSide
v1, v2, v3, v4, v5, v6, v7, v8, v9, v10, v11, v12: via_0.8x9

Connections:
/5V: P1.1, P2.1, P3.1, P4.1, P5.1, P6.1, P7.1, P8.1, P9.1, P10.1, P11.1, P12.1, P13.1, v1.1, v1.2, v1.3, v1.4, v1.5, v1.6, v1.7, v1.8, v1.9, v2.1, v2.2, v2.3, v2.4, v2.5, v2.6, v2.7, v2.8, v2.9, v3.1, v3.2, v3.3, v3.4, v3.5, v3.6, v3.7, v3.8, v3.9
/CLK: P24.1, P25.1, P26.1, v7.1, v7.2, v7.3, v7.4, v7.5, v7.6, v7.7, v7.8, v7.9
/CLK1: P20.1, P21.1, P22.1, P23.1, v8.1, v8.2, v8.3, v8.4, v8.5, v8.6, v8.7, v8.8, v8.9
/CLK2: P16.1, P17.1, P18.1, P19.1, v9.1, v9.2, v9.3, v9.4, v9.5, v9.6, v9.7, v9.8, v9.9
/CLK3: P14.1, P15.1
/DAT: P37.1, P38.1, P39.1, v10.1, v10.2, v10.3, v10.4, v10.5, v10.6, v10.7, v10.8, v10.9
/DAT1: P33.1, P34.1, P35.1, P36.1, v11.1, v11.2, v11.3, v11.4, v11.5, v11.6, v11.7, v11.8, v11.9
/DAT2: P29.1, P30.1, P31.1, P32.1, v12.1, v12.2, v12.3, v12.4, v12.5, v12.6, v12.7, v12.8, v12.9
/DAT3: P27.1, P28.1
/GND: P40.1, P41.1, P42.1, P43.1, P44.1, P45.1, P46.1, P47.1, P48.1, P49.1, P50.1, P51.1, P52.1, v4.1, v4.2, v4.3, v4.4, v4.5, v4.6, v4.7, v4.8, v4.9, v5.1, v5.2, v5.3, v5.4, v5.5, v5.6, v5.7, v5.8, v5.9, v6.1, v6.2, v6.3, v6.4, v6.5, v6.6, v6.7, v6.8, v6.9

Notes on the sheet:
LOGOS



Board: 2 copper layers, 198.1 x 55.9 mm, 94 parts (4 on the bottom side), 10 nets.

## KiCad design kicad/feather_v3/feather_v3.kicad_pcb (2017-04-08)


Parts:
H1: Feather_M0; FEATHER_M0_2
JP1: PWR_SEL; switch_spdt
L1: LOGO_U88; logo_ultim8x8_small
L2: OSHW; OSHW_6mm
L3: LOGO_WL; logo_wyo_butterfly_small
L4: LOGO_ML; logo_MLlabs_small
P1: Input1; header_2x2pos_th_male
P2: Output1; header_2x2pos_th_male
P3: 5V; Screw
P4: GND; Screw
P5: Input2; header_2x2pos_th_male
P6: Output2; header_2x2pos_th_male
P7: CI_A; Screw
P9: DI_A; Screw

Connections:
/GND: H1.4, P1.3, P2.3, P4.1, P5.4, P6.1
/MOSI: H1.12, P1.1, P5.3, P9.1
/SCK: H1.11, P1.2, P5.1, P7.1
/VBAT: H1.28, JP1.1
/VLED: JP1.2, P1.4, P2.1, P3.1, P5.2, P6.2
/VUSB: H1.26, JP1.3

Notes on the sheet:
Mounting Hole connections to ULTiM8x8
4 way Header for Input
Solder Bridges to power ULTiM8x8 from USB or Battery
Feather Header
Logos


Board: 2 copper layers, 52.1 x 52.1 mm, 14 parts (0 on the bottom side), 6 nets.

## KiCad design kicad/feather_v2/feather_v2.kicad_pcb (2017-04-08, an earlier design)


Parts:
JP1: PWR_SEL; switch_spdt
JP2: PWR_SEL2; switch_spdt
L1: LOGO_WL; logo_wyo_butterfly_small
L2: LOGO_ML; logo_MLlabs_small
L3: OSHW; OSHW_6mm
M1, M2: Screw; Screw_NPTH
P6: Input; header_2x2pos_th_male
P7: Output; header_2x2pos_th_male
P8: Feather_M0; FEATHER_M0

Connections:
/GND: P6.3, P7.1, P8.4
/MOSI: P6.4, P8.12
/SCK: P6.2, P8.11
/VBAT: JP1.1, JP2.3, P8.28
/VLED: JP1.2, JP2.2, P6.1, P7.3
/VUSB: JP1.3, JP2.1, P8.26

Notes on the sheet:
Mounting Holes



Board: 2 copper layers, 50.8 x 22.9 mm, 10 parts (5 on the bottom side), 6 nets.

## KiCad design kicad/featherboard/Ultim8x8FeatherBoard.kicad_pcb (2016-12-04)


Board: 2 copper layers, 55.7 x 55.7 mm, 11 parts (0 on the bottom side), 6 nets.

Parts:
JP1: JUMPER3; Pin_Header_Straight_1x03
P1: Maniacal Labs; logo_MLlabs
P2, P3: VLED; Screw
P4, P5: GND; Screw
P6: MOSI; Screw
P7: SCK; Screw
P8: CONN_01X16; Pin_Header_Straight_1x16
P9: CONN_01X12; Pin_Header_Straight_1x12
P10: WyoLum; logo_wyo_butterfly

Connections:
GND: P4.1, P5.1, P8.4
MOSI: P6.1, P8.12
SCK: P7.1, P8.11
VBAT: JP1.3, P9.12
VLED: JP1.2, P2.1, P3.1
VUSB: JP1.1, P9.10

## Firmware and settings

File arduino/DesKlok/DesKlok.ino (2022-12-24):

#include <Time.h>
#include <Wire.h>
#include <WiFiManager.h>
#include <FastLED.h>
#include <PubSubClient.h>
#include <EEPROM.h>
#include <EEPROMAnything.h>
#include <NTPClient.h>
#include <I2CNavKey.h>
//#define ULTIM8x16 // DullesKlok
#include <ESP8266HTTPClient.h>

#include "textures.h"
#include "Noise.h"
#include "logic.h"
#include "get_time.h"

#include "config.h"
#include "MatrixMap.h"
#include "digits.h"
#include "fonts.h"
#include "moon_phases.h"
#include "english_v3.h"

WiFiManager wifiManager;
WiFiUDP ntpUDP;
/*
Sunday
Monday
Tuesday
Wednesday
Thursday
Friday
Saturday
 */
const uint8_t N_DISPLAY = 9; // SNAKE DISABLED
const uint8_t N_BRIGHTNESS = 17;
const uint8_t BRIGHTNESSES[N_BRIGHTNESS] = {2,  3,  4,  5,  6,  7,  8, 10,
					    12, 14, 16, 19, 23, 27, 32, 38, 45};
bool setup_complete = false;
const int IntPin = 16; /* Definition of the interrupt pin*/


struct config_t{
  int timezone;
  uint8_t brightness;
  uint8_t display_idx;
  bool factory_reset;
  bool use_wifi;
  bool use_ip_timezone;
  byte mqtt_ip[4];
  bool flip_display;
  uint32_t last_tz_lookup; // look up tz info every Sunday at 3:00 AM
  uint8_t solid_color_rgb[3];
  uint8_t second_color_rgb[3];
  uint8_t third_color_rgb[3];
  bool use_ntp_time;
  bool wifi_reset;
  uint8_t faceplate_idx;
  uint8_t colorwheel_idx;
} config;

NTPClient timeClient(ntpUDP, "us.pool.ntp.org", 0, 60000); // do not use directly (only through ntp_clock)
NTPClock ntp_clock; // uses timeClient

uint16_t XY(int x, int y);
void set_timezone_offset(int32_t offset);
uint32_t Now();
void saveSettings();
void display_time(uint32_t last_time, uint32_t current_time);
void fillMask(bool* mask, bool b);
void fillMask(bool* mask, bool b, int start, int stop);
bool ip_from_str(char* str, byte* ip);

void Wheel(uint8_t WheelPos, uint8_t *red, uint8_t *green, uint8_t *blue);

void fillMask(bool val, bool *mask){
  for(int i=0;i<NUM_LEDS; i++){
    mask[i] = val;
  }
}

void maskPixel(byte row, byte col, bool val, bool *mask){
  uint16_t pos = XY(row, col);
  if(0 <= pos && pos < NUM_LEDS){
    mask[pos] = val;
  }
}

bool force_update = false;

//const bool ON = true;
//const bool OFF = !ON;

// How many leds are in the strip?
const uint8_t N_BOARD = 2;

bool mask[NUM_LEDS];
bool wipe[NUM_LEDS];

WiFiClient espClient;

#define DATA_PIN     MOSI
#define CLK_PIN      SCK

#define COLOR_ORDER BGR
#define LED_TYPE APA102
#define MILLI_AMPS 2000  // IMPORTANT: set the max milli-Amps of your power supply (4A = 4000mA)

uint32_t last_time;
bool sleeping = false;

//********************************************************************************
// Displays

void my_show(){
  FastLED.show();
}

typedef void (*Init)();
typedef void (*DisplayTime)(uint32_t last_tm, uint32_t tm);

String jsonLookup(String s, String name){
  int start = s.indexOf(name) + name.length() + 3;
  int stop = s.indexOf('"', start);
  Serial.println(s.substring(start, stop));
  return s.substring(start, stop);
}

void set_timezone_from_ip(){

  HTTPClient http;
  
  Serial.print("[HTTP] begin...\n");
  // configure traged server and url
  //http.begin("https://www.howsmyssl.com/a/check", ca); //HTTPS
  // http.begin("http://example.com/index.html"); //HTTP

  //http.begin("https://timezoneapi.io/api/ip");// no longer works!
  //http.begin("https://ipapi.co/json");
  String url = String("http://www.wyolum.com/utc_offset/utc_offset.py") +
    String("?refresh=") + String(millis()) +
    String("&localip=") +
    String(WiFi.localIP()[0]) + String('.') + 
    String(WiFi.localIP()[1]) + String('.') + 
    String(WiFi.localIP()[2]) + String('.') + 
    String(WiFi.localIP()[3]) + String('&') +
    String("macaddress=") + WiFi.macAddress() + String('&') + 
    String("dev_type=DesKlok");
  Serial.println(url);
  http.begin(url);
  
  Serial.print("[HTTP] GET...\n");
  // start connection and send HTTP header
  int httpCode = http.GET();
  
  // httpCode will be negative on error
  if(httpCode > 0) {
    // HTTP header has been send and Server response header has been handled
    Serial.printf("[HTTP] GET... code: %d\n", httpCode);
    
    // file found at server
    //String findme = String("offset_seconds");
    if(httpCode == HTTP_CODE_OK) {
      String payload = http.getString();
      Serial.print("payload:");
      Serial.println(payload);
      payload.replace(" ", "");
      String offset_str = jsonLookup(payload, String("utc_offset"));
      int hours = offset_str.substring(0, 3).toInt();
      int minutes = offset_str.substring(3, 5).toInt();
      if(hours < 0){
	minutes *= -1;
      }
      int offset = hours * 3600 + minutes * 60;

      if(config.use_ip_timezone){
	Serial.print("timezone_offset String:");
	Serial.println(offset_str);
	Serial.print("timezone_offset:");
	Serial.println(offset);
	set_timezone_offset(offset);
	config.last_tz_lookup = Now();
	saveSettings();
      }
      else{
	Serial.println("Using previously selected timezone");
      }
    }
    else{
      Serial.println("No timezone found");
    }
  }
  else{
    Serial.print("[HTTP]    ... Failed:");
    Serial.println(httpCode);
  }
}

void setPixelMask(bool* mask, uint8_t row, uint8_t col, bool b){
  if(row >= MatrixHeight){
  }
  else if(col >= MatrixWidth){
  }
  else{
    uint16_t pos = XY(col, row);
    if(pos < NUM_LEDS){
      mask[pos] = b;
    }
  }
}

typedef struct{
  Init       init;           // called when display changes
  DisplayTime display_time;  // called in main loop to update time display (if needed)
  String     name;
  int        id;
} Display;

//--------------------------------------------------------------------------------
//uint32_t current_time;

void fill_red(){
  fill_solid(leds, NUM_LEDS, CRGB::Red);
}
void fill_green(){
  fill_solid(leds, NUM_LEDS, CRGB::Green);
}
void fill_blue(){
  fill_solid(leds, NUM_LEDS, CRGB::Blue);
}
void fill_white(){
  fill_solid(leds, NUM_LEDS, CRGB::White);
}
void fill_black(){
  fill_solid(leds, NUM_LEDS, CRGB::Black);
}
void noop(){
}

uint8_t logo_rgb[] = {
  0x11,0x00,0x29,0x00,0x25,0x00,0x23,0x00,0x25,0x00,0x29,0x00,0x31,0x00,0xe0,0x01,
  0x00,0x03,0x80,0x04,0x80,0x04,0x80,0x04,0x80,0x04,0x00,0x03,0x00,0x00,0x00,0x00,
  0x11,0x00,0x09,0x88,0x05,0x48,0x03,0x28,0x05,0x18,0x09,0x28,0x11,0x48,0x00,0x88
};

void add_to_timezone(int32_t offset){ 
  config.timezone += offset;
  config.use_ip_timezone = false; // time zone manually changed... ignore internate timezone
  saveSettings();
  if(config.use_wifi){
    ntp_clock.setOffset(config.timezone);
  }
}

void set_timezone_offset(int32_t offset){
  config.timezone = offset % 86400;
  saveSettings();
  if(config.use_wifi){
    ntp_clock.setOffset(config.timezone);
  }
}

void display_bitmap_rgb(uint8_t* bitmap){
  uint8_t n = 16;
  uint8_t h = 8;
  uint8_t w = 16;
  uint8_t xy[2];
  uint8_t r, g, b;
  
  int i, j;
  int led_idx, byte_idx;

  //struct CRGB color;
  int x, y;
  
  for(i=0; i<n; i++){
    r = bitmap[i + 0 * w];
    g = bitmap[i + 1 * w];
    b = bitmap[i + 2 * w];
    //   012345678pabcdef
    // 0 0000000011111111
    // 1 2222222233333333
    // 2 4444444455555555
    // 3 6666666677777777
    // 4 8888888899999999
    // 5 aaaaaaaabbbbbbbb
    // 6 ccccccccdddddddd
    // 7 eeeeeeeeffffffff
    for(j=0; j<8; j++){
      x = (i * 8 + j) % 16;
      y = i / 2;
      led_idx = XY(x, y);
      leds[led_idx].red   = 255 * ((r >> j) & 1);
      leds[led_idx].green = 255 * ((g >> j) & 1);
      leds[led_idx].blue  = 255 * ((b >> j) & 1);
      if(leds[led_idx].red || leds[led_idx].green || leds[led_idx].blue){
	mask[led_idx] = true;
      }
    }
  }
}

void fillMask(bool* mask, bool b){
  fillMask(mask, b, 0, NUM_LEDS);
}

void fillMask(bool* mask, bool b, int start, int stop){
  for(int i = start; i < stop && i < NUM_LEDS; i++){
    mask[i] = b;
  }
}

void loadSettings(){
  EEPROM_readAnything(0, config);
}

void saveSettings(){
  EEPROM_writeAnything(0, config);
  EEPROM.commit();
}

void paintMask(bool* mask, CRGB color){
  uint16_t b, k;
  for(uint16_t i=0; i < NUM_LEDS; i++){
    if(mask[i]){
      leds[i] = color;
    }
  }
}

void bigDigit(int x, int y, byte digit, bool* mask){
  byte row, col;
  if(digit < 10){
    for(col = 0; col < 8; col++){
      for(row = 0; row < 16; row++){
	if((digits8x16[digit * 16 + row] >> col) & 1){
	  maskPixel(col + x, row + y, true, mask);
	}
	else{
	  maskPixel(col + x, row + y, false, mask);
	}
      }
    }
  }
}

void middleDigit(int x, int y, byte digit, bool* mask){
  byte row, col;
  if(digit < 10){
    for(col = 0; col < 7; col++){
      for(row = 0; row < 11; row++){
	int _row = 11 - row - 1;
	int _col = 7 - col - 1;
	if((digits7x11[digit * 11 + _row] >> _col) & 1){
	  maskPixel(col + x, row + y, true, mask);
	}
	else{
	  maskPixel(col + x, row + y, false, mask);
	}
      }
    }
  }
}

void moonPhase(int x, int y, bool* mask){
  uint8_t row, col;
  uint8_t phase_idx = 0;
  uint8_t i;
  double theta;
  const uint8_t *phase;

  // some strange bug if get_moon_phase is called prior to setup completion
  if(setup_complete){
    theta = get_moon_phase(ntp_clock.gmt());
  }
  
  int theta_byt = (int)((theta * 256) / (2 * PI));
  // find phase index
  for(i = 1; i < N_MOON_PHASE; i++){
    if(moon_phases_11x11[i * MOON_PHASE_STEP] > theta_byt){
      phase_idx = i - 1;
      break;
    }
  }
  uint8_t bit, byt;
  uint16_t n; // pixel counter
  bool val;
  phase = &moon_phases_11x11[phase_idx * MOON_PHASE_STEP];
  if(phase_idx < N_MOON_PHASE){
    for(col = 0; col < 11; col++){
      for(row = 0; row < 11; row++){
	n = row * 11 + col;
	byt = n / 8 + 1; // plus one for theta_byt
	bit = n % 8;
	if (byt < MOON_PHASE_STEP){
	  val = (phase[byt] >> bit) & 1;
	  maskPixel(col + x, row + y, val, mask);
	}
      }
    }
    maskPixel(x + 10, y + 10, false, mask); // last always off
  }
}

void littleDigit(int x, int y, byte digit, bool* mask){
  byte row, col;
  if(digit < 10){
    for(col = 0; col < 4; col++){
      for(row = 0; row < 7; row++){
	if((digits4x7[digit * 4 + col] >> row) & 1){
	  maskPixel(col + x, row + y, true, mask);
	}
	else{
	  maskPixel(col + x, row + y, false, mask);
	}
      }
    }
  }
}

void littleChar(uint8_t x, uint8_t y, char c, bool *mask){
  uint8_t idx = (uint8_t)c - 32;
  byte row, col;
  const unsigned char* pixels = font_5x6[idx];
  
  if(idx < 96){
    for(col = 0; col < 5; col++){
      for(row = 0; row < 5; row++){
	if((pixels[col] >> (row+2)) & 1){
	  maskPixel(col + x, row + y, true, mask);
	}
	else{
	  maskPixel(col + x, row + y, false, mask);
	}
      }
    }
  }
}

void bigChar(uint8_t x, uint8_t y, char c, bool *mask){
  uint8_t idx = (uint8_t)c - 32;
  byte row, col;
  const unsigned char* pixels = font_7x13[idx];
  
  if(idx < 96){
    for(col = 0; col < 7; col++){
      for(row = 0; row < 13; row++){
	if((pixels[12-row] >> (7-col)) & 1){
	  maskPixel(col + x, row + y, true, mask);
	}
	else{
	}
      }
    }
  }
}

uint8_t hex2dig(char h){
  uint8_t d = 0;
  if('0' <= h && h <= '9'){
    d = (uint8_t)(h - '0');
  }
  else if('a' <= h && h <= 'f'){
    d = (uint8_t)(10 + h - 'a');
  }
  else if('A' <= h && h <= 'F'){
    d = (uint8_t)(10 + h - 'A');
  }
  return d;
}

uint8_t hh2dd(char *hh){
  return hex2dig(hh[0]) * 16 + hex2dig(hh[1]);
}

bool force_timezone_from_ip = false;

void Wheel(uint8_t WheelPos, uint8_t *red, uint8_t *green, uint8_t *blue) {
  uint8_t r, g, b;
  WheelPos = 255 - WheelPos;
  if(WheelPos < 85) {
    r = 255 - WheelPos * 3;
    g = 0;
    b = WheelPos * 3;
  }
  else if(WheelPos < 170) {
    WheelPos -= 85;
    r = 0;
    g = WheelPos * 3;
    b = 255 - WheelPos * 3;
  }
  else{
    WheelPos -= 170;
    r = WheelPos * 3;
    g = 255 - WheelPos * 3;
    b = 0;
  }
  *red = r;
  *green = g;
  *blue = b;
}

void prev_display(){
    config.display_idx = (config.display_idx + N_DISPLAY - 1) % N_DISPLAY;
    saveSettings();
    Serial.print("Display incremented to: ");
    Serial.print(config.display_idx);
}

void next_display(){
    config.display_idx = (config.display_idx + 1) % N_DISPLAY;
    saveSettings();
    Serial.print("Display incremented to: ");
    Serial.print(config.display_idx);
}

void toggle_sleep(){
  sleeping = !sleeping;
  if(sleeping){
    Serial.println("Going to sleep.");
  }
  else{
    Serial.println("Waking up.");
  }
}

bool ip_from_str(char* str, byte* ip){
  byte my_ip[4];
  int end_poss[4];
  int i = 0, j = 0;
  int dots_found = 0;
  bool out = false;
  byte num;
  String strstr = String(str);
  
  Serial.println("ip_from_str");
  Serial.println(str);
  while(i < strlen(str) && dots_found < 3){
    if(str[i] == '.'){
      end_poss[dots_found] = i;
      dots_found++;
    }
    i++;
  }
  if(dots_found == 3){
    out = true;
    end_poss[3] = strlen(str);
    for(i = 0; i < 4; i++){
      num = String(strstr.substring(j, end_poss[i])).toInt();
      if(num == 0){
	out = false;
      }
      ip[i] = num;
      j = end_poss[i] + 1;
    }
  }
  if(out){
    Serial.print("IP: ");
    for(i=0; i<4; i++){
      Serial.print(ip[i]);
      if(i < 3){
	Serial.print(".");
      }
    }
    Serial.println();
  }
  return out;
}

void splash(){
  // display_time(86400, 86400);

  fillMask(false, mask);
  
  //fill_solid(leds, NUM_LEDS, CRGB::Blue);
  fill_solid(leds, NUM_LEDS, CRGB(config.solid_color_rgb[0],
  				  config.solid_color_rgb[1],
  				  config.solid_color_rgb[2]));

  int start_x = 3;
  int start_y = 8;
  littleChar(start_x +  0, start_y, 'W', mask);
  littleChar(start_x +  6, start_y, 'Y', mask);
  littleChar(start_x + 12, start_y, 'O', mask);
  littleChar(start_x + 0, start_y + 7 * 1, 'B', mask);
  littleChar(start_x + 5, start_y + 7 * 2, 'E', mask);
  littleChar(start_x + 10, start_y + 7 * 3, 'A', mask);
  littleChar(start_x + 15, start_y + 7 * 4, 'N', mask);
  my_show();
}

void led_setup(){
  FastLED.addLeds<LED_TYPE, DATA_PIN, CLK_PIN, COLOR_ORDER>(leds, NUM_LEDS);
  FastLED.setDither(true);
  FastLED.setCorrection(TypicalLEDStrip);
  FastLED.setMaxPowerInVoltsAndMilliamps(5, MILLI_AMPS);
  FastLED.setBrightness(BRIGHTNESSES[config.brightness]);
  splash();
}

void wifi_setup(){
  //wifiManager.resetSettings();
  if(config.wifi_reset){
    config.wifi_reset = false;
    saveSettings();
    wifiManager.startConfigPortal("DesKlok");
  }
  else{
    wifiManager.autoConnect("DesKlok");
  }
  Serial.println("Yay connected!");
  Serial.println("IP address: ");
  Serial.println(WiFi.localIP());
}


/*********************************************************************************/
void hexdump(const void *mem, uint32_t len, uint8_t cols) {
	const uint8_t* src = (const uint8_t*) mem;
	Serial.printf("\n[HEXDUMP] Address: 0x%08X len: 0x%X (%d)", (ptrdiff_t)src, len, len);
	for(uint32_t i = 0; i < len; i++) {
		if(i % cols == 0) {
			Serial.printf("\n[0x%08X] 0x%08X: ", (ptrdiff_t)src, i);
		}
		Serial.printf("%02X ", *src);
		src++;
	}
	Serial.printf("\n");
}

void factory_reset(){
  Serial.println("Factory RESET");
  config.timezone = 255; //?
  config.brightness = 6;
  config.display_idx = 255;
  config.use_wifi = 255;
  config.use_ip_timezone = 255;
  config.mqtt_ip[0] = 255;
  config.mqtt_ip[1] = 255;
  config.mqtt_ip[2] = 255;
  config.mqtt_ip[3] = 255;
  config.solid_color_rgb[0] = 0;
  config.solid_color_rgb[1] = 0;
  config.solid_color_rgb[2] = 255;
  config.second_color_rgb[0] = 0;
  config.second_color_rgb[1] = 255;
  config.second_color_rgb[2] = 0;
  config.third_color_rgb[0] = 255;
  config.third_color_rgb[1] = 0;
  config.third_color_rgb[2] = 0;
  config.flip_display = 255;
  config.last_tz_lookup = 0;
  config.use_ntp_time = true;
  config.wifi_reset = true;
  config.faceplate_idx = 255;
  config.colorwheel_idx = 0;
  config.factory_reset = false;
  saveSettings();

  Serial.println("Factory reset complete");
  ESP.restart();
}

void set_brightness(uint8_t brightness){
  if(brightness < N_BRIGHTNESS){
    config.brightness = brightness;
    FastLED.setBrightness(BRIGHTNESSES[config.brightness]);
    Serial.print("Adjust brightness to ");
    Serial.println(config.brightness);
    saveSettings();
  }
}

void setup(){
  my_leds = &leds[0];
  last_time = 0;
  
  Wire.begin();
  Serial.begin(115200);
  
  delay(200);
  Serial.println("setup() starting");

  EEPROM.begin(1024);
  loadSettings();
  // logo
  if(config.brightness >= N_BRIGHTNESS){
    set_brightness(6);
  }
  
  led_setup(); // set up leds first so buttons can affect display if needed
  //factory_reset(); // manually call once, then recomment out and upload
  if(config.factory_reset){// do factory reset on first on
    factory_reset();
  }

  if(config.display_idx == 255){
    config.display_idx = 0;
    saveSettings();
  }
  
  if(config.use_wifi){
    wifi_setup();
  }

  if(config.use_wifi){
    if(config.use_ntp_time){
      ntp_clock.setup(&timeClient);
      ntp_clock.setOffset(config.timezone);
    }
    set_timezone_from_ip();
  }
  Serial.print("config.timezone: ");
  Serial.println(config.timezone);
  Serial.print("config.use_ip_timezone: ");
  Serial.println((bool)config.use_ip_timezone);

  
  Serial.println("setup() complete");
  setup_complete = true;
}

uint32_t Now(){
  uint32_t out;
  
  if(config.use_wifi){
    if(config.use_ntp_time){
      out = ntp_clock.now();
      if(weekday(out) == 0){ // refresh utc offset sunday between 3 and 4 AM
	if(hour(out) == 3){
	  if(minute(out) > 1){ 
	    if(out - config.last_tz_lookup > 3601){
	      set_timezone_from_ip();
	    }
	  }
	}
      }
    }
    else{
      out = 42; // debug display
    }
  }
  else{
    out = 43; // debug display
  }
  return out;
}

void tobytes(const char *frm, byte *_to, int len){
  for(int ii = 0; ii < len; ii++){
    _to[ii] = frm[ii];
  }
}

void tochars(const char *frm, char *_to, int len){
  for(int ii = 0; ii < len; ii++){
    _to[ii] = frm[ii];
  }
  _to[len] = 0;
}


void getword(int i, uint8_t* out){
  out[0] = pgm_read_byte(WORDS + 3 * i + 1);
  out[1] = pgm_read_byte(WORDS + 3 * i + 2);
  out[2] = pgm_read_byte(WORDS + 3 * i + 3);
}
void get_time_display(bool* mask, int i){
  uint8_t bits;     // holds the on off state for 8 words at a time
  uint8_t word[3];  // start columm, start row, length of the current word
  uint8_t n_byte_per_display = 4;         // number of bytes used for each 5 minunte time incriment

  for(uint8_t j = 0; j < n_byte_per_display; j++){ // j is a byte index 
    
    // read the state for the next set of 8 words
    bits = pgm_read_byte(DISPLAYS + 1 + (i * n_byte_per_display) + j);
    Serial.print(bits);
    Serial.print(" ");
    for(uint8_t k = 0; k < 8; k++){                     // k is a bit index
      if((bits >> k) & 1){                              // check to see if word is on or off
	getword(j * 8 + k, word);                       // if on, read location and length
	for(int m=word[0]; m < word[0] + word[2]; m++){ // and display it
	  setPixelMask(mask, word[1], m, true);
	}
      }
    }
    Serial.println();
  } 
}

void display_time(uint32_t last_time, uint32_t current_time){
  int spm = current_time % 86400;
  int time_inc = spm / 300;
  fillMask(mask, false);
  get_time_display(mask, time_inc);
  for(int i=0; i< NUM_LEDS; i++){
    if(mask[i]){
      leds[i] = CRGB::Blue;
    }
    else{
      leds[i] = CRGB::Black;
    }
  }
}

void loop(){
  uint8_t word[3];
  uint32_t current_time = Now();
  uint8_t current_month, current_day, current_dow;
  
  display_time(last_time, current_time);
  my_show();
  return;
}

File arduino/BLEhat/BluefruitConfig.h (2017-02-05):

// COMMON SETTINGS
// ----------------------------------------------------------------------------------------------
// These settings are used in both SW UART, HW UART and SPI mode
// ----------------------------------------------------------------------------------------------
#define BUFSIZE                        128   // Size of the read buffer for incoming data
#define VERBOSE_MODE                   true  // If set to 'true' enables debug output
#define BLE_READPACKET_TIMEOUT         5   // Timeout in ms waiting to read a response


// SOFTWARE UART SETTINGS
// ----------------------------------------------------------------------------------------------
// The following macros declare the pins that will be used for 'SW' serial.
// You should use this option if you are connecting the UART Friend to an UNO
// ----------------------------------------------------------------------------------------------
#define BLUEFRUIT_SWUART_RXD_PIN       9    // Required for software serial!
#define BLUEFRUIT_SWUART_TXD_PIN       10   // Required for software serial!
#define BLUEFRUIT_UART_CTS_PIN         11   // Required for software serial!
#define BLUEFRUIT_UART_RTS_PIN         -1   // Optional, set to -1 if unused


// HARDWARE UART SETTINGS
// ----------------------------------------------------------------------------------------------
// The following macros declare the HW serial port you are using. Uncomment
// this line if you are connecting the BLE to Leonardo/Micro or Flora
// ----------------------------------------------------------------------------------------------
#ifdef Serial1    // this makes it not complain on compilation if there's no Serial1
  #define BLUEFRUIT_HWSERIAL_NAME      Serial1
#endif


// SHARED UART SETTINGS
// ----------------------------------------------------------------------------------------------
// The following sets the optional Mode pin, its recommended but not required
// ----------------------------------------------------------------------------------------------
#define BLUEFRUIT_UART_MODE_PIN        12    // Set to -1 if unused


// SHARED SPI SETTINGS
// ----------------------------------------------------------------------------------------------
// The following macros declare the pins to use for HW and SW SPI communication.
// SCK, MISO and MOSI should be connected to the HW SPI pins on the Uno when
// using HW SPI.  This should be used with nRF51822 based Bluefruit LE modules
// that use SPI (Bluefruit LE SPI Friend).
// ----------------------------------------------------------------------------------------------
#define BLUEFRUIT_SPI_CS               8
#define BLUEFRUIT_SPI_IRQ              7
#define BLUEFRUIT_SPI_RST              4   // Optional but recommended, set to -1 if unused

// SOFTWARE SPI SETTINGS
// ----------------------------------------------------------------------------------------------
// The following macros declare the pins to use for SW SPI communication.
// This should be used with nRF51822 based Bluefruit LE modules that use SPI
// (Bluefruit LE SPI Friend).
// ----------------------------------------------------------------------------------------------
#define BLUEFRUIT_SPI_SCK              13
#define BLUEFRUIT_SPI_MISO             12
#define BLUEFRUIT_SPI_MOSI             11

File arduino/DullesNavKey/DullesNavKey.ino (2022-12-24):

#include <Time.h>
#include <Wire.h>
#include <WiFiManager.h>
#include <FastLED.h>
#include <PubSubClient.h>
#include <EEPROM.h>
#include <EEPROMAnything.h>
#include <NTPClient.h>
#include <WebSocketsServer.h>
#include "Noise.h"

#include <I2CNavKey.h>

#include "english_v3.h"

//#define ULTIM8x16 // DullesKlok
#include <ESP8266HTTPClient.h>

#include "textures.h"
#include "logic.h"
#include "get_time.h"
#include "config.h"
#include "MatrixMap.h"
#include "digits.h"
#include "fonts.h"
#include "moon_phases.h"

const int IntPin = 16; /* Definition of the interrupt pin*/
//Class initialization with the I2C addresses

// header ################################################################################
void set_timezone_offset(int32_t offset);
uint32_t Now();
void saveSettings();
void display_time(uint32_t last_time, uint32_t current_time);
void apply_mask(bool* mask);
void apply_mask(bool* mask, CRGB color);
void fillMask(bool* mask, bool b);
void fillMask(bool* mask, bool b, int start, int stop);
bool ip_from_str(char* str, byte* ip);

void word_drop_in(uint16_t time_inc, bool* mask);
void word_drop_out(uint16_t time_inc);
void word_drop(uint16_t last_time_inc, uint16_t time_inc);
void fade_transition(uint16_t time_inc, uint16_t last_time_inc);
void plain_jane(uint16_t last_time_inc, uint16_t time_inc);
void TheMatrix(uint16_t last_time_inc, uint16_t time_inc);
void wipe_around_transition(uint16_t last_time_inc, uint16_t time_inc);
void setPixelMask(bool* mask, uint8_t row, uint8_t col, bool b);
void get_time_display(bool* mask, int i);
void getword(int i, uint8_t* out);
void setWordMask(bool *mask, uint8_t* word, bool b);
void prev_display();
void next_display();
void UP_Button_Pressed(i2cNavKey* p);
void DOWN_Button_Pressed(i2cNavKey* p);
void LEFT_Button_Pressed(i2cNavKey* p);
void RIGHT_Button_Pressed(i2cNavKey* p);
void CENTRAL_Button_Pressed(i2cNavKey* p);
void CENTRAL_Button_Double(i2cNavKey* p);
void Encoder_Rotate(i2cNavKey* p);
void toggle_power();
void dimmer();
void brighter();
void fill_color();
void fill_second_color();
void fill_blue();
void fill_red();
void fill_green();
void Wheel(uint8_t WheelPos, uint8_t *red, uint8_t *green, uint8_t *blue);

struct config_t{
  int timezone;
  uint8_t brightness;
  uint8_t display_idx;
  bool factory_reset;
  bool use_wifi;
  bool use_ip_timezone;
  byte mqtt_ip[4];
  bool flip_display;
  uint32_t last_tz_lookup; // look up tz info every Sunday at 3:00 AM
  uint8_t solid_color_rgb[3];
  uint8_t second_color_rgb[3];
  uint8_t third_color_rgb[3];
  bool use_ntp_time;
  bool wifi_reset;
  uint8_t faceplate_idx;
} config;


// end header ################################################################################

// navkey callbacks
//******************************************************************************
i2cNavKey navkey(0b0010000); /* Default address when no jumper are soldered */
void UP_Button_Pressed(i2cNavKey* p) {
  Serial.println("Button UP Pressed!");
  prev_display();
}

void DOWN_Button_Pressed(i2cNavKey* p) {
  Serial.println("Button DOWN Pressed!");
  next_display();
}

void LEFT_Button_Pressed(i2cNavKey* p) {
  Serial.println("Button LEFT Pressed!");
  dimmer();
}

void RIGHT_Button_Pressed(i2cNavKey* p) {
  Serial.println("Button RIGHT Pressed!");
  brighter();
}

void CENTRAL_Button_Pressed(i2cNavKey* p) {
  Serial.println("Button Central Pressed!");
  toggle_power();
}

void CENTRAL_Button_Double(i2cNavKey* p) {
  Serial.println("Button Central Double push!");
}

void Encoder_Rotate(i2cNavKey* p) {
  byte wheel_val = (byte)p->readCounterInt();
  Serial.println(wheel_val);
  Wheel(wheel_val,
	&config.solid_color_rgb[0],
	&config.solid_color_rgb[1],
	&config.solid_color_rgb[2]);
  Wheel(wheel_val + 85,
	&config.second_color_rgb[0],
	&config.second_color_rgb[1],
	&config.second_color_rgb[2]);
  Wheel(wheel_val + 85 * 2,
	&config.third_color_rgb[0],
	&config.third_color_rgb[1],
	&config.third_color_rgb[2]);
  saveSettings();
}
// end navkey callbacks
//********************************************************************************

WiFiManager wifiManager;
WiFiUDP ntpUDP;
/*
Sunday
Monday
Tuesday
Wednesday
Thursday
Friday
Saturday
 */

const uint8_t N_BRIGHTNESS = 18;
const uint8_t BRIGHTNESSES[N_BRIGHTNESS] = {2,  3,  4,  5,  6,  7,  8,
					    10, 12, 14, 16, 19, 23, 27, 32, 38, 45, 64};

bool mask[NUM_LEDS];
bool wipe[NUM_LEDS];
CRGB leds[NUM_LEDS];
CRGB buffer[2 * NUM_LEDS];

// language constants
uint8_t n_byte_per_display = 4;         // number of bytes used for each 5 minunte time incriment
uint8_t display_idx;
uint8_t last_min_hack_inc = 0;
uint16_t last_time_inc = 0;

NTPClient timeClient(ntpUDP, "us.pool.ntp.org", 0, 60000); // do not use directly (only through ntp_clock)
NTPClock ntp_clock; // uses timeClient


void getword(int i, uint8_t* out){
  out[0] = pgm_read_byte(WORDS + 3 * i + 1);
  out[1] = pgm_read_byte(WORDS + 3 * i + 2);
  out[2] = pgm_read_byte(WORDS + 3 * i + 3);
}
void setWordMask(bool *mask, uint8_t* word, bool b){ 
 // word = [row, col, len]
  for(int i=0; i < word[2]; i++){
    setPixelMask(mask, word[1], word[0] + i, b);
  }
}

typedef void (*Init)();
typedef void (*Background)();
typedef void (*Transition)(uint16_t last_time_inc, uint16_t time_inc);
typedef struct{
  Init       init;
  Background background;
  Transition transition;
  String     name;
  int        id;
} Display;

typedef Display Displays[];

void blend_to_rainbow();

Display WordDropDisplay = {blend_to_rainbow, rainbow, word_drop, String("Word Drop"), 0};
Display TheMatrixDisplay = {fill_color, fill_color, TheMatrix, String("The Matrix"), 1};
Display WipeAroundDisplay = {blend_to_rainbow, rainbow, wipe_around_transition, String("Wipe Around"), 2};
Display PlaneJaneDisplay = {fill_second_color, fill_second_color, plain_jane, String("Plane Jane"), 3};
//Display FireDisplay = {fill_color, fill_color, plain_jane, String("Fire"), 4};

const int N_DISPLAY = 4;
Display *Display_ps[N_DISPLAY] = {&WordDropDisplay,
				  &TheMatrixDisplay,
				  &WipeAroundDisplay,
				  &PlaneJaneDisplay,
				  //&FireDisplay
};
//Display* CurrentDisplay_p = &WipeAroundDisplay;
Display* CurrentDisplay_p = &TheMatrixDisplay;
//Display* CurrentDisplay_p = &WordDropDisplay;
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

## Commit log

2016-02-18 UlTiM8x8 board layout complete
    [BM03B-SRSS-TB.step, Cap_0805_2012.step, Cap_2917_AVX_E_CASE.step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]
2016-02-18 UlTiM8x8 board layout complete. Gerbers ready. ULTiM_bus mockup
    [Row_A.sch, Row_B.sch, Row_C.sch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]
2016-02-19 UlTiM8x8 board layout complete, Gerbers ready for fab
    [Row_A.sch, Row_B.sch, Row_H.sch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]
2016-02-19 UlTiM_bus layout, gerber complete. Bus accessory for ULTiM8x8
    [ultim8x8_BoM.ods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]
2016-02-19 Adding beggining of pricing breakdown
    [ultim8x8_BoM_seeed.xls]
2016-02-21 Removed digikey pricing from BOM
    [ultim8x8_BoM_seeed.xls]
2016-02-23 UlTiM8x8 fresh layout with new geometry
    [ultim8x8-B.Mask.gbs, ultim8x8-B.Paste.gbp, ultim8x8-B.SilkS.gbo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]
2016-02-24 revised layout, final. Gerbers ready for fab
    [Row_A.sch, Row_B.sch, Row_C.sch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]
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2016-03-17 Power Stud 3D model added in fabricate
    [power_stud.fcstd, power_stud.step]
2016-03-17 45 deg angled layout
    [BM03B-SRSS-TB.step, Cap_0805_2012.step, Cap_2917_AVX_E_CASE.step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]
2016-03-18 angled LED version complete
    [LED_SMD_APA102.step, Row_A.sch, Row_H.sch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]
2016-03-18 added ULTiM8x8 angled LED .step Model
    [BM03B-SRSS-TB.step, Cap_2917_AVX_E_CASE.step, PowerIn_Stud.step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]
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2016-03-19 ULTiM_bus redesign
    [header_1x3_TH_2_54mm.fcstd, ultim8x8.FCStd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]
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2016-03-23 updated to 20mm standoffs
    [ultim8x8_BoM_seeed.xls]
2016-08-10 added module positions files
    [PCB Technology Requirement Format V1 for ultim_bus.xlsx, ultim8x8.kicad_pcb, ultim8x8_BoM_seeed.xls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]
2016-09-08 ultim cube assembly, WIP
    [power_stud.fcstd, power_stud.step, socket_ra_2pin.step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]
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2016-09-10 single panel stand for testing
    [onepanelstand.fcstd, singlepanelstand.stl]
2016-09-10 fix hex recesses in single panel stand
    [onepanelstand.fcstd, singlepanelstand.stl]
2016-09-10 fixed KiCad version issue
    [ultim8x8.kicad_pcb]
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2016-10-15 modified 3D support cube design
    [ultim8x8_cube_face_01.stl, ultim8x8_cube_face_02.fcstd, ultim8x8_cube_face_02.stl]
2016-11-05 Initial commit of Ultim8x8 Feather Board
    [Ultim8x8FeatherBoard.kicad_pcb, Ultim8x8FeatherBoard.sch]
2016-11-26 changing pin strip to sockets for 3D model
    [Ultim8x8FeatherBoard.kicad_pcb]
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2016-12-18 fixing WiFiUdp case sensitivity issue on linux
    [ESP8266_Control.ino]
2016-12-25 belt buckle 3D case
    [ultim8x8_feather_buckle.fcstd, ultim8x8_feather_buckle_v1.stl, ultim8x8_feather_buckle_v2.stl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]
2016-12-31 archived old kicad design in _old folder
    [BM03B-SRSS-TB.step, Cap_0805_2012.step, Cap_2917_AVX_E_CASE.step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]
2016-12-31 board outline changed. upgraded 3 pin headers to 4 pins
    [ultim8x8-B.Mask.gbs, ultim8x8-B.Paste.gbp, ultim8x8-B.SilkS.gbo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]
2016-12-31 rotated 4 pin headers by 45 deg
    [ultim8x8-B.Mask.gbs, ultim8x8-B.Paste.gbp, ultim8x8-B.SilkS.gbo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]
2016-12-31 v2 of Feather carrier board
    [feather_v2-B.Cu.gbl, feather_v2-B.Mask.gbs, feather_v2-B.SilkS.gbo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]
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2017-01-03 feather_v2 added SMD shorting links and extra power switch
    [feather_v2-B.Cu.gbl, feather_v2-B.Mask.gbs, feather_v2-B.SilkS.gbo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]
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2017-01-15 fresh 3D CAD render files
    [LED_SMD_APA102.step, LED_SMD_APA102_01.step, LED_SMD_APA102_02.step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]
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2017-03-19 feather board adapter v3
    [feather_v2.kicad_pcb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]
2017-04-02 ultim_bus_v2 now includes M0 header
    [ultim_bus-B.Cu.gbl, ultim_bus-B.Mask.gbs, ultim_bus-B.SilkS.gbo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]
2017-04-03 added 6 SMD switches to ultim_bus_v2 with pullup resistors
    [SW_smd.step, r_0805.step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]
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2017-04-03 clean up of all kicad project folders
    [feather_v2.kicad_pcb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]
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2017-04-09 CubeClock work in progress ultim8x_assy_idea2
    [ultim8x8_assy01.stl, ultim8x8_cube_face_01.stl, ultim8x8_cube_face_02.stl]
2017-04-09 ultim_bus rev 3 modular, stackable
    [SW_smd.step, r_0805.step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]
2017-04-09 cube rev2 work in progress STL DXF SVG ready for trial
    [cube02_innerface.dxf, cube02_innerface.stl, cube02_laser_2mm35.dxf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]
2017-04-10 corrections and cleanup
    [ultim_bus.kicad_pcb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]
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2017-04-28 minor mods to Belt BuckleCAD
    [ultim8x8_feather_buckle.fcstd]
2017-05-06 Bus Bar PCB added El. Cap, removed short to GND
    [ultim8_bus_BoM_seeed.ods, ultim8_bus_BoM_seeed.xls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]
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2017-05-18 added ultim_bus_conn -- an inter bus connector strip
    [ultim_bus_conn-B.Cu.gbl, ultim_bus_conn-B.Mask.gbs, ultim_bus_conn-B.SilkS.gbo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]
2017-06-13 changed color scheme - black mask, white legend
    [PCB Technology Requirement Format V1 for ultim8x8.xlsx, ultim8x8_BoM_seeed.xls]
2017-06-14 ultim_bus v4 changed switches to thru hole
    [PCB Technology Requirement Format V1 for ultim_bus.xlsx, SW_Switch_SPDT.step, SW_slide_eg1270.step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]
2017-07-24 added SunRiseClock scad files and svgs
    [clock_base.scad, side.dxf]
2017-07-24 more sunriseclock scad files
    [clock_side.scad]
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2017-08-03 bug fixes on SunRiseClock Alarm
    [SunRiseClock.ino]
2017-08-04 Changed FLIP_DISPLAY to use MatrixWidth and MatrixHeight. Added gitignore to prevent publishing credentials.
    [SunRiseClock.ino]
2017-08-04 bug fix to alarm acivation to turn display_clock off
    [SunRiseClock.ino]
2017-08-09 add feather huzzah footprint
    [ultim_bus.sch]
2017-08-10 ultim bus v5 for Huzzah
    [PCB Technology Requirement Format V1 for ultim_bus.xlsx, SW_Switch_SPDT.step, SW_slide_eg1270.step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]
2017-08-10 ultim_bus_v5 swappes S1 and S2
    [ultim_bus.kicad_pcb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]
2017-08-10 modified switch 3d module
    [TactileSwitch_6x6x5mm.step, ultim_bus.kicad_pcb]
2017-08-10 U88 ver2 with extra power / signal mounting holes
    [BM03B-SRSS-TB.step, Cap_0805_2012.step, Cap_2917_AVX_E_CASE.step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]
2017-08-19 U88 connector strip PCB update
    [ultim_bus_conn.kicad_pcb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]
2017-08-28 added eBumper folder in fabricate
    [eBump_bot.stl, eBump_top.stl, u_bus.fcstd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]
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2017-09-17 updated STFU enclosure in eBumper
    [eBump_bot.stl, eBump_top.stl]
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2018-01-19 added ultim_bus snapped off 3D files
    [ultim_bus_snapped.kicad_pcb, ultim_bus_snapped.stp]
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2019-09-01 working on hanger w/ anool
    [hanger.FCStd]
2019-09-02 added 3d printed guide for wall mounting
    [hanger.FCStd, hanger_guide.FCStd]
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2019-10-09 corrected 12 hr format
    [Snake.ino, WyoBean.ino]
2022-12-24 added stripped down clock for hearsh called DesKlok
    [ClockIOT.stl, m3_spacer_6.0mm.stl, spacer.stl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]
